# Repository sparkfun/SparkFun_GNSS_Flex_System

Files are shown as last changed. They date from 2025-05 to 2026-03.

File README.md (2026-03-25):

SparkFun GNSS Flex System
========================================

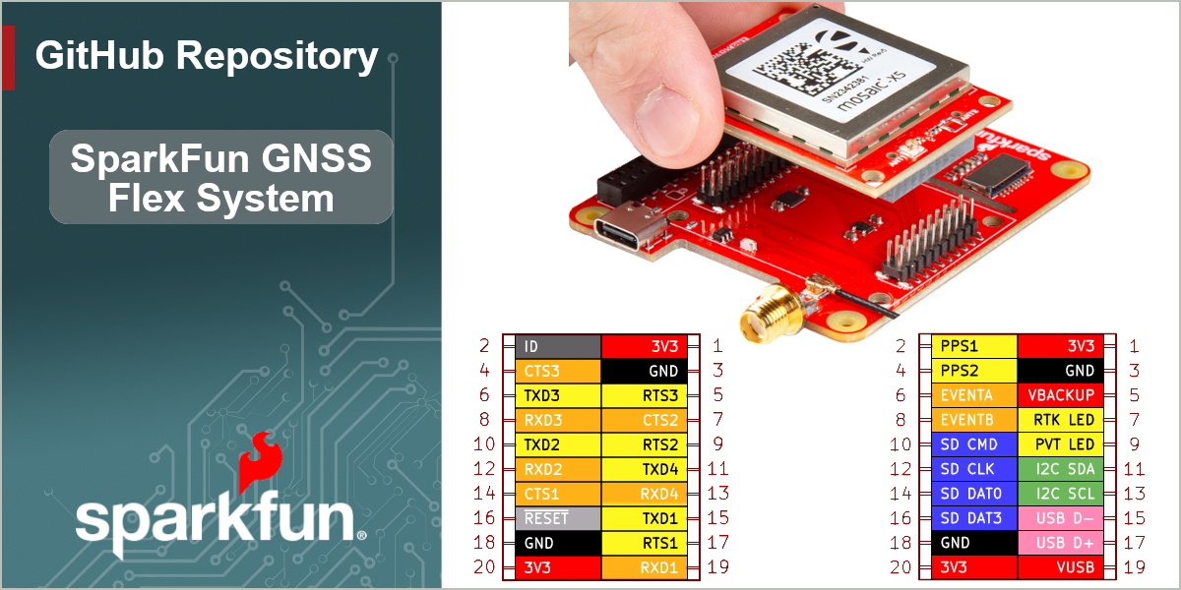
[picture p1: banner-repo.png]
SparkFun GNSS Flex System


Our GNSS Flex system is designed to be modular with two board types:

- *Plug-in Modules*

    Each SparkPNT GNSS Flex module features a different GNSS receiver. These boards breakout the various interfaces of a GNSS receiver to the standardized pin configuration for the female headers of the GNSS Flex system. This allows users to easily repair and upgrade their system's GNSS receiver.

- *Carrier Boards*

    These boards host GNSS Flex modules on the standardized male headers of the GNSS Flex system. Their designs usually have a specific intention; such as a breakout board, Raspberry Pi pHAT, SparkPNT product line, etc.

The entire ecosystem is centered around two 2x10-pin, 2mm pitch headers that mate the two types of boards. A standardized pin layout, keeps the ecosystem pin-compatible for upgrades and allows board to be easily swapped for repairs. Depending on the capabilities of the GNSS receiver, these pins will breakout the USB, UART (x4), I<sup>2</sup>C, and SD card interfaces along with any PPS or event signals of the GNSS receiver.

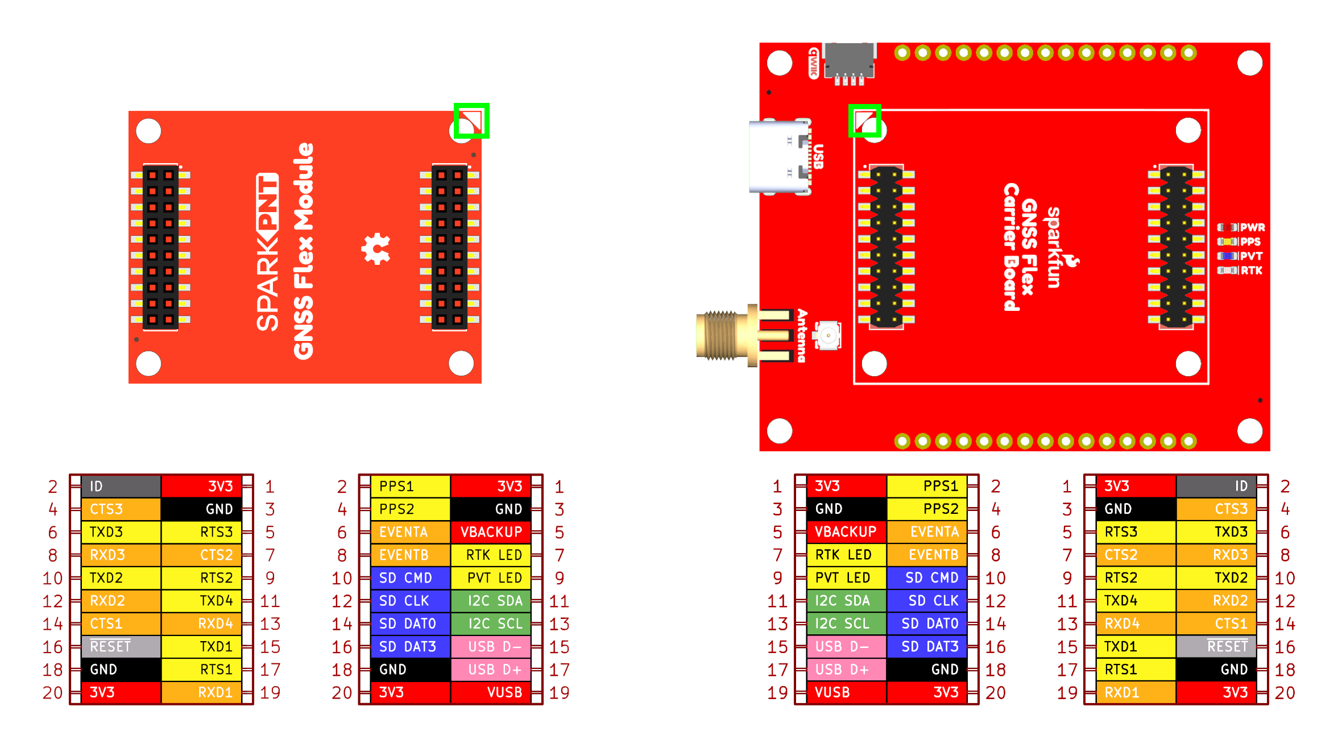
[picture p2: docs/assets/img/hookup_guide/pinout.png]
Pin Layout for the GNSS Flex System


> [!IMPORTANT]
> Depending on the SparkPNT GNSS Flex module, these product will likely require an external antenna:
>
> - Be sure to check out the hookup guide for more information on the GNSS Flex module.
> - Users can also find [GNSS Antennas](https://www.sparkfun.com/gnss/gnss-antennas.html) in our catalog.
>
> Users will have two options for connecting an external GNSS antenna to their GNSS receiver.
>
> - The GNSS Flex modules will usually come with a U.FL connector for an external antenna.
> - For a sturdier connection, a SMA connector on a *carrier board* can utilized. Users can simply jumper the U.FL connectors between the SparkPNT GNSS Flex module and the *carrier board* with a short U.FL cable.

Documentation
--------------

- **[Hookup Guide (mkdocs)](http://docs.sparkfun.com/SparkFun_GNSS_Flex_System/)** - A hookup guide for the entire ecosystem of SparkFun GNSS Flex carrier boards and SparkPNT GNSS Flex modules, hosted by GitHub pages.<br>
   

Repository Contents
-------------------

- **[/docs](/docs/)** - Online documentation files
  - [/assets](/docs/assets/) - Assets files
    - [/component_documentation](/docs/assets/component_documentation/) - Datasheets for GNSS Flex system's standards
    - [/img/hookup_guide](/docs/assets/img/hookup_guide/) - Images for hookup guide documentation
- [/flex_boards](/flex_boards/)
  - /`<name>` - GNSS Flex board *(or associated GitHub submodule)*
    - /docs - Documentation files for the board
      - /assets - Assets files for the board
        - /3d_model - 3D models for the board
        - /board_files - Design files for the board
          - `kicad_files.zip` - KiCad files for the board
          - `schematic.pdf` - Schematic for the board
          - `dimensions.pdf` - Dimensions for the board
        - /component_documentation - Datasheets for the board
        - /img/hookup_guide - Hookup guide images for the board
    - /hardware - Hardware design files (.brd, .sch)
      - /production - Production files

Product Variants
----------------

- GNSS Modules:
  - GNSS Module *(only)*:
    - [GPS-28138](https://www.sparkfun.com/sparkpnt-gnss-flex-module-mosaic-x5.html) - Septentrio mosaic-X5 GNSS Flex module
    - [GPS-28139](https://www.sparkfun.com/sparkpnt-gnss-flex-module-lg290p.html) - Quectel LG290P GNSS Flex module
    - [GPS-29061](https://www.sparkfun.com/sparkpnt-gnss-flex-module-dan-f10n.html) - u-blox DAN-F10N GNSS Flex module
    - [GPS-29362](https://www.sparkfun.com/sparkpnt-gnss-flex-module-zed-x20p.html) - u-blox ZED-X20P GNSS Flex module
    - [GPS-28870](https://www.sparkfun.com/sparkpnt-gnss-flex-module-lg580p.html) - Quectel LG580P GNSS Flex module
  - GNSS Module w/ IMU:
    - [GPS-29469](https://www.sparkfun.com/sparkpnt-gnss-flex-module-lg290p-im19-imu.html) - Quectel LG290P GNSS Flex module + IM19 IMU
    - [GPS-28997](https://www.sparkfun.com/sparkpnt-gnss-flex-module-zed-x20p-im19-imu.html) - u-blox ZED-X20P GNSS Flex module + IM19 IMU
    - [GPS-29457](https://www.sparkfun.com/sparkpnt-gnss-flex-module-mosaic-x5-im19-imu.html) - Septentrio mosaic-X5 GNSS Flex module + IM19 IMU
- Carrier Boards:
  - [GPS-28137](https://www.sparkfun.com/sparkfun-gnss-flex-phat.html) - GNSS Flex pHAT
  - [GPS-28962](https://www.sparkfun.com/sparkfun-gnss-flex-breakout.html) - GNSS Flex Breakout Board
- Kits:
  - pHAT + GNSS Module *(only)*:
    - [GPS-28766](https://www.sparkfun.com/sparkfun-gnss-flex-phat-mosaic-x5.html) - GNSS Flex pHAT w/ the Septentrio mosaic-X5 GNSS Flex module
    - [GPS-28929](https://www.sparkfun.com/sparkfun-gnss-flex-phat-lg290p.html) - GNSS Flex pHAT w/ the Quectel LG290P GNSS Flex module
    - [GPS-29491](https://www.sparkfun.com/sparkfun-gnss-flex-phat-dan-f10n.html) - GNSS Flex pHAT w/ the u-blox DAN-F10N GNSS Flex module
    - [GPS-29887](https://www.sparkfun.com/sparkfun-gnss-flex-phat-zed-x20p.html) - GNSS Flex pHAT w/ the u-blox ZED-X20P GNSS Flex module
    - [GPS-29890](https://www.sparkfun.com/sparkfun-gnss-flex-phat-lg580p.html) - GNSS Flex pHAT w/ the Quectel LG580P GNSS Flex module
  - pHAT + GNSS Module w/ IMU:
    - [GPS-29891](https://www.sparkfun.com/sparkfun-gnss-flex-phat-lg290p-im19-imu.html) - GNSS Flex pHAT w/ the Quectel LG290P GNSS Flex module + IM19 IMU
    - [GPS-29888](https://www.sparkfun.com/sparkfun-gnss-flex-phat-zed-x20p-im19-imu.html) - GNSS Flex pHAT w/ the u-blox ZED-X20P GNSS Flex module + IM19 IMU
    - [GPS-29889](https://www.sparkfun.com/sparkpnt-gnss-flex-phat-mosaic-x5-im19-imu.html) - GNSS Flex pHAT w/ the Septentrio mosaic-X5 GNSS Flex module + IM19 IMU

Version History
---------------

- [r2025-08](https://github.com/sparkfun/SparkFun_GNSS_Flex_System/releases/tag/r2025-08) - Initial Release
- [r2025-08a](https://github.com/sparkfun/SparkFun_GNSS_Flex_System/releases/tag/r2025-08a) - Docs Update
- [r2025-09](https://github.com/sparkfun/SparkFun_GNSS_Flex_System/releases/tag/r2025-09) - Adds DAN-F10N, ZED-X20P, and LG290P (w/ IMU) GNSS Flex modules
- [r2025-09a](https://github.com/sparkfun/SparkFun_GNSS_Flex_System/releases/tag/r2025-09a) - Adds GNSS Flex Breakout board and Docs Updates
- [r2025-10](https://github.com/sparkfun/SparkFun_GNSS_Flex_System/releases/tag/r2025-10) - Adds LG580P GNSS Flex module and Docs Updates
- [r2025-10a](https://github.com/sparkfun/SparkFun_GNSS_Flex_System/releases/tag/r2025-10a) - Adds mosaic-X5 w/ IMU GNSS Flex module
- [r2025-10b](https://github.com/sparkfun/SparkFun_GNSS_Flex_System/releases/tag/r2025-10b) - Docs Updates and ZED-X20P Firmware Update

> [!NOTE]
>
> The format of the release tag  `r[year]-[month][iteration]`
>
> - **year:** `YYYY` Format
> - **month:** `MM` Format
> - **iteration:** Revisions for that month *(i.e. `none`, `a`, `b`, etc.)*

License Information
-------------------

This product is ***open source***!

Please review the [`LICENSE.md`](./LICENSE.md) file for license information.

If you have any questions or concerns about licensing, please contact technical support on our [SparkFun forums](https://community.sparkfun.com/c/community/general-chit-chat/37).

Distributed as-is; no warranty is given.

- Your friends at SparkFun.

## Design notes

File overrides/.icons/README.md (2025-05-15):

.icons directory
====================
This folder should contain branding logos for the product documentation

## General Images
- `sfe.svg` - SparkFun flame logo
- `kicad-primary.svg` - Full KiCad logo

## Directory
- `logo` - Other available logos

## SVG Optimizer
- [Remove meta data from svg](https://jakearchibald.github.io/svgomg/)

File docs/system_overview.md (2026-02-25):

<!-- Import the component -->
<script type="module" src="https://ajax.googleapis.com/ajax/libs/model-viewer/4.0.0/model-viewer.min.js"></script>

## GNSS Flex System
The GNSS Flex system is designed to be modular with a standardized pin layout that keeps the ecosystem pin-compatible for upgrades and allows boards to be easily swapped for repairs. The ecosystem is comprised of two boards, which mate through two 2x10-pin, 2mm pitch headers. The **SparkPNT GNSS Flex modules** function as *plug-in* boards that feature different GNSS receivers. They are designed to mate with **GNSS Flex** *carrier* **boards** for various purposes; such as a breakout board, Raspberry Pi pHAT, SparkPNT product line, etc.

<div class="grid" markdown>

<div markdown>

<figure markdown>
<model-viewer alt="Utilizing the GNSS Flex System" src="../assets/3d_model/GNSS_Flex-Stack_Animation.glb" poster="../assets/img/hookup_guide/animation-attach_module.gif" camera-controls autoplay tone-mapping="neutral" shadow-intensity="2" shadow-softness="0.2" camera-orbit="0deg 70deg 16.7m" field-of-view="18deg" camera-target="2.93m 1.16m -1.29m" style="width: 500px; height: 300px;">
</model-viewer>
<figcaption markdown>Attaching a GNSS Flex module to a GNSS Flex *carrier* board.</figcaption>
</figure>

</div>

<div markdown>

!!! tip "Manipulate 3D Model"
	<article style="text-align: center;" markdown>

	| Controls       | Mouse                    | Touchscreen    |
	| :------------- | :----------------------: | :------------: |
	| Zoom           | Scroll Wheel             | 2-Finger Pinch |
	| Rotate         | ++"Left-Click"++ & Drag  | 1-Finger Drag  |
	| Move/Translate | ++"Right-Click"++ & Drag | 2-Finger Drag  |

	</article>

</div>

</div>

### Board Variants
Below, are two generic examples of a GNSS Flex *module* and *carrier* board.

<div class="grid cards" align="center" markdown>

-   **GNSS Flex Module**

	---

	<model-viewer src="../assets/3d_model/GNSS_Flex-Generic_Module.glb" camera-controls poster="../assets/3d_model/poster-generic_module.png" tone-mapping="neutral" shadow-intensity="2" shadow-softness="0.2" camera-orbit="0deg 75deg 0.1623m" field-of-view="12deg" style="width: 100%; height: 250px;">
	</model-viewer>

	<article style="text-align: center;" markdown>
	[See All GNSS Flex Module Variants](modules.md){ .md-button .md-button--primary }
	</article>

-   **GNSS Flex *"Carrier"* Board**

	---

	<model-viewer src="../assets/3d_model/GNSS_Flex-Carrier_Board.glb" camera-controls poster="../assets/3d_model/poster-carrier_board.png" tone-mapping="neutral" shadow-intensity="2" shadow-softness="0.2" camera-orbit="0deg 75deg 0.1781m" field-of-view="15deg" style="width: 100%; height: 250px;">
	</model-viewer>

	<article style="text-align: center;" markdown>
	[See All GNSS Flex *Carrier* Board Variants](carriers.md){ .md-button .md-button--primary }
	</article>

</div>

### Ecosystem Boards
Below, are all the available GNSS Flex boards in our ecosystem.

<div class="grid cards" markdown>

--8<-- "./modules.md:12:69"

--8<-- "./modules.md:79:176"

--8<-- "./carriers.md:9:36"

</div>

---

## Section Topics
This guide is divided into three sections:

- The **Ecosystem Overview** section describes the overall GNSS Flex system and its primary components.
- The **GNSS Flex Modules** and **Carrier Boards** sections detail each of the specific boards in the ecosystem and how they operate.
- In the **Resources and Support** sections, users can find the design files (KiCad files & schematic), relevant documentation (datasheets, white papers, etc.) and other helpful links on the [Resources page](./resources.md). Lastly, the [Troubleshooting page](./troubleshooting_tips.md) includes helpful tips and instructions for how to receive technical support from SparkFun.

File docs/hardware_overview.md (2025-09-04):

## Board Layout

The boards of the GNSS Flex system have the following features:

<div class="grid" markdown>

<div markdown>

<figure markdown>
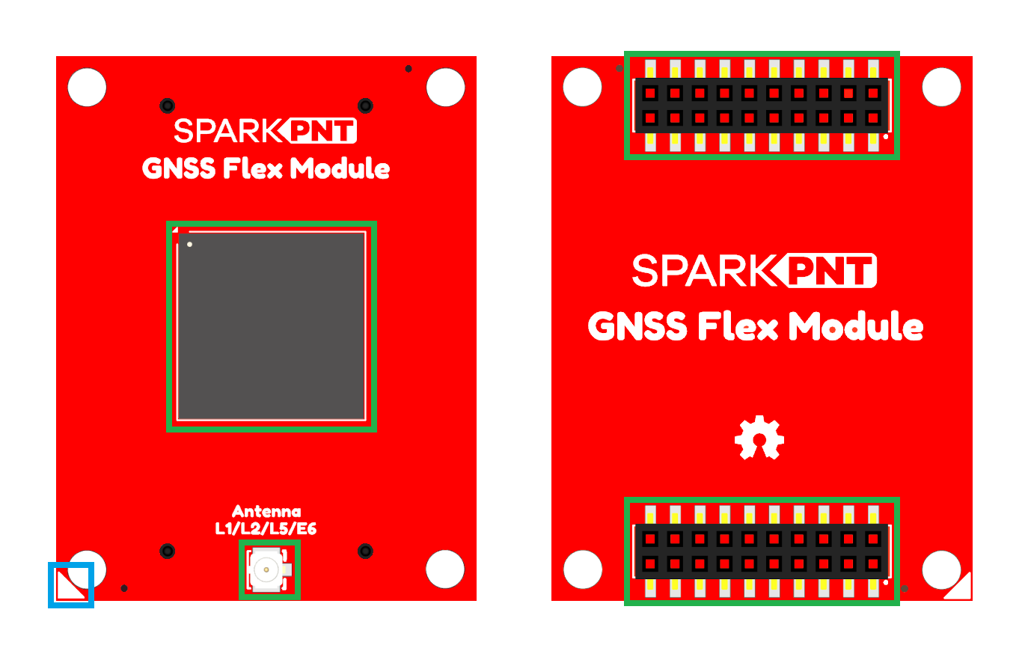
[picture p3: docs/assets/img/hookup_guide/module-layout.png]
Board Layout for the GNSS Flex Module

<figcaption markdown>Layout of the major components on the GNSS Flex modules.</figcaption>
</figure>

1. **Alignment Indicator**
:	A small triangle at the corner of the board is used to indicate the board's alignment on the *carrier* board.
1. **GNSS Receiver**
:	Each variant of the SparkPNT GNSS Flex modules features a unique GNSS receiver.
1. **U.FL Connector**
:	The primary interface for connecting an external GNSS antenna. *(Some GNSS modules may come packaged with a built-in ceramic antenna.)*
1. **GNSS Flex Female Headers**
:	The GNSS Flex system is designed around two 2x10-pin, 2mm pitch headers used mate the two types of boards. A standardized pin layout, keeps the ecosystem pin-compatible for upgrades and allows board to be easily swapped for repairs. Depending on the capabilities of the GNSS receiver, these pins will breakout the USB, UART (x4), I^2^C, and SD card interfaces along with any PPS or event signals of the GNSS receiver.

</div>

<div markdown>

<figure markdown>
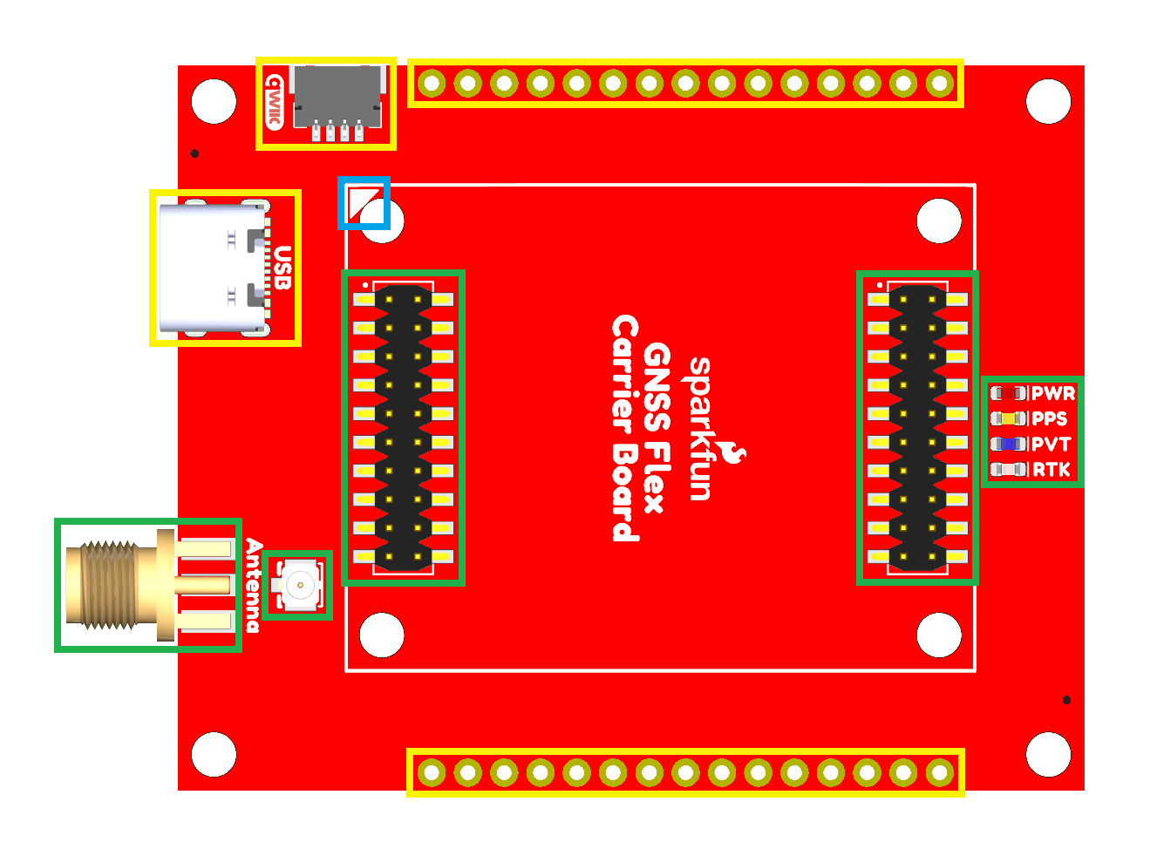
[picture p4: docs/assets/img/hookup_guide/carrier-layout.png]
Board Layout for the carrier board

<figcaption markdown>Layout of the major components of GNSS Flex *carrier* boards.</figcaption>
</figure>

1. **Alignment Indicator**
: A small triangle in the corner of the GNSS Flex system's mating area is used to indicate the alignment for a GNSS Flex module on the *carrier* board.
1. **SMA Connector**
:	A more robust interface for connecting an external GNSS antenna to the GNSS Flex system. The signal is isolated and passed-through to the U.FL connector on the *carrier* board.
1. **U.FL Connector**
:	The signal for this connector is isolated and passed-through to the SMA connector on the *carrier* board. It is used for bridging the external antenna connection of the U.FL connector on GNSS Flex module to the SMA connector on the *carrier* board.
1. **GNSS Flex Male Headers**
:	The *carrier* boards host GNSS Flex modules on the two 2x10-pin, 2mm pitch male headers. A standardized pin layout, keeps the ecosystem pin-compatible for upgrades and allows board to be easily swapped for repairs. Depending on the capabilities of the GNSS receiver, these pins will breakout the USB, UART (x4), I^2^C, and SD card interfaces along with any PPS or event signals of the GNSS receiver.
1. **Status LED**
:	Often *carrier* boards will include status LEDs to indicate the board is powered, the RTK status, a PPS signal, and a GNSS fix.
1. **Other Features**
:	 The designs of the *carrier* boards usually have a specific purpose; therefore, they will often include other features. *(For more details, users can refer to the hardware information of the board they are interested in.)*

</div>

</div>

## Header Pins
The GNSS Flex ecosystem is designed around two 2x10-pin, 2mm pitch headers used mate the two board types. Depending on the capabilities of the GNSS receiver on the GNSS Flex module, these pins breakout the USB, UART (x4), I^2^C, and SD card interfaces along with any PPS or event signals of the GNSS receiver.

<figure markdown>
Pin Layout - Flex Boards
<figcaption markdown>The pin layout of the headers on the GNSS Flex boards; with each board's mating alignment highlighted in green.</figcaption>
</figure>

## U.FL Connectors
Depending on the SparkPNT GNSS Flex module,	users will have two options for connecting an external GNSS antenna to their GNSS receiver.

- The GNSS Flex modules will usually come with a U.FL connector for external antenna.
- For a more robust interface, the GNSS Flex *carrier* boards will usually come with a U.FL connector that is bridged to a nearby SMA edge connector. Users simply need to jumper the U.FL connectors between the SparkPNT GNSS Flex module and the *carrier* board with a short U.FL cable.

<figure markdown>
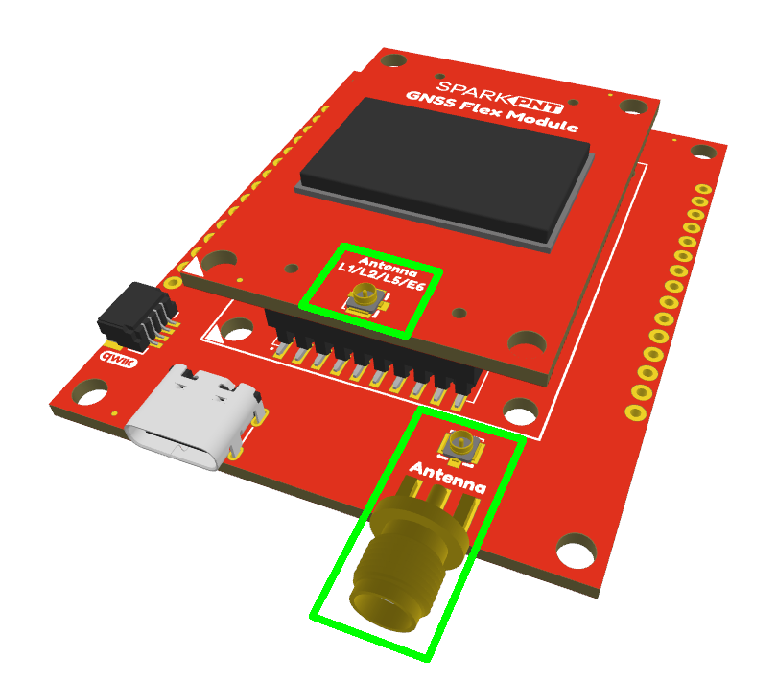
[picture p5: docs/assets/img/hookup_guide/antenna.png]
Antenna connection

<figcaption markdown>Bridging the U.FL connections to utilize the SMA connector on a *carrier* board.</figcaption>
</figure>

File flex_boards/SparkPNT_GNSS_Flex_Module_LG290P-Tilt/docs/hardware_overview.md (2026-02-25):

<article style="text-align: center;" markdown>
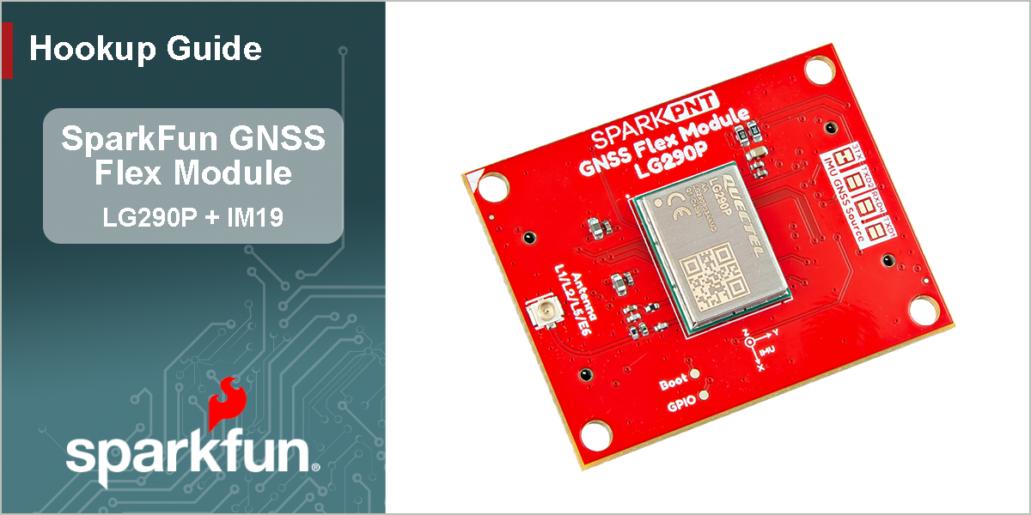
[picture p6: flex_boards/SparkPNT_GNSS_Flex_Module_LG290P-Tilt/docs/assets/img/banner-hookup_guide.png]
Banner

</article>

## Introduction

<div class="grid cards desc" markdown>

-   <a href="https://www.sparkfun.com/sparkpnt-gnss-flex-module-lg290p-im19-imu.html">
	**SparkPNT GNSS Flex Module - LG290P & IM19 IMU**<br>
	**SKU:** GPS-29469

	---

	<figure markdown>
	Product Thumbnail
	</figure></a>

	<article style="text-align: center;" markdown>
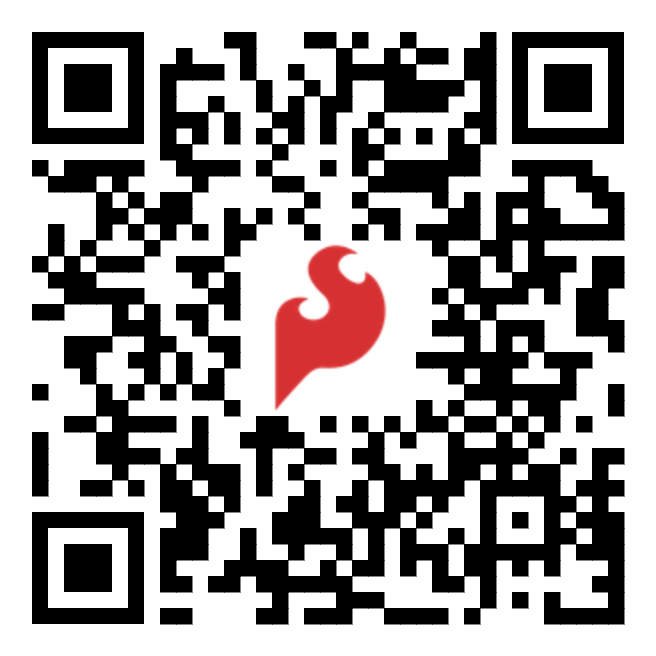
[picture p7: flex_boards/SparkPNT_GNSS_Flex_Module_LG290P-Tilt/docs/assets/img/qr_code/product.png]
QR code to product page
	
	[Purchase from SparkFun :fontawesome-solid-cart-plus:{ .heart }](https://www.sparkfun.com/sparkpnt-gnss-flex-module-lg290p-im19-imu.html){ .md-button .md-button--primary }
	</article>

	??? info "Tilt Compensation"
		The IM19 attitude module from Feyman (FMI) fuses MEMS IMU sensor data and GNSS RTK positioning to deliver high-precision attitude compensated measurements, with roll and pitch accurate to within 0.05 degrees. This kind of superb accuracy has widespread uses in industrial applications such as tilt RTK surveys (where RTK poles need not be held straight vertical as the IM19 can calculate a virtual digital level at any tilt angle), agriculture machine automation, and dead reckoning.

		When configured, fed with the LG290P Pulse-Per-Second signal and NMEA GGA, RMC, and GST messages; once calibrated, the IM19 will output proprietary NMEA messages containing the compensated position and roll, pitch and yaw. By default, the LG290P `COM3` `TX` is linked to the IM19 `UART2` `RX` to carry the required NMEA messages. However, this can be changed via jumper links on the Flex Module, if necessary.

-   SparkPNT GNSS Flex modules are plug-in boards featuring different GNSS receivers. They are designed to be easily swapped for repairs and pin-compatible for upgrades. The boards have two 2x10-pin, 2mm pitch female headers connecting to carrier boards. For the LG290P GNSS receiver, these pins will break out the UART (x2) and I^2^C* interfaces, along with the PPS and event signals using a standardized pinout. Additionally, these pins break out the two UART interfaces of the IM19 IMU.

	This SparkPNT GNSS Flex module combines the Quectel LG290P GNSS receiver with the IM19 Inertial Measurement Unit for tilt compensation or dead reckoning. The LG290P module is a quad-band, multi-constellation, high-precision, RTK GNSS receiver. The module can simultaneously receive signals from the `L1`, `L2`, `L5`, and `L6`/`E6` frequency bands of the GPS, GLONASS, Galileo, BDS, QZSS, and NavIC GNSS constellations. In addition, the module supports SBAS augmentation systems (WASS, EGNOS, BDSBAS, MSAS, GAGAN, and SDCM), PPP services* (BDS PPP-B2b, QZSS CLAS, MADOCA-PPP, and Galileo HAS), RTCM, and RTK corrections for precision navigation with a fast convergence time and reliable performance.

	The built-in NIC anti-jamming unit provides professional-grade interference signal detection and elimination algorithms, effectively mitigating multiple narrow-band interference sources and significantly improving signal reception performance in complex electromagnetic environments. Additionally, the embedded algorithms ensure reliable positioning in complex scenarios such as urban environments and deep tree cover.

	!!! warning "Features Under Development"
		- **I^2^C/SPI** - Currently, only the UART interface is supported by the module.
		- **PPP Services** - Corrections for some of the PPP services have not been implemented.

</div>

## :material-folder-cog: Design Files

<!-- Import the component -->

<script type="module" src="https://ajax.googleapis.com/ajax/libs/model-viewer/4.0.0/model-viewer.min.js"></script>

<div class="grid cards desc" markdown>

-   :kicad-primary:{ .enlarge-logo } Design Files

	---

	- :fontawesome-solid-file-pdf: [Schematic](./assets/board_files/schematic.pdf)
	- :material-folder-zip: [KiCad Files](./assets/board_files/kicad_files.zip)
	- :material-rotate-3d: [STEP File](./assets/3d_model/cad_model.step)
	- :fontawesome-solid-file-pdf: [Board Dimensions](./assets/board_files/dimensions.pdf):
		- 1.75" x 1.25" (44.45mm x 31.75mm)

-   <!-- Boxes in tabs -->

	=== "3D Model"
		<article style="text-align: center;" markdown>
		<model-viewer src="../assets/3d_model/web_model.glb" camera-controls poster="../assets/3d_model/poster.png" tone-mapping="neutral" shadow-intensity="2" shadow-softness="0.2" camera-orbit="90deg 75deg 0.103m" field-of-view="25.11deg" style="width: 100%; height: 450px;">
		</model-viewer>

		[Download the `*.step` File](./assets/3d_model/cad_model.step "Click to download"){ .md-button .md-button--primary width="250px" }

		</article>

		???+ tip "Manipulate 3D Model"
			<article style="text-align: center;" markdown>

			| Controls       | Mouse                    | Touchscreen    |
			| :------------- | :----------------------: | :------------: |
			| Zoom           | Scroll Wheel             | 2-Finger Pinch |
			| Rotate         | ++"Left-Click"++ & Drag  | 1-Finger Drag  |
			| Move/Translate | ++"Right-Click"++ & Drag | 2-Finger Drag  |

			</article>

	=== "Dimensions"
		<article style="text-align: center;" markdown>
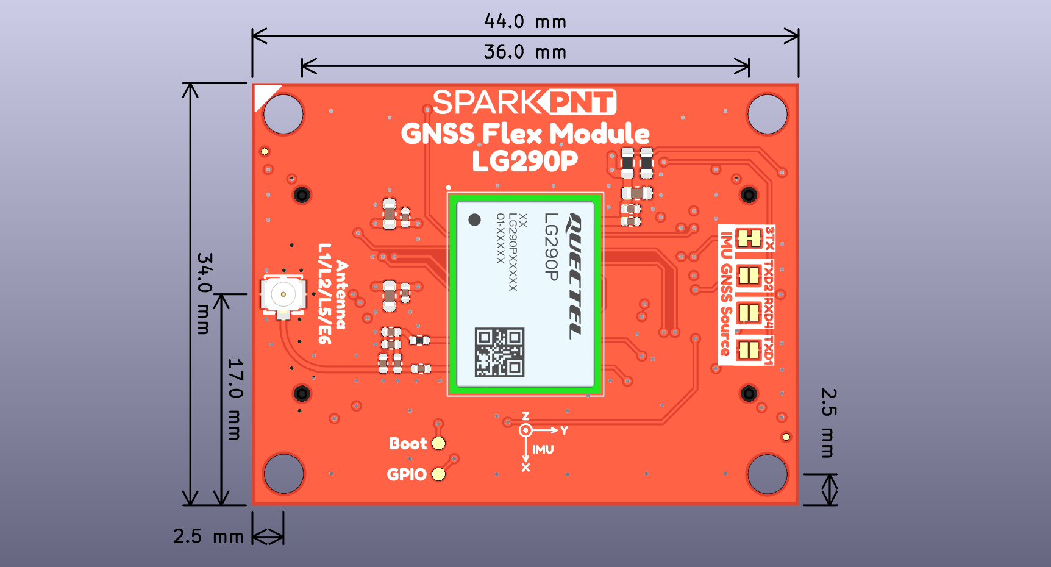
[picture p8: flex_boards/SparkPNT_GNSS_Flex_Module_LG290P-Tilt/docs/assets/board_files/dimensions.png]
Board Dimensions
		
		<figcaption markdown>Dimensions of the LG290P GNSS Flex module.</figcaption>
		</article>

		???+ tip "Need more measurements?"
			For more information about the board's dimensions, users can download the [KiCad files](./assets/board_files/kicad_files.zip) for this board. These files can be opened in KiCad and additional measurements can be made with the measuring tool.

			!!! info ":octicons-download-16:{ .heart } KiCad - Free Download!"
				KiCad is free, open-source [CAD]("computer-aided design") program for electronics. Click on the button below to download their software. *(\*Users can find out more information about KiCad from their [website](https://www.kicad.org/).)*

				<article style="text-align: center;" markdown>
				[Download :kicad-primary:{ .enlarge-logo }](https://www.kicad.org/download/ "Go to downloads page"){ .md-button .md-button--primary width="250px" }
				</article>

			???+ info ":straight_ruler: Measuring Tool"
				This video demonstrates how to utilize the dimensions tool in KiCad, to include additional measurements:

				<article class="video-500px" style="text-align: center; margin: auto;" markdown>
				<iframe src="https://www.youtube.com/embed/-eXuD8pkCYw" title="KiCad Dimension Tool" frameborder="0" allow="accelerometer; autoplay; clipboard-write; encrypted-media; gyroscope; picture-in-picture" allowfullscreen></iframe>
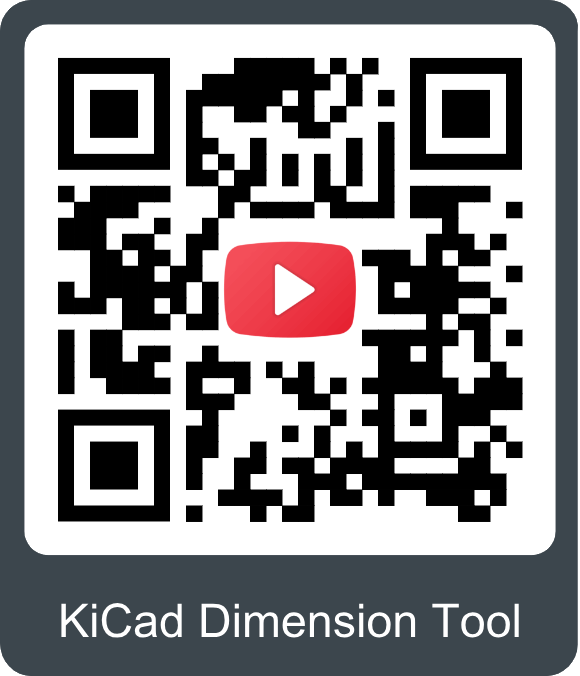
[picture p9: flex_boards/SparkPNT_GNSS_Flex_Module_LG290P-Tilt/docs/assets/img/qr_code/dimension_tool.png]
QR code to play video
				
				</article>

</div>

## Board Layout
The GNSS Flex system is designed around two 2x10-pin, 2mm pitch headers used mate the two types of boards. A standardized pin layout, keeps the ecosystem pin-compatible for upgrades and allows board to be easily swapped for repairs. Depending on the capabilities of the GNSS receiver, these pins will breakout the USB, UART (x4), I^2^C, and SD card interfaces along with any PPS or event signals of the GNSS receiver.

The LG290P GNSS Flex module has the following features:

<div class="grid" markdown>

<div markdown>

<figure markdown>
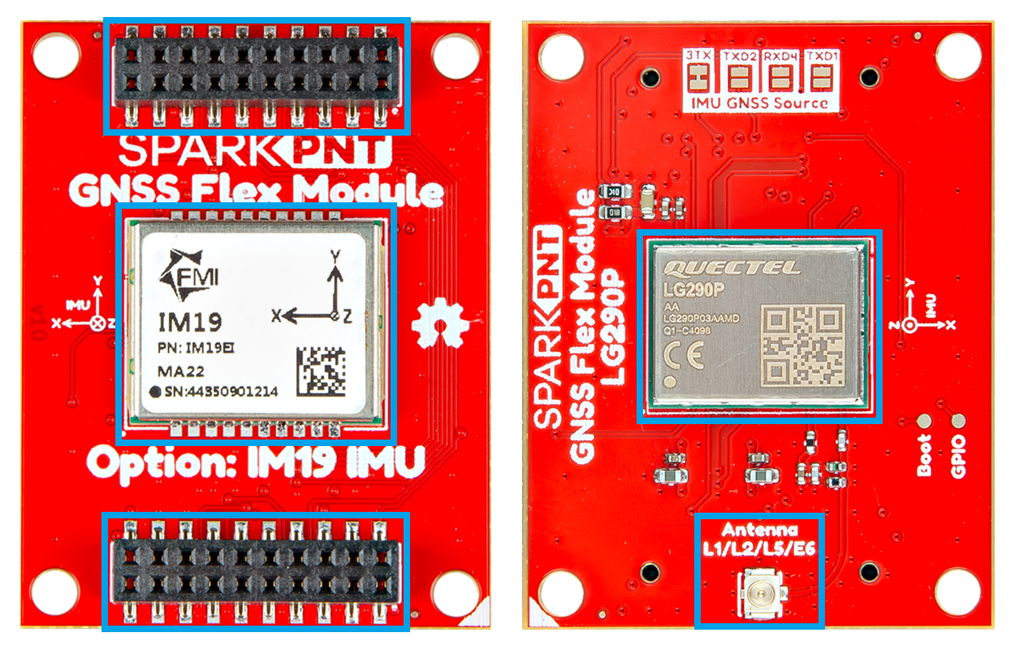
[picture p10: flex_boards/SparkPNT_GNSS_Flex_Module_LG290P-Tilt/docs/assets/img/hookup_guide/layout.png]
Layout

<figcaption markdown>Layout of the major components on the LG290P GNSS Flex module.</figcaption>
</figure>

</div>

<div markdown>

1. **LG290P GNSS Receiver**
:	The Quectel LG290P GNSS receiver
1. **GNSS Flex Headers**
:	Two sets of 2x10 pin, 2mm pitch female headers for connecting a GNSS Flex module to *carrier boards*
1. **IM19 IMU** *(optional)*
:	An optional Feyman IM19 attitude module to provide tilt compensation in surveying applications
1. **`Antenna L1/L2/L5/E6` U.FL Connector**
:	An U.FL connector for attaching an external GNSS antenna

</div>

</div>

## LG290P GNSS Receiver
One of the centerpieces of the GNSS Flex module, is the [LG290P GNSS receiver](./assets/component_documentation/quectel_lg290p03_hardware_design_v1-1.pdf) from [Quectel](https://www.quectel.com/). The LG290P is a low-power, multi-band, multi-constellation GNSS receiver capable of delivering centimeter-level precision at high update rates. The built-in NIC anti-jamming unit provides professional-grade interference signal detection and elimination algorithms, which effectively mitigate against multiple narrow-band interference sources and significantly improves the signal reception performance in complex electromagnetic environments. With its performance advantages of high-precision and power consumption, this board is an ideal choice for high-precision navigation applications, such as intelligent robots, UAVs, precision agriculture, mining, surveying, and autonomous navigation.

<div class="grid cards" markdown>

<div style="text-align: center;" markdown>

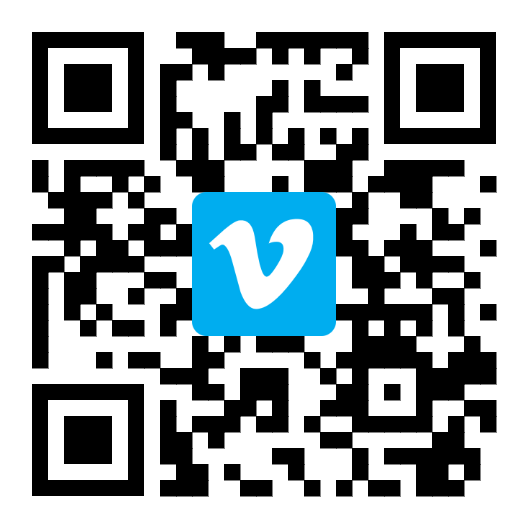
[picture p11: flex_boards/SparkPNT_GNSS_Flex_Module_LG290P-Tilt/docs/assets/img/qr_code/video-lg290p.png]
QR code to product video


<article class="video-500px" style="margin: auto;" markdown>
<iframe src="https://player.vimeo.com/video/1000742664?dnt=1&amp;app_id=122963" title="Quectel: Product Intro for LG290P GNSS Receiver" frameborder="0" allow="accelerometer; autoplay; clipboard-write; encrypted-media; gyroscope; picture-in-picture" allowfullscreen></iframe>
</article>

</div>

-   <figure markdown>
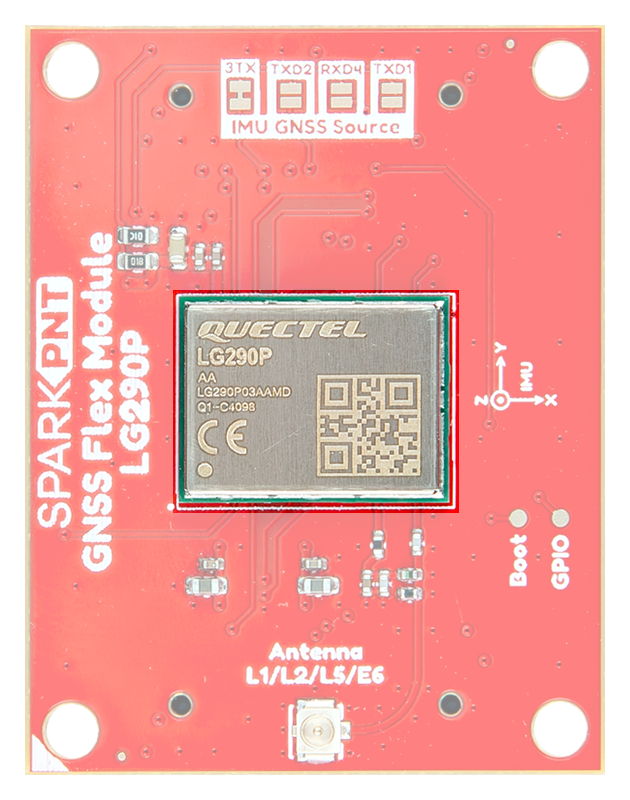
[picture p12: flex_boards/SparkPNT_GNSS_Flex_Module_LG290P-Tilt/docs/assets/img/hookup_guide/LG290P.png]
LG290P GNSS receiver
	
	<figcaption markdown>The LG290P GNSS receiver on the LG290P GNSS Flex module.</figcaption>
	</figure>

</div>

<div class="grid" markdown>

<div markdown>

**Features:**

- Supply Voltage: **3.15–3.45V**
- Tracking Channels: 1040
- Concurrent signal reception: 5 + QZSS
	- `L1`, `L2`, `L5`, `E6` frequency bands
- Sensitivity:
	- Acquisition: -146dBm
	- Tracking: -160dBm
	- Reacquisition: -155dBm
- Antenna Power: External or Internal
- GNSS Constellations and SBAS Systems:
	- **USA:** GPS + WASS
	- **Russia:** GLONASS + SDCM
	- **EU:** Galileo + EGNOS
	- **China:** BDS + BDSDAS
	- **Japan:** QZSS + MSAS
	- **India:** NavIC + GAGAN
- Accuracy of 1PPS Signal: 5ns *(RMS)*
- Update Rate:
	- Default: 10Hz
	- Max: 20Hz

</div>

<div markdown>

<br>

- Time to First Fix *(without AGNSS)*:
	- Cold Start: 28s
	- Warm Start: 28s
	- Hot Start: 1.7s
- RTK Convergence Time: 5s
- Dynamic Performance:
	- Maximum Altitude: 10000m
	- Maximum Velocity: 490m/s
	- Maximum Acceleration: 4g
- Built-in NIC anti-jamming unit
- Interfaces
	- UART (x3)
		- Baud Rate: 9600–3000000bps
			- **Default:** 460800bps
		- Protocol: `NMEA 0183`/`RTCM 3.x`
	- SPI[^1] (x1)
	- I^2^C[^1] (x1)
- Operating temperature: -40&deg;C to +85&deg;C

</div>

</div>

[^1]:
	!!! warning "Feature Under Development"
		Currently, only the UART interface is supported by the module. Support for the **I^2^C** and **SPI** interfaces are still under development.

### Power Consumption
The power consumption of the LG290P GNSS receiver depends on the GNSS signals enabled and the positioning mode.

<div class="grid" markdown>

<article style="text-align: center;" markdown>

| Mode | Power (mW) | Current (mA) |
| :--- | :---: | :---: |
| Acquisition | 300.3 | 91 |
| Tracking | 300.3 | 91 |
| Backup | 39.6 | 0.012 |

</article>

<div markdown>

!!! info "Power Modes"

	**Acquisition:**
	:   Module searches for satellites and to determine visible satellites, coarse frequency, and the code phase of satellite signals

	**Tracking:**
	:   Once acquisition is completed, the module tracks satellites and demodulates the navigation data from specific satellites

	**Backup Mode:**
	:   Reduces power consumption. Only backup domain is active and keeps track of time.

</div>

</div>

### Frequency Bands
The LG290P module is a multi-band, multi-constellation GNSS receiver. Below, is a chart illustrating the frequency bands utilized by all the global navigation satellite systems; along with a list of the frequency bands and GNSS systems supported by the LG290P GNSS receiver.

<figure markdown>
GNSS frequency bands (https://www.tallysman.com/app/uploads/2021/07/Tallysman-GNSS-Frequencies-v8.0_Chart-1-1024x425.png "Click to enlarge")
<figcaption markdown>Frequency bands of the global navigation satellite systems. (Source: [Tallysman](https://www.tallysman.com/gnss-constellations-radio-frequencies-and-signals/))</figcaption>
</figure>

<div class="grid" markdown>

<div markdown>

**Supported Frequency Bands:**

- GPS: `L1 C/A`, `L1C`[^2], `L5`, `L2C`
- GLONASS: `L1`, `L2`
- Galileo: `E1`, `E5a`, `E5b`, `E6`
- BDS: `B1I`, `B1C`, `B2a`, `B2b`, `B2I`, `B3I`
- QZSS: `L1 C/A`, `L1C`[^2], `L5`, `L2C`
- NavIC: `L5`
- SBAS: `L1 C/A`
- L-band PPP[^3]:
	- PPP: `B2b`
	- QZSS: `L6`
	- Galileo HAS: `E6`

</div>

<div markdown>

**Supported GNSS Constellations:**

- GPS (USA)
- GLONASS (Russia)
- Galileo (EU)
- BDS (China)
- QZSS (Japan)
- NavIC (India)

**Supported SBAS Systems:**

- WASS (USA)
- SDCM (Russia)
- EGNOS (EU)
- BDSBAS (China)
- MSAS (Japan)
- GAGAN (India)

</div>

</div>

[^2]:
	!!! warning "Feature Under Development"
		Support for the `L1C` frequency band has not been implemented.
[^3]:
	!!! warning "Feature Under Development"
		Corrections for some of the PPP services have not been implemented.

!!! info
	For a comparison of the frequency bands supported by the LG290P GNSS receivers, refer to sections **1.2**, **1.5**, and **1.6** of the [hardware design manual](./assets/component_documentation/quectel_lg290p03_hardware_design_v1-1.pdf).

	??? info "What are Frequency Bands?"
		A [frequency band](https://en.wikipedia.org/wiki/Frequency_band) is a section of the [electromagnetic spectrum](https://en.wikipedia.org/wiki/Electromagnetic_spectrum), usually denoted by the range of its upper and lower limits. In the [radio spectrum](https://en.wikipedia.org/wiki/Radio_spectrum), these frequency bands are usually regulated by region, often through a government entity. This regulation prevents the interference of RF communication; and often includes major penalties for any interference with critical infrastructure systems and emergency services.

		<figure markdown>
		GNSS frequency bands (https://gssc.esa.int/navipedia/images/c/cf/GNSS_All_Signals.png "Click to enlarge")
		<figcaption markdown>Frequency bands of the global navigation satellite systems. (Source: [ESA](https://gssc.esa.int/navipedia/index.php?title=File:GNSS_All_Signals.png "European Space Agency"))</figcaption>
		</figure>

		However, if the various GNSS constellations share similar frequency bands, then how do they avoid interfering with one another? Without going too far into detail, the image above helps illustrate some of the characteristics, specific to the frequency bands of each system. With these characteristics in mind, along with other factors, the chart can help users to visualize how multiple GNSS constellations might co-exist with each other.

		For more information, users may find these articles of interest:

		- [GNSS signal](https://gssc.esa.int/navipedia/index.php/GNSS_signal)
		- [GPS Signal Plan](https://gssc.esa.int/navipedia/index.php?title=GPS_Signal_Plan)
		- [GLONASS Signal Plan](https://gssc.esa.int/navipedia/index.php?title=GLONASS_Signal_Plan)
		- [GALILEO Signal Plan](https://gssc.esa.int/navipedia/index.php?title=GALILEO_Signal_Plan)

### Position Accuracy

<div class="grid" markdown>

<div markdown>

The accuracy of the position reported from the LG290P GNSS receiver, can be improved based upon the correction method being employed. Currently, [RTK](https://en.wikipedia.org/wiki/Real-time_kinematic_positioning "Real-Time Kinematic") corrections provide the highest level of accuracy; however, users should be aware of certain limitations of the system:

- RTK technique requires real-time correction data from a reference station or network of base stations.
	- RTK corrections usually come from RTCM messages that are signal specific *(i.e. an RTK network may only provide corrections for specific signals; only `E5b` and not `E5a`)*.
- The range of the base stations will vary based upon the method used to transmit the correction data.
- The reliability of RTK corrections are inherently reduced in [multipath environments](https://en.wikipedia.org/wiki/Multipath_propagation).

</div>

<div markdown>

<article style="text-align: center;" markdown>

| Correction Method | Horizontal | Vertical | Velocity |
| :--- | :---: | :---: | :---: |
| Standalone | 0.7m<br>~2.3' | 2.5m<br>~8.2' | 3cm/s (0.108kph)<br>~1.2in/s (0.067mph) |
| RTK | **0.8cm** *(+1ppm)*<br>~0.3" | 1.5cm *(+1ppm)*<br>~.6" | |

</article>

??? warning "IM19 Attitude Module"
	When configured and calibrated, the IM19 attitude module can fuses IMU sensor and GNSS RTK positioning data to deliver compensated position. The accuracy, displayed in the table below, should also be considered when implemented.

	<article style="text-align: center;" markdown>

	| Tilt Angle       | Accuracy |
	| :--------------: | :------: |
	| 0&deg; - 30&deg; | 1cm      |
	| <60&deg;         | 2cm      |

	</article>

</div>

</div>

??? info "RTK Corrections"
	To understand how RTK works, users will need a more fundamental understanding of the signal error sources.

	<div class="grid cards" markdown align="center">

	-   <a href="https://www.sparkfun.com/news/7533">
		<figure markdown>
		Tutorial Thumbnail
		</figure>

		---

		**Real-Time Kinematics Explained**</a>

	-   <a href="https://www.sparkfun.com/news/7138">
		<figure markdown>
		Tutorial Thumbnail
		</figure>

		---

		**What is Correction Data?**</a>

	-   <a href="https://www.septentrio.com/en/learn-more/insights/gnss-corrections-demystified">
		<figure markdown>
		Tutorial Thumbnail
		</figure>

		---

		**GNSS Corrections Demystified**</a>

	</div>

!!! tip
	For the best performance, we highly recommend that users configure the module to utilize/provide RTK corrections with a compatible L1/L2/L5/L6 GNSS antenna and utilize a low-loss cable.

## IM19 IMU *(Optional)*
The other centerpiece of the GNSS Flex module is the [IM19 attitude module](../assets/component_documentation/IM19EI_v1.4.1.pdf) from [Feyman Inc.](http://feymani.com/en/), which fuses MEMS sensor and GNSS RTK positioning data to deliver high-precision attitude measurement, with roll and pitch accurate to within 0.05 degrees. This kind of superb accuracy has widespread uses in industrial applications such as tilt RTK surveys (where RTK poles need not be held straight vertical as the IM19 can calculate a virtual digital level at any tilt angle), agriculture machine automation, and dead reckoning.

When configured, fed with the LG290P Pulse-Per-Second signal and NMEA GGA, RMC, and GST messages; once calibrated, the IM19 will output proprietary NMEA messages containing the compensated position and roll, pitch and yaw. By default, the LG290P `COM3` `TX` is linked to the IM19 `UART2` `RX` to carry the required NMEA messages. However, this can be changed via jumper links on the Flex Module, if necessary.

<div class="grid cards" markdown>

<div style="text-align: center;" markdown>

<article class="video-500px" style="text-align: center; margin: auto;" markdown>
<iframe src="https://global.feymani.com/files/im19.mp4" type="video/mp4" title="Feyman Inc - Product Intro for IM19 Module" frameborder="0" allow="accelerometer; clipboard-write; encrypted-media; gyroscope; picture-in-picture" allowfullscreen></iframe>
</article>

</div>

-   <figure markdown>
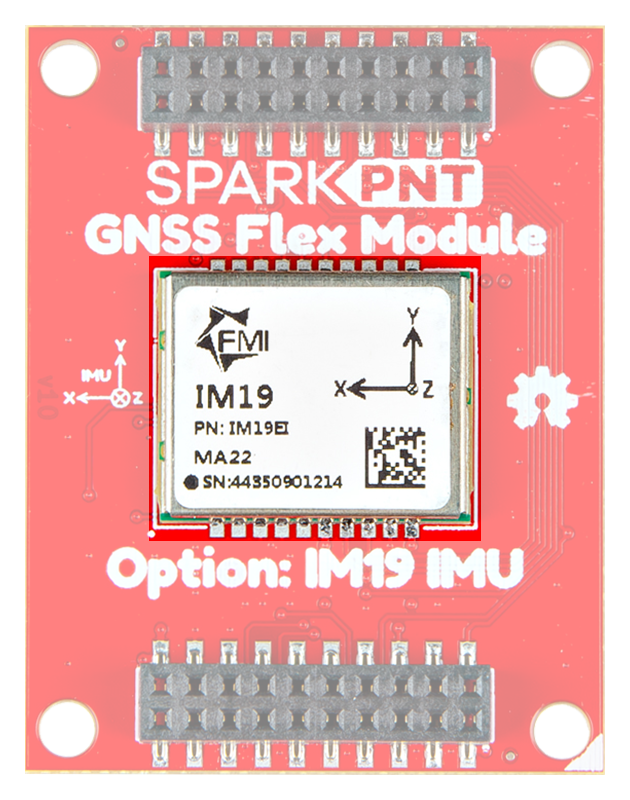
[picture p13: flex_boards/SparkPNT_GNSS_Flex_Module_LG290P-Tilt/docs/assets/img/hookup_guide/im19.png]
IM19 attitude module
	
	<figcaption markdown>The IM19 attitude module on the LG290P GNSS Flex module.</figcaption>
	</figure>

</div>

<div class="grid" markdown>

<div markdown>

**Features:**

- Self-calibration Technique
- Initialization: <2s
- Power: 0.33W
- Data Rate: 100Hz
- Attitude Accuracy: &plusmn;0.05&deg; *(Pitch/Roll)*
- Heading Accuracy: &plusmn;0.5&deg; *(Yaw)*

</div>

<div markdown>

<br>

- Gyroscope
	- Bias Stability: &plusmn;0.2&deg;/s
	- Range: &plusmn;1000&deg;/s
- Accelerometer
	- Bias Stability: &plusmn;5mg
	- Range: &plusmn;8g

</div>

</div>

!!! info
	Please refer to the hookup guide linked below, for the operation of the IM19 attitude module in tilt-compensation applications:

	<article style="text-align: center;" markdown>
	[IM19 Hookup Guide - Tilt Compensation](../im19.md "Click to navigate"){ .md-button .md-button--primary }
	</article>

### Position Accuracy
When configured and calibrated, the IM19 attitude module can fuses its IMU sensor data with the received GNSS RTK positioning data to deliver a tilt compensated position.

<article style="text-align: center;" markdown>

| Tilt Angle | Accuracy |
| :---: | :---: |
| 0&deg; - 30&deg; | 1cm |
| <60&deg; | 2cm |

</article>

??? warning "LG290P GNSS Receiver"
	The accuracy of the position reported from the LG290P GNSS receiver, can be improved based upon the correction method being employed. Currently, [RTK](https://en.wikipedia.org/wiki/Real-time_kinematic_positioning "Real-Time Kinematic") corrections provide the highest level of accuracy. Its accuracy, displayed in the table below, should also be considered when implemented.

	<article style="text-align: center;" markdown>

	| Correction Method | Horizontal                   | Vertical                | Velocity                                |
	| :---------------- | :--------------------------: | :---------------------: | :-------------------------------------: |
	| Standalone        | 0.7m<br>~2.3'                | 2.5m<br>~8.2'           | 3cm/s (0.108kph)<br>~1.2in/s (0.067mph) |
	| RTK               | **0.8cm** *(+1ppm)*<br>~0.3" | 1.5cm *(+1ppm)*<br>~.6" |                                         |

	</article>

## GNSS Flex Headers
The GNSS Flex system is designed around two 2x10-pin, 2mm pitch headers used mate the two types of boards. A standardized pin layout, keeps the ecosystem pin-compatible for upgrades and allows boards to be easily swapped for repairs. For the LG290P GNSS receiver, these pins will breakout the UART (x2) and I^2^C interfaces along with a PPS, event, and LED status indication signals from the GNSS receiver. Additionally, these pins break out the two UART interfaces of the IM19 attitude module.

<div class="grid" markdown>

<div markdown>

<figure markdown>
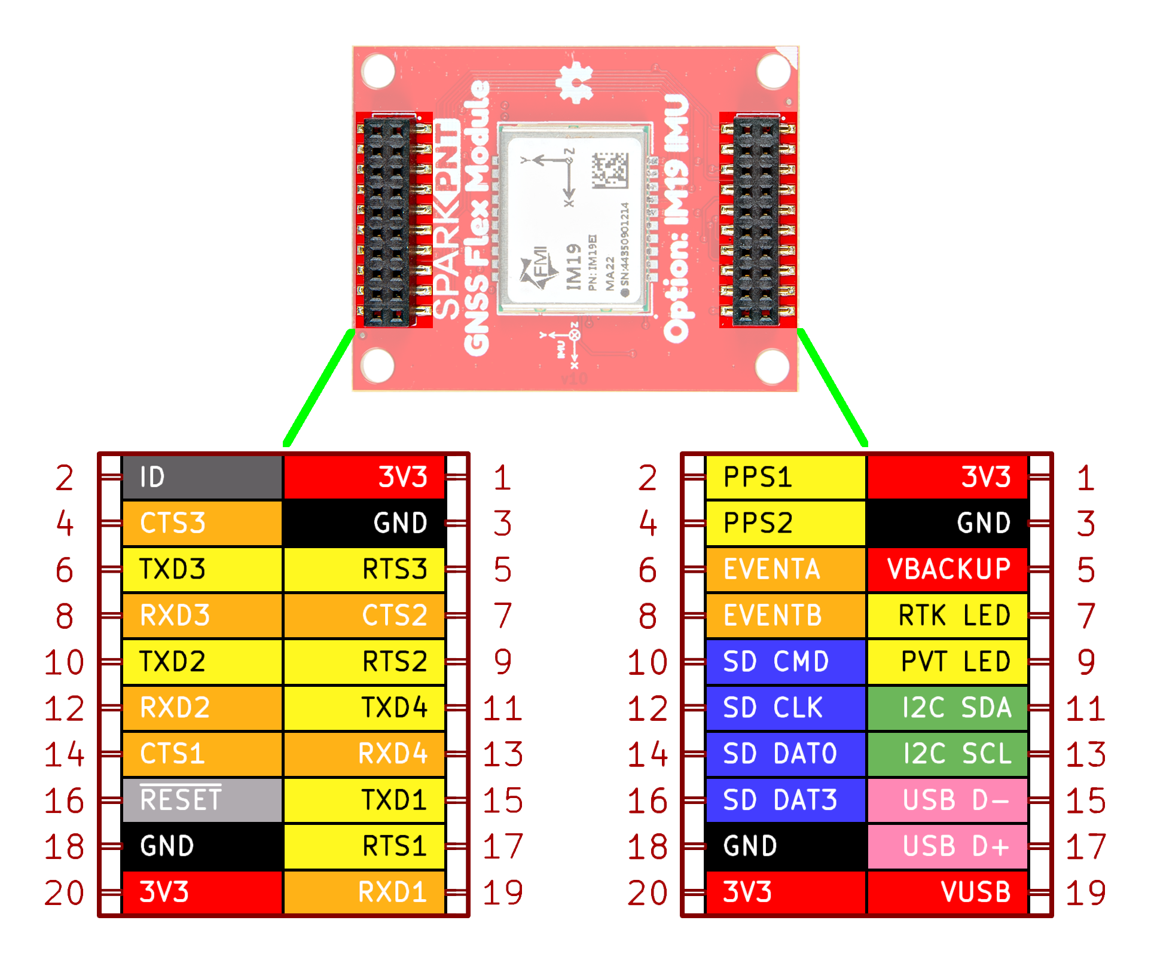
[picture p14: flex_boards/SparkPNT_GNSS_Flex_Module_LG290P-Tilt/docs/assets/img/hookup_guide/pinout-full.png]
Peripherals and I/O pins

<figcaption markdown>The peripherals and I/O pins on the LG290P GNSS Flex module.</figcaption>
</figure>

</div>

<div markdown>

Below, are the features that are available from the LG290P GNSS receiver.

<article class="annotate" markdown>

**Supported Interfaces:**

- UART (x2) (1)
- ~~SPI[^1]~~
- I^2^C[^1]
- Event Trigger
- Timing Signal
- RTK Signal

</article>

1. One of the three UART ports is piped to the IM19 module

Below, are the features that are available from the IM19 attitude module.

<article class="annotate" markdown>

**Supported Interfaces:**

- UART (x2)
- Timing Signal (1)

</article>

1. The timing signal comes from the LG290P GNSS receiver

</div>

</div>

=== "UART Ports"
	The headers of the GNSS Flex system supports up to four UART ports. On this GNSS Flex module, these are connected to both the GNSS receiver and IM19 attitude module.

	<figure markdown>
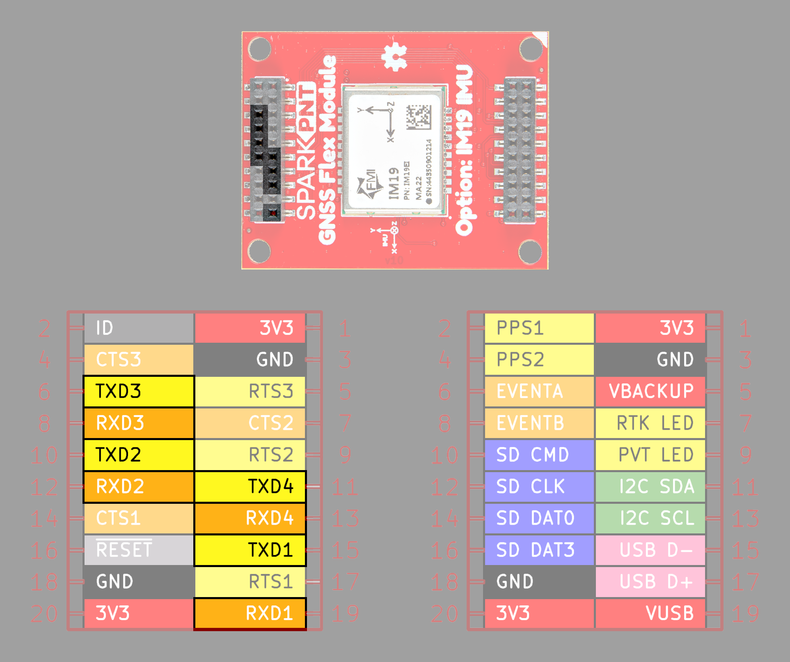
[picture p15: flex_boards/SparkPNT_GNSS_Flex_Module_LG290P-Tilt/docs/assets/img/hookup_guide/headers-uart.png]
UART interface
	
	<figcaption markdown>The UART ports on the LG290P GNSS Flex module.</figcaption>
	</figure>

	<div class="grid" markdown>

	<div markdown>

	**LG290P**

	---

	The LG290P GNSS receiver has three UART ports, which can be operated and configured separately.

	<figure markdown>
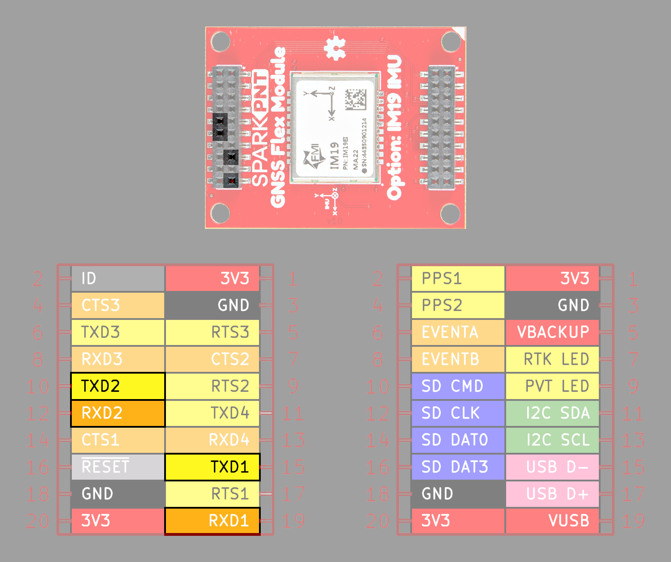
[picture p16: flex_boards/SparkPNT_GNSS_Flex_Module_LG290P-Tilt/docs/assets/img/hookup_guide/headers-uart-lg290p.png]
UART interface
	
	<figcaption markdown>The UART ports from the LG290P on the GNSS Flex module.</figcaption>
	</figure>

	- The `UART1` and `UART2` ports of the LG290P GNSS receiver are broken out to the headers of the GNSS Flex system. These can be used to interact with the LG290P.
	- The `TX` pin of the `UART3` port from the LG290P GNSS receiver is piped directly to the `RX` pin of the IM19 attitude module's `UART2` port.

	!!! info "Default Configuration"
		By default, the UART ports are configured with the following settings: 

		<div class="grid" markdown>

		<div markdown>

		- Baudrate: **460800bps**
		- Data Bits: 8
		- Parity: No
		- Stop Bits: 1
		- Flow Control: None
		- Protocols:
			- `NMEA 0183`
			- `RTCM 3.x`

		</div>

		<div style="text-align: center;" markdown>

		| LG290P | Pins of GNSS Flex Headers |
		| :-----: | :------------ |
		| `UART1` | `TXD1`/`RXD1` |
		| `UART2` | `TXD2`/`RXD2` |

		</div>

		</div>

	??? info "UART Protocols"
		### UART Protocols
		By default, these UART ports are configured to transmit and receive `NMEA 0183`, `RTCM 3.x`, and/or `QGC` messages. These messages are generally used for transmitting PNT data; providing or receiving RTK corrections; and receiving PPP data, respectively. Quectel also implements a system of proprietary messages (`PQTM`) for users to configure the LG290P that follows a data format similar to the `NMEA` protocol. The expected structure of these proprietary messages is shown below:

		<div class="grid" markdown>

		<div markdown>

		<figure markdown>
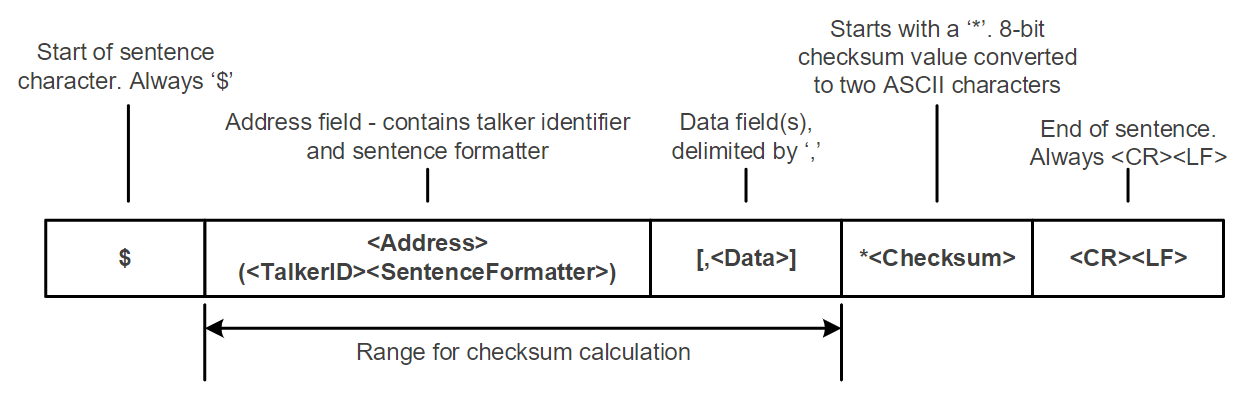
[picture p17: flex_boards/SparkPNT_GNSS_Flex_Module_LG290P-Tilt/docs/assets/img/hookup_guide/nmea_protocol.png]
NMEA data structure
		
		<figcaption markdown>The data structure of Quectel messages for the `NMEA` and `PQTM` protocols.</figcaption>
		</figure>

		</div>

		<div markdown>

		<figure markdown>
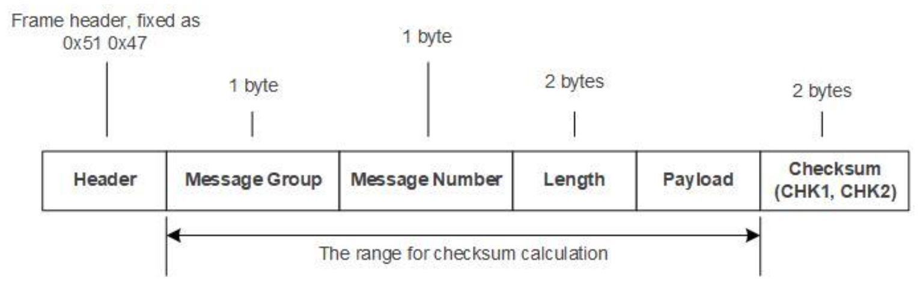
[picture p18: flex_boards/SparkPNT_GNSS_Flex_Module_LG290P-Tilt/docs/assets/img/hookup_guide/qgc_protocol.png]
QGC data structure
		
		<figcaption markdown>The data structure of Quectel messages for the `QGC` protocol.</figcaption>
		</figure>

		</div>

		</div>

		=== "NMEA"
			A full list of compatible `NMEA 0183` v4.11 messages, is provided in section **2.2. Standard Messages** of the [GNSS Protocol Specification](./assets/component_documentation/quectel_lg290p03lgx80p03_gnss_protocol_specification_v1-1.pdf) manual. This protocol is used for outputting GNSS data, as detailed by the [National Marine Electronics Association](https://www.nmea.org/) organization.

			??? abstract "List of Standard NMEA Messages"
				<article style="text-align: center;" markdown>

				| Message | Type Mode | Message Description               |
				| :-----: | :-------: | :-------------------------------- |
				| RMC | Output | Recommended Minimum Specific GNSS Data   |
				| GGA | Output | Global Positioning System Fix Data       |
				| GSV | Output | GNSS Satellites in View                  |
				| GSA | Output | GNSS DOP and Active Satellites           |
				| VTG | Output | Course Over Ground & Ground Speed        |
				| GLL | Output | Geographic Position – Latitude/Longitude |
				| GBS | Output | GNSS Satellite Fault Detection           |
				| GNS | Output | GNSS Fix Data                            |
				| GST | Output | GNSS Pseudorange Error Statistics        |
				| ZDA | Output | UTC Time & Date                          |
				| HDT | Output | True Vessel Heading                      |
				| THS | Output | True, Heading, and Status                |

				</article>

		=== "PQTM"
			A full list of PQTM messages (proprietary NMEA messages defined by Quectel) supported by LG290P, is provided in section **2.3. PQTM Messages** of the [GNSS Protocol Specification](./assets/component_documentation/quectel_lg290p03lgx80p03_gnss_protocol_specification_v1-1.pdf) manual. This protocol is used to configure or read the settings for the LG290P GNSS receiver.

			??? abstract "List of Proprietary Quectel Messages"
				<article style="text-align: center;" markdown>

				| Message            | Type Mode    | Message Description                              |
				| :----------------- | :----------: | :----------------------------------------------- |
				| PQTMVER            | Output       | Outputs the firmware version                     |
				| PQTMCOLD           | Command      | Performs a cold start                            |
				| PQTMWARM           | Command      | Performs a warm start                            |
				| PQTMHOT            | Command      | Performs a hot start                             |
				| PQTMSRR            | Command      | Performs a system reset and reboots the receiver |
				| PQTMUNIQID         | Command      | Queries the module unique ID                     |
				| PQTMSAVEPAR        | Command      | Saves the configurations into NVM                |
				| PQTMRESTOREPAR     | Command      | Restores the parameters configured by all commands to their default values |
				| PQTMVERNO          | Command      | Queries the firmware version                     |
				| PQTMCFGUART        | Set/Get      | Sets/gets the UART interface                     |
				| PQTMCFGPPS         | Set/Get      | Sets/gets the PPS feature                        |
				| PQTMCFGPROT        | Set/Get      | Sets/gets the input and output protocol for a specified port |
				| PQTMCFGNMEADP      | Set/Get      | Sets/gets the decimal places of standard NMEA messages |
				| PQTMEPE            | Output       | Outputs the estimated position error             |
				| PQTMCFGMSGRATE     | Set/Get      | Sets/gets the message output rate on the current interface |
				| PQTMVEL            | Output       | Outputs the velocity information                 |
				| PQTMCFGGEOFENCE    | Set/Get      | Sets/gets geofence feature                       |
				| PQTMGEOFENCESTATUS | Output       | Outputs the geofence status                      |
				| PQTMGNSSSTART      | Command      | Starts GNSS engine                               |
				| PQTMGNSSSTOP       | Command      | Stops GNSS engine                                |
				| PQTMTXT            | Output       | Outputs short text messages                      |
				| PQTMCFGSVIN        | Set/Get      | Sets/gets the Survey-in feature                  |
				| PQTMSVINSTATUS     | Output       | Outputs the Survey-in status                     |
				| PQTMPVT            | Output       | Outputs the PVT (GNSS only) result               |
				| PQTMCFGRCVRMODE    | Set/Get      | Sets/gets the receiver working mode              |
				| PQTMDEBUGON        | Command      | Enables debug log output                         |
				| PQTMDEBUGOFF       | Command      | Disables debug log output                        |
				| PQTMCFGFIXRATE     | Set/Get      | Sets/gets the fix interval                       |
				| PQTMCFGRTK         | Set/Get      | Sets/gets the RTK mode                           |
				| PQTMCFGCNST        | Set/Get      | Sets/gets the constellation configuration        |
				| PQTMDOP            | Output       | Outputs dilution of precision                    |
				| PQTMPL             | Output       | Outputs protection level information             |
				| PQTMCFGODO         | Set/Get      | Sets/gets the odometer feature                   |
				| PQTMRESETODO       | Command      | Resets the accumulated distance recorded by the odometer |
				| PQTMODO            | Output       | Outputs the odometer information                 |
				| PQTMCFGSIGNAL      | Set/Get      | Sets/gets GNSS signal mask                       |
				| PQTMCFGSAT         | Set/Get      | Sets/gets GNSS satellite mask                    |
				| PQTMCFGRSID        | Set/Get      | Sets/gets the reference station ID               |
				| PQTMCFGRTCM        | Set/Get      | Sets/gets RTCM                                   |
				| PQTMCFGSBAS        | Set/Get      | Configures SBAS                                  |
				| PQTMCFGNMEATID     | Set/Get      | Configures the NMEA Talker ID                    |
				| PQTMTAR            | Output       | Outputs the time and attitude                    |
				| PQTMCFGBLD         | Set/Get      | Configures the baseline distance                 |
				| PQTMCFGRTKSRCTYPE  | Set/Get      | Configures RTK differential source type          |
				| PQTMSN             | Command      | Reads the SN of module                           |
				| PQTMCFGANTINF      | Set/Get      | Configures the antenna information               |
				| PQTMCFGANTDELTA    | Set/Get      | Configures the delta between antennas            |
				| PQTMCFGSIGGRP      | Set/Get      | Configures the GNSS signal group                 |
				| PQTMCFGSIGNAL2     | Set/Get      | Configures GNSS signal mask for second antenna   |
				| PQTMCFGGEOSEP      | Set/Get      | Configures geoidal separation                    |
				| PQTMCFGCNRTHD      | Set/Get      | Configures the CNR threshold for position engine |
				| PQTMCFGELETHD      | Set/Get      | Configures the elevation threshold for position engine |
				| PQTMNAV            | Output       | Outputs the navigation information               |
				| PQTMEOE            | Output       | Outputs the end of epoch information             |
				| PQTMCFGWN          | Set/Get      | Configures the reference start week number       |
				| PQTMANTENNASTATUS  | Output       | Reports the antenna status                       |

				</article>

		=== "QGC"
			A full list of QGC messages (proprietary protocol defined by Quectel) supported by LG290P, is provided in section **3. QGC Protocol** of the [GNSS Protocol Specification](./assets/component_documentation/quectel_lg290p03lgx80p03_gnss_protocol_specification_v1-1.pdf) manual. This protocol is used to output the PPP raw data.

			??? abstract "List of Proprietary Quectel Messages"
				<article style="text-align: center;" markdown>

				| GQC Message Name | Message Group | Message Number | Type | Description |
				| :--------- | :--: | :--: | :----: | :--------------------------------- |
				| RAW-PPPB2B | 0x0A | 0xB2 | Output | BDS PPPB2B binary raw messages     |
				| RAW-QZSSL6 | 0x0A | 0xB6 | Output | QZSSL6 binary raw messages         |
				| RAW-HASE6  | 0x0A | 0xE6 | Output | Galileo HASE6 binary raw messages  |

				</article>

		=== "RTCM"
			A full list of compatible `RTCM v3` messages, is provided in section **4. RTCM Protocol** of the [GNSS Protocol Specification](./assets/component_documentation/quectel_lg290p03lgx80p03_gnss_protocol_specification_v1-1.pdf) manual. This protocol is used for transferring GNSS raw measurement data, as detailed by the [Radio Technical Commission for Maritime Services](https://www.rtcm.org/) organization.

			??? abstract "List of Supported RTCMv3 *(MSM)* Messages"
				<article style="text-align: center;" markdown>

				| Message | Type Mode | Message Description                              |
				| :--: | :----------: | :----------------------------------------------- |
				| 1005 | Input/Output | Stationary RTK Reference Station ARP             |
				| 1006 | Input/Output | Stationary RTK Reference Station ARP with height |
				| 1019 | Input/Output | GPS Ephemerides                                  |
				| 1020 | Input/Output | GLONASS Ephemerides                              |
				| 1041 | Input/Output | NavIC/IRNSS Ephemerides                          |
				| 1042 | Input/Output | BDS Satellite Ephemeris Data                     |
				| 1044 | Input/Output | QZSS Ephemerides                                 |
				| 1046 | Input/Output | Galileo I/NAV Satellite Ephemeris Data           |
				| 1073 | Input/Output | GPS MSM3 |
				| 1074 | Input/Output | GPS MSM4 |
				| 1075 | Input/Output | GPS MSM5 |
				| 1076 | Input/Output | GPS MSM6 |
				| 1077 | Input/Output | GPS MSM7 |
				| 1083 | Input/Output | GLONASS MSM3 |
				| 1084 | Input/Output | GLONASS MSM4 |
				| 1085 | Input/Output | GLONASS MSM5 |
				| 1086 | Input/Output | GLONASS MSM6 |
				| 1087 | Input/Output | GLONASS MSM7 |
				| 1093 | Input/Output | Galileo MSM3 |
				| 1094 | Input/Output | Galileo MSM4 |
				| 1095 | Input/Output | Galileo MSM5 |
				| 1096 | Input/Output | Galileo MSM6 |
				| 1097 | Input/Output | Galileo MSM7 |
				| 1113 | Input/Output | QZSS MSM3 |
				| 1114 | Input/Output | QZSS MSM4 |
				| 1115 | Input/Output | QZSS MSM5 |
				| 1116 | Input/Output | QZSS MSM6 |
				| 1117 | Input/Output | QZSS MSM7 |
				| 1123 | Input/Output | BDS MSM3 |
				| 1124 | Input/Output | BDS MSM4 |
				| 1125 | Input/Output | BDS MSM5 |
				| 1126 | Input/Output | BDS MSM6 |
				| 1127 | Input/Output | BDS MSM7 |
				| 1133 | Input/Output | NavIC/IRNSS MSM3 |
				| 1134 | Input/Output | NavIC/IRNSS MSM4 |
				| 1135 | Input/Output | NavIC/IRNSS MSM5 |
				| 1136 | Input/Output | NavIC/IRNSS MSM6 |
				| 1137 | Input/Output | NavIC/IRNSS MSM7 |

				</article>

	</div>

	<div markdown>

	**IM19**

	---

	The IM19 attitude module has two UART ports, which operate separately.

	<figure markdown>
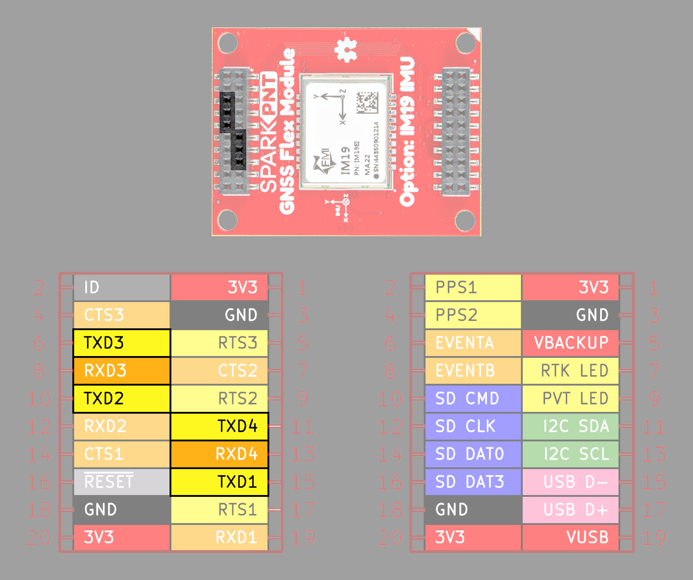
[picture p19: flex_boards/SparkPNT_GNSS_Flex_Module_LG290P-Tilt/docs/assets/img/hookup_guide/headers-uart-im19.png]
UART interface
	
	<figcaption markdown>The UART ports from the IM19 on the LG290P GNSS Flex module.</figcaption>
	</figure>

	- The `UART1` port of the IM19 module is broken out to the headers of the GNSS Flex system, on pins `TXD3` and `RXD3`. These pins should be used to configure the IM19 module.
	- The `UART2` port of the IM19 module is used to receive GNSS data from the GNSS receiver and output the tilt compensated data.
		- By default, the `RX` pin receives data from the `UART3` port of the LG290P GNSS receiver.
			- Users can [modify the jumpers](#jumpers) on the top of the GNSS Flex module, to utilize the `TXD1`, `TXD2`, or `RXD4` pins *(of the GNSS Flex headers)* instead.
		- Once IM19 module is configured and calibrated, the `TX` pin outputs the tilt compensated data to the `TXD4` pin on the GNSS Flex headers.

	!!! info "Default Configuration"
		By default, the UART ports are configured with the following settings: 

		<div class="grid" markdown>

		<div markdown>

		- Baudrate: **115200bps**
		- Data Bits: 8
		- Parity: No
		- Stop Bits: 1
		- Flow Control: None
		- Protocols:
			- AT Commands
			- Proprietary Data Formats
				- MEMS Raw data protocol
				- GNSS Raw data protocol
				- Binary NAVI positioning data protocol

		</div>

		<div style="text-align: center;" markdown>

		| IM19 | Pins of GNSS Flex Headers |
		| :-----: | :------------ |
		| `UART1` | `TXD3`/`RXD3` |
		| `UART2` | `TXD4` |

		</div>

		</div>

	</div>

	</div>

=== "PPS Output"
	From the module, the [PPS](https://en.wikipedia.org/wiki/Pulse-per-second_signal "Pulse Per Second") output signal is a 3.3V signal output. In order to receive tilt-compensated data from the IM19 attitude module, this pin needs to be configured to provide a timing pulse at the same rate as the PVT solutions.

	<figure markdown>
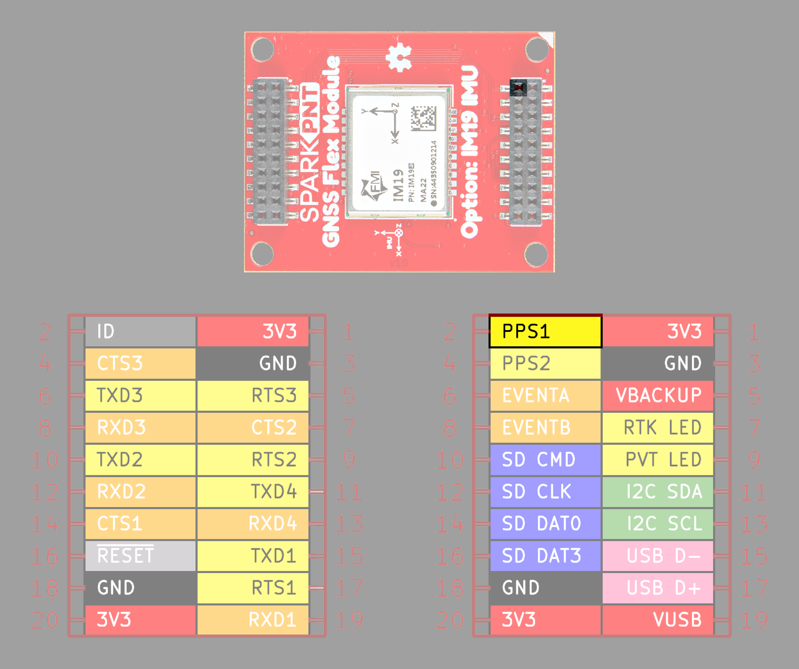
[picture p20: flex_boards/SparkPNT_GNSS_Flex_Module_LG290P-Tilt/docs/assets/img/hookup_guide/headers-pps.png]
I/O for PPS signal
	
	<figcaption markdown>The `PPS` signal's output on the LG290P GNSS Flex module.</figcaption>
	</figure>

=== "LED Output"
	The `RTK` pin operates as both the `RTK_LED` status indicator for the RTK positioning and `ANT_ON` power control for the external LNA or active antenna power.

	<figure markdown>
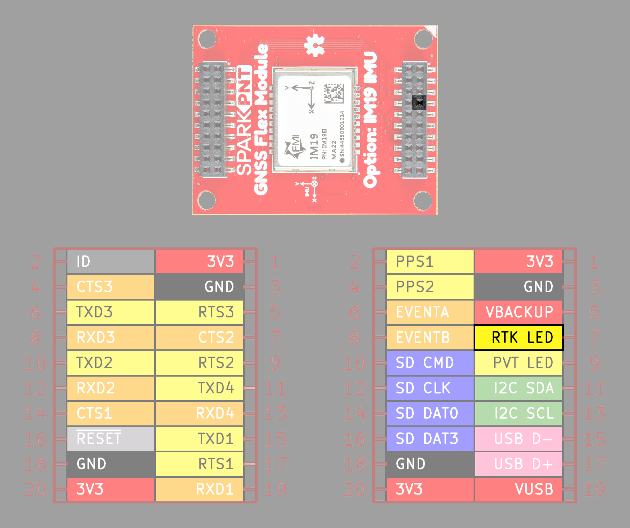
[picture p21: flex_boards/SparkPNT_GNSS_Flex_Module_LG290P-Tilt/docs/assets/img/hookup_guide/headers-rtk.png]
I/O for RTK signal
	
	<figcaption markdown>The `RTK_LED` pin on the LG290P GNSS Flex module.</figcaption>
	</figure>

	=== "`RTK_LED`"
		In this configuration, the pin is set to a high level at startup.

		1. If the pin output is high, it indicates the module has entered the RTK fixed mode.
		2. If the pin output is low, it indicates that the module exited the RTK fixed mode.
		3. If the pin outputs an alternating pin level, it indicates that the module received the correct RTCM data and did not enter the RTK fixed mode.

	=== "`ANT_ON`"
		In this configuration, the pin is used to control the external LNA or active antenna power supply.

		- When the pin is high, the antenna is powered.
		- When the pin is low, the antenna is not powered.

=== "Event Trigger"
	This pin can be triggered by inputs with an adjustable frequency and polarity.

	<figure markdown>
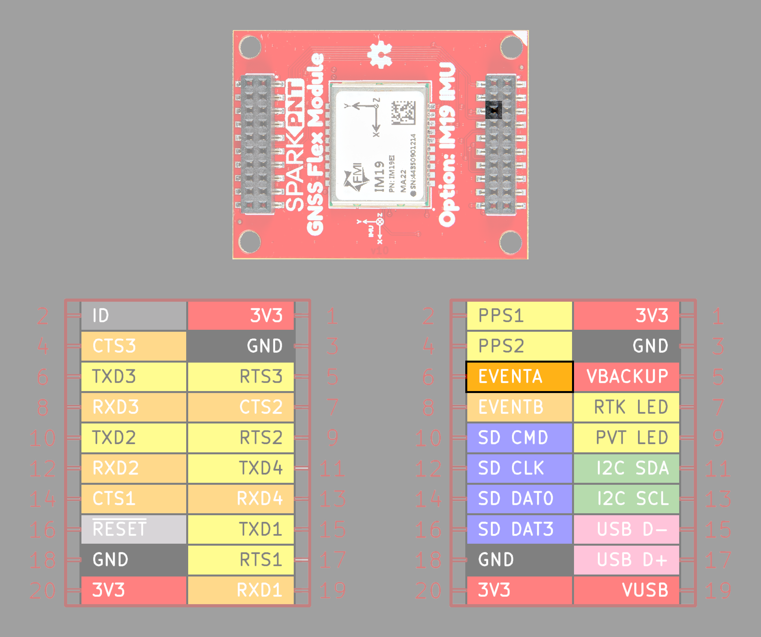
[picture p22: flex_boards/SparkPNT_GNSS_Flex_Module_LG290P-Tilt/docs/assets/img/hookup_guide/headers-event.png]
Event trigger
	
	<figcaption markdown>The event pin on the LG290P GNSS Flex module.</figcaption>
	</figure>

	!!! tip "Use Case"
		Users could use this pin in conjunction with the PPS signal to synchronize two modules with each other.

=== "Reset"
	This pin can be used to reset both the LG290P GNSS receiver and IM19 attitude module. Driving the pin `LOW` for at least 100ms triggers a restart of both modules.

	<figure markdown>
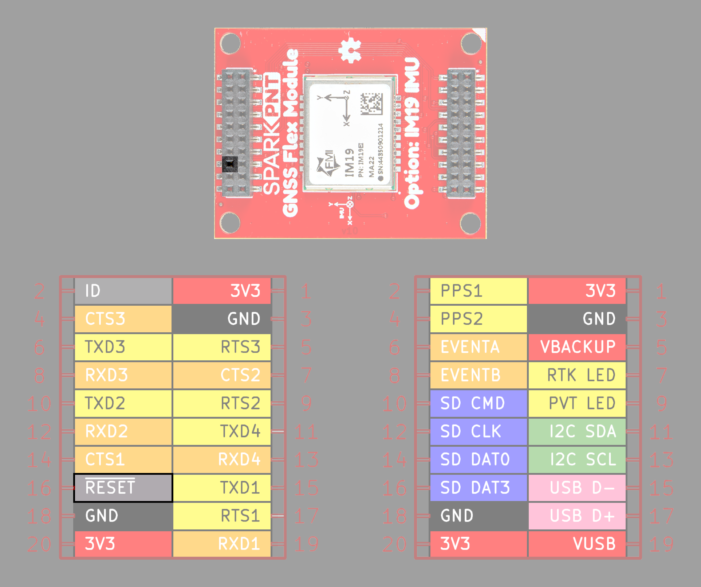
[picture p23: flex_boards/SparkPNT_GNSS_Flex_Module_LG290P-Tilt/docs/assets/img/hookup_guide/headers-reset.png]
Reset
	
	<figcaption markdown>The reset pin on the LG290P GNSS Flex module.</figcaption>
	</figure>

## U.FL Connector
Users will need to connect a compatible GNSS antenna to the `Antenna L1/L2/L5/E6` U.FL connector. The type of antenna used with the LG290P module affects the overall accuracy of the positions calculated by the GNSS receiver.

- Passive antennas are not recommended for the LG290P GNSS receiver.
- To mitigate the impact of out-of-band signals, utilize an active antenna whose SAW filter is placed in front of the LNA in the internal framework.
	- **DO NOT** select an antenna with the LNA placed in the front.
- There is no need to inject an external DC voltage for the GNSS antenna. Power is already provided from the LG290P module for the LNA of an active antenna.

<figure markdown>
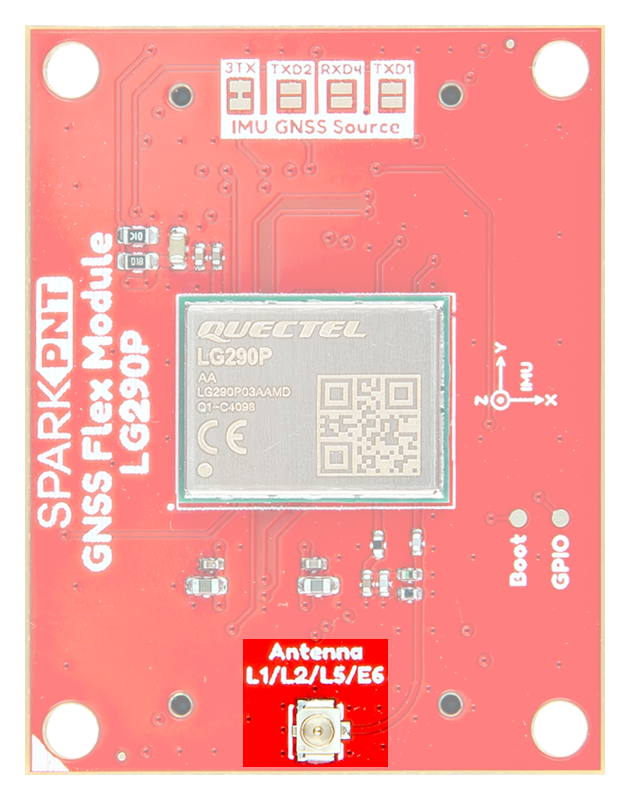
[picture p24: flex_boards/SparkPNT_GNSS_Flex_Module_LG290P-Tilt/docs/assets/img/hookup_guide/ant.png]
GNSS antenna input

<figcaption markdown>The U.FL connector to attach an external GNSS antenna to the LG290P GNSS Flex module.</figcaption>
</figure>

!!! tip
	For the best performance, we recommend users choose a compatible L1/L2/L5/E6 GNSS antenna and utilize a low-loss cable. Also, don't forget that GNSS signals are fairly weak and can't penetrate buildings or dense vegetation. The GNSS antenna should have an unobstructed view of the sky.

## Jumpers
The are four jumpers on top of the LG290P GNSS Flex module that can be modified to change the source of the GNSS data for the IM19 attitude module.

<div class="grid" markdown>

<div markdown>

<figure markdown>
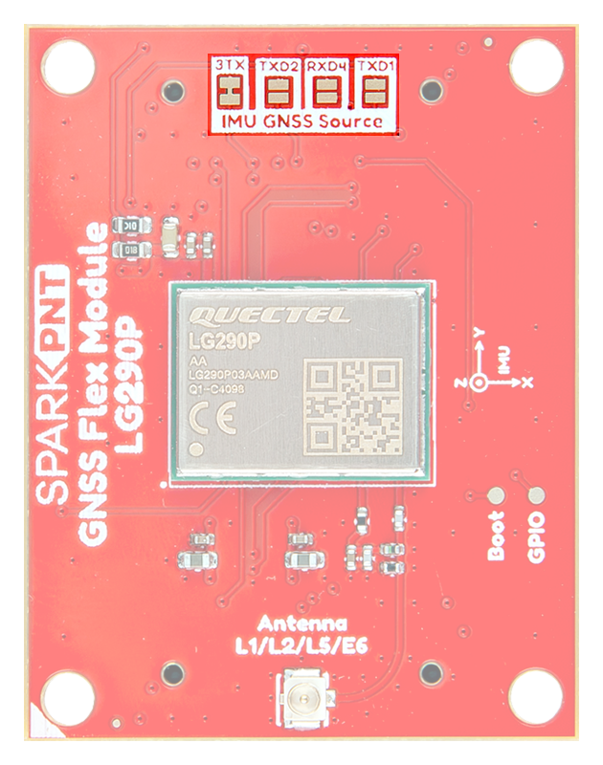
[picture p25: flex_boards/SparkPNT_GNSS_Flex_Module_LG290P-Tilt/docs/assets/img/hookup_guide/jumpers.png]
Jumpers

<figcaption markdown>The jumper on the top of the LG290P GNSS Flex module.</figcaption>
</figure>

</div>

<div markdown>

???+ note "Never modified a jumper before?"
	Check out our <a href="https://learn.sparkfun.com/tutorials/664">Jumper Pads and PCB Traces tutorial</a> for a quick introduction!

	<article class="grid cards" markdown align="center">

	-   <a href="https://learn.sparkfun.com/tutorials/664">
		<figure markdown>
		Tutorial thumbnail
		</figure>

		---

		**How to Work with Jumper Pads and PCB Traces**</a>

	</article>

</div>

</div>

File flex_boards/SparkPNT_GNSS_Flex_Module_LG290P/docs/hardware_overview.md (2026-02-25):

<article style="text-align: center;" markdown>
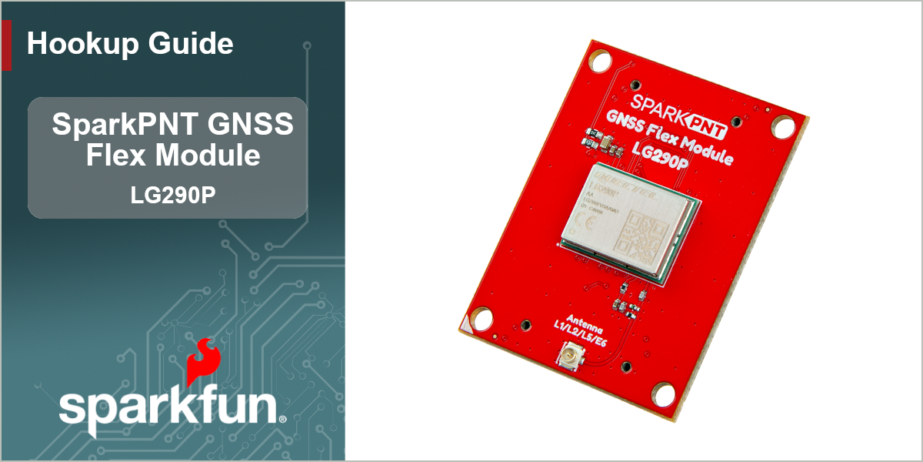
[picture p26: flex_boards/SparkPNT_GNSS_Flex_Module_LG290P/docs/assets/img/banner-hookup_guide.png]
Banner

</article>

## Introduction

<div class="grid cards desc" markdown>

-   <a href="https://www.sparkfun.com/sparkpnt-gnss-flex-module-lg290p.html">
	**SparkPNT GNSS Flex Module - LG290P**<br>
	**SKU:** GPS-28139

	---

	<figure markdown>
	Product Thumbnail
	</figure></a>

	<article style="text-align: center;" markdown>
	QR code to product page
	[Purchase from SparkFun :fontawesome-solid-cart-plus:{ .heart }](https://www.sparkfun.com/sparkpnt-gnss-flex-module-lg290p.html){ .md-button .md-button--primary }
	</article>

-   SparkPNT GNSS Flex modules are plug-in boards featuring different GNSS receivers. They are designed to be easily swapped for repairs and pin-compatible for upgrades. The boards have two 2x10-pin, 2mm pitch female headers connecting to carrier boards. For the LG290P GNSS receiver, these pins will break out the USB, UART (x3), and I^2^C* interfaces, along with the PPS and event signals using a standardized pinout.

	This SparkPNT GNSS Flex module features the Quectel LG290P GNSS receiver. The LG290P module is a quad-band, multi-constellation, high-precision, RTK GNSS receiver. The module can simultaneously receive signals from the `L1`, `L2`, `L5`, and `L6`/`E6` frequency bands of the GPS, GLONASS, Galileo, BDS, QZSS, and NavIC GNSS constellations. In addition, the module supports SBAS augmentation systems (WASS, EGNOS, BDSBAS, MSAS, GAGAN, and SDCM), PPP services (Feature is still under development) (BDS PPP-B2b, QZSS CLAS, MADOCA-PPP, and Galileo HAS), RTCM, and RTK corrections for precision navigation with a fast convergence time and reliable performance.

	The built-in NIC anti-jamming unit provides professional-grade interference signal detection and elimination algorithms, effectively mitigating multiple narrow-band interference sources and significantly improving signal reception performance in complex electromagnetic environments. Additionally, the embedded algorithms ensure reliable positioning in complex scenarios such as urban environments and deep tree cover.

	!!! warning "Features Under Development"
		- **I^2^C/SPI** - Currently, only the UART interface is supported by the module.
		- **PPP Services** - Corrections for some of the PPP services have not been implemented.

</div>

## :material-folder-cog: Design Files

<!-- Import the component -->
<script type="module" src="https://ajax.googleapis.com/ajax/libs/model-viewer/4.0.0/model-viewer.min.js"></script>

<div class="grid cards desc" markdown>

-   :kicad-primary:{ .enlarge-logo } Design Files

	---

	- :fontawesome-solid-file-pdf: [Schematic](./assets/board_files/schematic.pdf)
	- :material-folder-zip: [KiCad Files](./assets/board_files/kicad_files.zip)
	- :material-rotate-3d: [STEP File](./assets/3d_model/cad_model.step)
	- :fontawesome-solid-file-pdf: [Board Dimensions](./assets/board_files/dimensions.pdf):
		- 1.75" x 1.25" (44.45mm x 31.75mm)

-   <!-- Boxes in tabs -->

	=== "3D Model"
		<article style="text-align: center;" markdown>
		<model-viewer src="../assets/3d_model/web_model.glb" camera-controls poster="../assets/3d_model/poster.png" tone-mapping="neutral" shadow-intensity="2" shadow-softness="0.2" camera-orbit="0deg 75deg 0.103m" field-of-view="25.11deg" style="width: 100%; height: 450px;">
		</model-viewer>

		[Download the `*.step` File](./assets/3d_model/cad_model.step "Click to download"){ .md-button .md-button--primary width="250px" }

		</article>

		???+ tip "Manipulate 3D Model"
			<article style="text-align: center;" markdown>

			| Controls       | Mouse                    | Touchscreen    |
			| :------------- | :----------------------: | :------------: |
			| Zoom           | Scroll Wheel             | 2-Finger Pinch |
			| Rotate         | ++"Left-Click"++ & Drag  | 1-Finger Drag  |
			| Move/Translate | ++"Right-Click"++ & Drag | 2-Finger Drag  |

			</article>

	=== "Dimensions"
		<article style="text-align: center;" markdown>
		Board Dimensions
		<figcaption markdown>Dimensions of the LG290P GNSS Flex module.</figcaption>
		</article>

		???+ tip "Need more measurements?"
			For more information about the board's dimensions, users can download the [KiCad files](./assets/board_files/kicad_files.zip) for this board. These files can be opened in KiCad and additional measurements can be made with the measuring tool.

			!!! info ":octicons-download-16:{ .heart } KiCad - Free Download!"
				KiCad is free, open-source [CAD]("computer-aided design") program for electronics. Click on the button below to download their software. *(\*Users can find out more information about KiCad from their [website](https://www.kicad.org/).)*

				<article style="text-align: center;" markdown>
				[Download :kicad-primary:{ .enlarge-logo }](https://www.kicad.org/download/ "Go to downloads page"){ .md-button .md-button--primary width="250px" }
				</article>

			???+ info ":straight_ruler: Measuring Tool"
				This video demonstrates how to utilize the dimensions tool in KiCad, to include additional measurements:

				<article class="video-500px" style="text-align: center; margin: auto;" markdown>
				<iframe src="https://www.youtube.com/embed/-eXuD8pkCYw" title="KiCad Dimension Tool" frameborder="0" allow="accelerometer; autoplay; clipboard-write; encrypted-media; gyroscope; picture-in-picture" allowfullscreen></iframe>
				QR code to play video
				</article>

</div>

## Board Layout
The GNSS Flex system is designed around two 2x10-pin, 2mm pitch headers used mate the two types of boards. A standardized pin layout, keeps the ecosystem pin-compatible for upgrades and allows board to be easily swapped for repairs. Depending on the capabilities of the GNSS receiver, these pins will breakout the USB, UART (x4), I^2^C, and SD card interfaces along with any PPS or event signals of the GNSS receiver.

The LG290P GNSS Flex module has the following features:

<div class="grid" markdown>

<div markdown>

<figure markdown>
Layout
<figcaption markdown>Layout of the major components on the LG290P GNSS Flex module.</figcaption>
</figure>

</div>

<div markdown>

1. **LG290P GNSS Receiver**
:	The Quectel LG290P GNSS receiver
1. **GNSS Flex Headers**
:	Two sets of 2x10 pin, 2mm pitch female headers for connecting a GNSS Flex module to *carrier boards*
1. **`ANT1` U.FL Connector**
:	An U.FL connector for attaching an external GNSS antenna

</div>

</div>

## LG290P GNSS Receiver
The centerpiece of the LG290P GNSS Flex module, is the [LG290P GNSS receiver](./assets/component_documentation/quectel_lg290p03_hardware_design_v1-1.pdf) from [Quectel](https://www.quectel.com/). The LG290P is a low-power, multi-band, multi-constellation GNSS receiver capable of delivering centimeter-level precision at high update rates. The built-in NIC anti-jamming unit provides professional-grade interference signal detection and elimination algorithms, which effectively mitigate against multiple narrow-band interference sources and significantly improves the signal reception performance in complex electromagnetic environments. With its performance advantages of high-precision and power consumption, this board is an ideal choice for high-precision navigation applications, such as intelligent robots, UAVs, precision agriculture, mining, surveying, and autonomous navigation.

<div class="grid cards" markdown>

<div style="text-align: center;" markdown>

QR code to product video

<article class="video-500px" style="margin: auto;" markdown>
<iframe src="https://player.vimeo.com/video/1000742664?dnt=1&amp;app_id=122963" title="Quectel: Product Intro for LG290P GNSS Receiver" frameborder="0" allow="accelerometer; autoplay; clipboard-write; encrypted-media; gyroscope; picture-in-picture" allowfullscreen></iframe>
</article>

</div>

-   <figure markdown>
	LG290P GNSS receiver
	<figcaption markdown>The LG290P module on the LG290P GNSS Flex module.</figcaption>
	</figure>

</div>

<div class="grid" markdown>

<div markdown>

**Features:**

- Supply Voltage: **3.15–3.45V**
- Tracking Channels: 1040
- Concurrent signal reception: 5 + QZSS
	- `L1`, `L2`, `L5`, `E6` frequency bands
- Sensitivity:
	- Acquisition: -146dBm
	- Tracking: -160dBm
	- Reacquisition: -155dBm
- Antenna Power: External or Internal
- GNSS Constellations and SBAS Systems:
	- **USA:** GPS + WASS
	- **Russia:** GLONASS + SDCM
	- **EU:** Galileo + EGNOS
	- **China:** BDS + BDSDAS
	- **Japan:** QZSS + MSAS
	- **India:** NavIC + GAGAN
- Accuracy of 1PPS Signal: 5ns *(RMS)*
- Update Rate:
	- Default: 10Hz
	- Max: 20Hz

</div>

<div markdown>

<br>

- Time to First Fix *(without AGNSS)*:
	- Cold Start: 28s
	- Warm Start: 28s
	- Hot Start: 1.7s
- RTK Convergence Time: 5s
- Dynamic Performance:
	- Maximum Altitude: 10000m
	- Maximum Velocity: 490m/s
	- Maximum Acceleration: 4g
- Built-in NIC anti-jamming unit
- Interfaces
	- UART (x3)
		- Baud Rate: 9600–3000000bps
			- **Default:** 460800bps
		- Protocol: `NMEA 0183`/`RTCM 3.x`
	- SPI[^1] (x1)
	- I^2^C[^1] (x1)
- Operating temperature: -40&deg;C to +85&deg;C

</div>

</div>

[^1]:
	!!! warning "Feature Under Development"
		Currently, only the UART interface is supported by the module. Support for the **I^2^C** and **SPI** interfaces are still under development.

### Power Consumption
The power consumption of the LG290P GNSS receiver depends on the GNSS signals enabled and the positioning mode.

<div class="grid" markdown>

<article style="text-align: center;" markdown>

| Mode | Power (mW) | Current (mA) |
| :--- | :---: | :---: |
| Acquisition | 300.3 | 91 |
| Tracking | 300.3 | 91 |
| Backup | 39.6 | 0.012 |

</article>

<div markdown>

!!! info "Power Modes"

	**Acquisition:**
	:   Module searches for satellites and to determine visible satellites, coarse frequency, and the code phase of satellite signals

	**Tracking:**
	:   Once acquisition is completed, the module tracks satellites and demodulates the navigation data from specific satellites

	**Backup Mode:**
	:   Reduces power consumption. Only backup domain is active and keeps track of time.

</div>

</div>

### Frequency Bands
The LG290P module is a multi-band, multi-constellation GNSS receiver. Below, is a chart illustrating the frequency bands utilized by all the global navigation satellite systems; along with a list of the frequency bands and GNSS systems supported by the LG290P GNSS receiver.

<figure markdown>
GNSS frequency bands (https://www.tallysman.com/app/uploads/2021/07/Tallysman-GNSS-Frequencies-v8.0_Chart-1-1024x425.png "Click to enlarge")
<figcaption markdown>Frequency bands of the global navigation satellite systems. (Source: [Tallysman](https://www.tallysman.com/gnss-constellations-radio-frequencies-and-signals/))</figcaption>
</figure>

<div class="grid" markdown>

<div markdown>

**Supported Frequency Bands:**

- GPS: `L1 C/A`, `L1C`[^2], `L5`, `L2C`
- GLONASS: `L1`, `L2`
- Galileo: `E1`, `E5a`, `E5b`, `E6`
- BDS: `B1I`, `B1C`, `B2a`, `B2b`, `B2I`, `B3I`
- QZSS: `L1 C/A`, `L1C`[^2], `L5`, `L2C`
- NavIC: `L5`
- SBAS: `L1 C/A`
- L-band PPP[^3]:
	- PPP: `B2b`
	- QZSS: `L6`
	- Galileo HAS: `E6`

</div>

<div markdown>

**Supported GNSS Constellations:**

- GPS (USA)
- GLONASS (Russia)
- Galileo (EU)
- BDS (China)
- QZSS (Japan)
- NavIC (India)

**Supported SBAS Systems:**

- WASS (USA)
- SDCM (Russia)
- EGNOS (EU)
- BDSBAS (China)
- MSAS (Japan)
- GAGAN (India)

</div>

</div>

[^2]:
	!!! warning "Feature Under Development"
		Support for the `L1C` frequency band has not been implemented.
[^3]:
	!!! warning "Feature Under Development"
		Corrections for some of the PPP services have not been implemented.

!!! info
	For a comparison of the frequency bands supported by the LG290P GNSS receivers, refer to sections **1.2**, **1.5**, and **1.6** of the [hardware design manual](./assets/component_documentation/quectel_lg290p03_hardware_design_v1-1.pdf).

	??? info "What are Frequency Bands?"
		A [frequency band](https://en.wikipedia.org/wiki/Frequency_band) is a section of the [electromagnetic spectrum](https://en.wikipedia.org/wiki/Electromagnetic_spectrum), usually denoted by the range of its upper and lower limits. In the [radio spectrum](https://en.wikipedia.org/wiki/Radio_spectrum), these frequency bands are usually regulated by region, often through a government entity. This regulation prevents the interference of RF communication; and often includes major penalties for any interference with critical infrastructure systems and emergency services.

		<figure markdown>
		GNSS frequency bands (https://gssc.esa.int/navipedia/images/c/cf/GNSS_All_Signals.png "Click to enlarge")
		<figcaption markdown>Frequency bands of the global navigation satellite systems. (Source: [ESA](https://gssc.esa.int/navipedia/index.php?title=File:GNSS_All_Signals.png "European Space Agency"))</figcaption>
		</figure>

		However, if the various GNSS constellations share similar frequency bands, then how do they avoid interfering with one another? Without going too far into detail, the image above helps illustrate some of the characteristics, specific to the frequency bands of each system. With these characteristics in mind, along with other factors, the chart can help users to visualize how multiple GNSS constellations might co-exist with each other.

		For more information, users may find these articles of interest:

		- [GNSS signal](https://gssc.esa.int/navipedia/index.php/GNSS_signal)
		- [GPS Signal Plan](https://gssc.esa.int/navipedia/index.php?title=GPS_Signal_Plan)
		- [GLONASS Signal Plan](https://gssc.esa.int/navipedia/index.php?title=GLONASS_Signal_Plan)
		- [GALILEO Signal Plan](https://gssc.esa.int/navipedia/index.php?title=GALILEO_Signal_Plan)

### Position Accuracy

<div class="grid" markdown>

<div markdown>

The accuracy of the position reported from the LG290P GNSS receiver, can be improved based upon the correction method being employed. Currently, [RTK](https://en.wikipedia.org/wiki/Real-time_kinematic_positioning "Real-Time Kinematic") corrections provide the highest level of accuracy; however, users should be aware of certain limitations of the system:

- RTK technique requires real-time correction data from a reference station or network of base stations.
	- RTK corrections usually come from RTCM messages that are signal specific *(i.e. an RTK network may only provide corrections for specific signals; only `E5b` and not `E5a`)*.
- The range of the base stations will vary based upon the method used to transmit the correction data.
- The reliability of RTK corrections are inherently reduced in [multipath environments](https://en.wikipedia.org/wiki/Multipath_propagation).

</div>

<div markdown>

<article style="text-align: center;" markdown>

| Correction Method | Horizontal | Vertical | Velocity |
| :--- | :---: | :---: | :---: |
| Standalone | 0.7m<br>~2.3' | 2.5m<br>~8.2' | 3cm/s (0.108kph)<br>~1.2in/s (0.067mph) |
| RTK | **0.8cm** *(+1ppm)*<br>~0.3" | 1.5cm *(+1ppm)*<br>~.6" | |

</article>

</div>

</div>

??? info "RTK Corrections"
	To understand how RTK works, users will need a more fundamental understanding of the signal error sources.

	<div class="grid cards" markdown align="center">

	-   <a href="https://www.sparkfun.com/news/7533">
		<figure markdown>
		Tutorial Thumbnail
		</figure>

		---

		**Real-Time Kinematics Explained**</a>

	-   <a href="https://www.sparkfun.com/news/7138">
		<figure markdown>
		Tutorial Thumbnail
		</figure>

		---

		**What is Correction Data?**</a>

	-   <a href="https://www.septentrio.com/en/learn-more/insights/gnss-corrections-demystified">
		<figure markdown>
		Tutorial Thumbnail
		</figure>

		---

		**GNSS Corrections Demystified**</a>

	</div>

!!! tip
	For the best performance, we highly recommend that users configure the module to utilize/provide RTK corrections with a compatible L1/L2/L5/L6 GNSS antenna and utilize a low-loss cable.

## GNSS Flex Headers
The GNSS Flex system is designed around two 2x10-pin, 2mm pitch headers used mate the two types of boards. A standardized pin layout, keeps the ecosystem pin-compatible for upgrades and allows boards to be easily swapped for repairs. For the LG290P GNSS receiver, these pins will breakout the UART (x3) and I^2^C interfaces along with a PPS, event, and LED status indication signal from the GNSS receiver.

<div class="grid" markdown>

<div markdown>

<figure markdown>
Peripherals and I/O pins
<figcaption markdown>The peripherals and I/O pins on the LG290P GNSS Flex module.</figcaption>
</figure>

</div>

<div markdown>

Below, are the features that are available from the LG290P GNSS receiver.

**Supported Interfaces:**

- UART (x3)
- ~~SPI[^1]~~
- I^2^C[^1]
- Event Trigger
- Timing Signal
- RTK Signal

</div>

</div>

=== "UART Ports"
	The LG290P GNSS receiver has three UART ports, which can be operated and configured separately.

	<div class="grid" markdown>

	<div markdown>

	<figure markdown>
	UART interface
	<figcaption markdown>The UART ports on the LG290P GNSS Flex module.</figcaption>
	</figure>

	</div>

	<div markdown>

	!!! info "Default Configuration"
		By default, the UART ports are configured with the following settings: 

		- Logic Level: **3.3V**
		- Baudrate: **460800bps**
		- Data Bits: 8
		- Parity: No
		- Stop Bits: 1
		- Flow Control: None
		- Protocols:
			- `NMEA 0183`
			- `RTCM 3.x`

	</div>

	</div>

	??? info "UART Protocols"
		###UART Protocols
		By default, these UART ports are configured to transmit and receive `NMEA 0183`, `RTCM 3.x`, and/or `QGC` messages. These messages are generally used for transmitting PNT data; providing or receiving RTK corrections; and receiving PPP data, respectively. Quectel also implements a system of proprietary messages (`PQTM`) for users to configure the LG290P that follows a data format similar to the `NMEA` protocol. The expected structure of these proprietary messages is shown below:

		<div class="grid" markdown>

		<div markdown>

		<figure markdown>
		NMEA data structure
		<figcaption markdown>The data structure of Quectel messages for the `NMEA` and `PQTM` protocols.</figcaption>
		</figure>

		</div>

		<div markdown>

		<figure markdown>
		QGC data structure
		<figcaption markdown>The data structure of Quectel messages for the `QGC` protocol.</figcaption>
		</figure>

		</div>

		</div>

		=== "NMEA"
			A full list of compatible `NMEA 0183` v4.11 messages, is provided in section **2.2. Standard Messages** of the [GNSS Protocol Specification](./assets/component_documentation/quectel_lg290p03lgx80p03_gnss_protocol_specification_v1-1.pdf) manual. This protocol is used for outputting GNSS data, as detailed by the [National Marine Electronics Association](https://www.nmea.org/) organization.

			??? abstract "List of Standard NMEA Messages"
				<article style="text-align: center;" markdown>

				| Message | Type Mode | Message Description               |
				| :-----: | :-------: | :-------------------------------- |
				| RMC | Output | Recommended Minimum Specific GNSS Data   |
				| GGA | Output | Global Positioning System Fix Data       |
				| GSV | Output | GNSS Satellites in View                  |
				| GSA | Output | GNSS DOP and Active Satellites           |
				| VTG | Output | Course Over Ground & Ground Speed        |
				| GLL | Output | Geographic Position – Latitude/Longitude |
				| GBS | Output | GNSS Satellite Fault Detection           |
				| GNS | Output | GNSS Fix Data                            |
				| GST | Output | GNSS Pseudorange Error Statistics        |
				| ZDA | Output | UTC Time & Date                          |
				| HDT | Output | True Vessel Heading                      |
				| THS | Output | True, Heading, and Status                |

				</article>

		=== "PQTM"
			A full list of PQTM messages (proprietary NMEA messages defined by Quectel) supported by LG290P, is provided in section **2.3. PQTM Messages** of the [GNSS Protocol Specification](./assets/component_documentation/quectel_lg290p03lgx80p03_gnss_protocol_specification_v1-1.pdf) manual. This protocol is used to configure or read the settings for the LG290P GNSS receiver.

			??? abstract "List of Proprietary Quectel Messages"
				<article style="text-align: center;" markdown>

				| Message            | Type Mode    | Message Description                              |
				| :----------------- | :----------: | :----------------------------------------------- |
				| PQTMVER            | Output       | Outputs the firmware version                     |
				| PQTMCOLD           | Command      | Performs a cold start                            |
				| PQTMWARM           | Command      | Performs a warm start                            |
				| PQTMHOT            | Command      | Performs a hot start                             |
				| PQTMSRR            | Command      | Performs a system reset and reboots the receiver |
				| PQTMUNIQID         | Command      | Queries the module unique ID                     |
				| PQTMSAVEPAR        | Command      | Saves the configurations into NVM                |
				| PQTMRESTOREPAR     | Command      | Restores the parameters configured by all commands to their default values |
				| PQTMVERNO          | Command      | Queries the firmware version                     |
				| PQTMCFGUART        | Set/Get      | Sets/gets the UART interface                     |
				| PQTMCFGPPS         | Set/Get      | Sets/gets the PPS feature                        |
				| PQTMCFGPROT        | Set/Get      | Sets/gets the input and output protocol for a specified port |
				| PQTMCFGNMEADP      | Set/Get      | Sets/gets the decimal places of standard NMEA messages |
				| PQTMEPE            | Output       | Outputs the estimated position error             |
				| PQTMCFGMSGRATE     | Set/Get      | Sets/gets the message output rate on the current interface |
				| PQTMVEL            | Output       | Outputs the velocity information                 |
				| PQTMCFGGEOFENCE    | Set/Get      | Sets/gets geofence feature                       |
				| PQTMGEOFENCESTATUS | Output       | Outputs the geofence status                      |
				| PQTMGNSSSTART      | Command      | Starts GNSS engine                               |
				| PQTMGNSSSTOP       | Command      | Stops GNSS engine                                |
				| PQTMTXT            | Output       | Outputs short text messages                      |
				| PQTMCFGSVIN        | Set/Get      | Sets/gets the Survey-in feature                  |
				| PQTMSVINSTATUS     | Output       | Outputs the Survey-in status                     |
				| PQTMPVT            | Output       | Outputs the PVT (GNSS only) result               |
				| PQTMCFGRCVRMODE    | Set/Get      | Sets/gets the receiver working mode              |
				| PQTMDEBUGON        | Command      | Enables debug log output                         |
				| PQTMDEBUGOFF       | Command      | Disables debug log output                        |
				| PQTMCFGFIXRATE     | Set/Get      | Sets/gets the fix interval                       |
				| PQTMCFGRTK         | Set/Get      | Sets/gets the RTK mode                           |
				| PQTMCFGCNST        | Set/Get      | Sets/gets the constellation configuration        |
				| PQTMDOP            | Output       | Outputs dilution of precision                    |
				| PQTMPL             | Output       | Outputs protection level information             |
				| PQTMCFGODO         | Set/Get      | Sets/gets the odometer feature                   |
				| PQTMRESETODO       | Command      | Resets the accumulated distance recorded by the odometer |
				| PQTMODO            | Output       | Outputs the odometer information                 |
				| PQTMCFGSIGNAL      | Set/Get      | Sets/gets GNSS signal mask                       |
				| PQTMCFGSAT         | Set/Get      | Sets/gets GNSS satellite mask                    |
				| PQTMCFGRSID        | Set/Get      | Sets/gets the reference station ID               |
				| PQTMCFGRTCM        | Set/Get      | Sets/gets RTCM                                   |
				| PQTMCFGSBAS        | Set/Get      | Configures SBAS                                  |
				| PQTMCFGNMEATID     | Set/Get      | Configures the NMEA Talker ID                    |
				| PQTMTAR            | Output       | Outputs the time and attitude                    |
				| PQTMCFGBLD         | Set/Get      | Configures the baseline distance                 |
				| PQTMCFGRTKSRCTYPE  | Set/Get      | Configures RTK differential source type          |
				| PQTMSN             | Command      | Reads the SN of module                           |
				| PQTMCFGANTINF      | Set/Get      | Configures the antenna information               |
				| PQTMCFGANTDELTA    | Set/Get      | Configures the delta between antennas            |
				| PQTMCFGSIGGRP      | Set/Get      | Configures the GNSS signal group                 |
				| PQTMCFGSIGNAL2     | Set/Get      | Configures GNSS signal mask for second antenna   |
				| PQTMCFGGEOSEP      | Set/Get      | Configures geoidal separation                    |
				| PQTMCFGCNRTHD      | Set/Get      | Configures the CNR threshold for position engine |
				| PQTMCFGELETHD      | Set/Get      | Configures the elevation threshold for position engine |
				| PQTMNAV            | Output       | Outputs the navigation information               |
				| PQTMEOE            | Output       | Outputs the end of epoch information             |
				| PQTMCFGWN          | Set/Get      | Configures the reference start week number       |
				| PQTMANTENNASTATUS  | Output       | Reports the antenna status                       |

				</article>

		=== "QGC"
			A full list of QGC messages (proprietary protocol defined by Quectel) supported by LG290P, is provided in section **3. QGC Protocol** of the [GNSS Protocol Specification](./assets/component_documentation/quectel_lg290p03lgx80p03_gnss_protocol_specification_v1-1.pdf) manual. This protocol is used to output the PPP raw data.

			??? abstract "List of Proprietary Quectel Messages"
				<article style="text-align: center;" markdown>

				| GQC Message Name | Message Group | Message Number | Type | Description |
				| :--------- | :--: | :--: | :----: | :--------------------------------- |
				| RAW-PPPB2B | 0x0A | 0xB2 | Output | BDS PPPB2B binary raw messages     |
				| RAW-QZSSL6 | 0x0A | 0xB6 | Output | QZSSL6 binary raw messages         |
				| RAW-HASE6  | 0x0A | 0xE6 | Output | Galileo HASE6 binary raw messages  |

				</article>

		=== "RTCM"
			A full list of compatible `RTCM v3` messages, is provided in section **4. RTCM Protocol** of the [GNSS Protocol Specification](./assets/component_documentation/quectel_lg290p03lgx80p03_gnss_protocol_specification_v1-1.pdf) manual. This protocol is used for transferring GNSS raw measurement data, as detailed by the [Radio Technical Commission for Maritime Services](https://www.rtcm.org/) organization.

			??? abstract "List of Supported RTCMv3 *(MSM)* Messages"
				<article style="text-align: center;" markdown>

				| Message | Type Mode | Message Description                              |
				| :--: | :----------: | :----------------------------------------------- |
				| 1005 | Input/Output | Stationary RTK Reference Station ARP             |
				| 1006 | Input/Output | Stationary RTK Reference Station ARP with height |
				| 1019 | Input/Output | GPS Ephemerides                                  |
				| 1020 | Input/Output | GLONASS Ephemerides                              |
				| 1041 | Input/Output | NavIC/IRNSS Ephemerides                          |
				| 1042 | Input/Output | BDS Satellite Ephemeris Data                     |
				| 1044 | Input/Output | QZSS Ephemerides                                 |
				| 1046 | Input/Output | Galileo I/NAV Satellite Ephemeris Data           |
				| 1073 | Input/Output | GPS MSM3 |
				| 1074 | Input/Output | GPS MSM4 |
				| 1075 | Input/Output | GPS MSM5 |
				| 1076 | Input/Output | GPS MSM6 |
				| 1077 | Input/Output | GPS MSM7 |
				| 1083 | Input/Output | GLONASS MSM3 |
				| 1084 | Input/Output | GLONASS MSM4 |
				| 1085 | Input/Output | GLONASS MSM5 |
				| 1086 | Input/Output | GLONASS MSM6 |
				| 1087 | Input/Output | GLONASS MSM7 |
				| 1093 | Input/Output | Galileo MSM3 |
				| 1094 | Input/Output | Galileo MSM4 |
				| 1095 | Input/Output | Galileo MSM5 |
				| 1096 | Input/Output | Galileo MSM6 |
				| 1097 | Input/Output | Galileo MSM7 |
				| 1113 | Input/Output | QZSS MSM3 |
				| 1114 | Input/Output | QZSS MSM4 |
				| 1115 | Input/Output | QZSS MSM5 |
				| 1116 | Input/Output | QZSS MSM6 |
				| 1117 | Input/Output | QZSS MSM7 |
				| 1123 | Input/Output | BDS MSM3 |
				| 1124 | Input/Output | BDS MSM4 |
				| 1125 | Input/Output | BDS MSM5 |
				| 1126 | Input/Output | BDS MSM6 |
				| 1127 | Input/Output | BDS MSM7 |
				| 1133 | Input/Output | NavIC/IRNSS MSM3 |
				| 1134 | Input/Output | NavIC/IRNSS MSM4 |
				| 1135 | Input/Output | NavIC/IRNSS MSM5 |
				| 1136 | Input/Output | NavIC/IRNSS MSM6 |
				| 1137 | Input/Output | NavIC/IRNSS MSM7 |

				</article>

=== "PPS Output"
	From the module, the [PPS](https://en.wikipedia.org/wiki/Pulse-per-second_signal "Pulse Per Second") output signal is a 3.3V signal output.

	<figure markdown>
	I/O for PPS signal
	<figcaption markdown>The `PPS` signal's output on the LG290P GNSS Flex module.</figcaption>
	</figure>

	!!! tip "Use Case"
		- Users could use this signal in conjunction with the event pins to synchronize two modules with each other.
		- Users could use this signal to create their own **Stratum 0** source for the [NTP](https://en.wikipedia.org/wiki/Network_Time_Protocol "Network Time Protocol") on a primary time server.

=== "LED Output"
	The `RTK` pin operates as both the `RTK_LED` status indicator for the RTK positioning and `ANT_ON` power control for the external LNA or active antenna power.

	<figure markdown>
	I/O for RTK signal
	<figcaption markdown>The `RTK_LED` pin on the LG290P GNSS Flex module.</figcaption>
	</figure>

	=== "`RTK_LED`"
		In this configuration, the pin is set to a high level at startup.

		1. If the pin output is high, it indicates the module has entered the RTK fixed mode.
		2. If the pin output is low, it indicates that the module exited the RTK fixed mode.
		3. If the pin outputs an alternating pin level, it indicates that the module received the correct RTCM data and did not enter the RTK fixed mode.

	=== "`ANT_ON`"
		In this configuration, the pin is used to control the external LNA or active antenna power supply.

		- When the pin is high, the antenna is powered.
		- When the pin is low, the antenna is not powered.

=== "Event Trigger"
	This pin can be triggered by inputs with an adjustable frequency and polarity.

	<figure markdown>
	Event trigger
	<figcaption markdown>The event pin on the LG290P GNSS Flex module.</figcaption>
	</figure>

	!!! tip "Use Case"
		Users could use this pin in conjunction with the PPS signal to synchronize two modules with each other.

=== "Reset"
	This pin can be used to reset the LG290P module if it enters an abnormal state. To reset the GNSS receiver, the pin must be low for more than 100ms.

	<figure markdown>
	Reset
	<figcaption markdown>The reset pin on the LG290P GNSS Flex module.</figcaption>
	</figure>

## U.FL Connector
Users will need to connect a compatible GNSS antenna to the `Antenna L1/L2/L5/E6` U.FL connector. The type of antenna used with the LG290P module affects the overall accuracy of the positions calculated by the GNSS receiver.

- Passive antennas are not recommended for the LG290P GNSS receiver.
- To mitigate the impact of out-of-band signals, utilize an active antenna whose SAW filter is placed in front of the LNA in the internal framework.
	- **DO NOT** select an antenna with the LNA placed in the front.
- There is no need to inject an external DC voltage for the GNSS antenna. Power is already provided from the LG290P module for the LNA of an active antenna.

<figure markdown>
GNSS antenna input
<figcaption markdown>The U.FL connector to attach an external GNSS antenna to the LG290P GNSS Flex module.</figcaption>
</figure>

!!! tip
	For the best performance, we recommend users choose a compatible L1/L2/L5/L6 GNSS antenna and utilize a low-loss cable. Also, don't forget that GNSS signals are fairly weak and can't penetrate buildings or dense vegetation. The GNSS antenna should have an unobstructed view of the sky.

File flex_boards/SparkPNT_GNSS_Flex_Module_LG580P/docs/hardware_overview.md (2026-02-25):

<article style="text-align: center;" markdown>
Banner
</article>

## Introduction

<div class="grid cards desc" markdown>

-   <a href="https://www.sparkfun.com/sparkpnt-gnss-flex-module-lg580p.html">
	**SparkPNT GNSS Flex Module - LG580P**<br>
	**SKU:** GPS-28870

	---

	<figure markdown>
	Product Thumbnail
	</figure></a>

	<article style="text-align: center;" markdown>
	QR code to product page[Purchase from SparkFun :fontawesome-solid-cart-plus:{ .heart }](https://www.sparkfun.com/sparkpnt-gnss-flex-module-lg580p.html){ .md-button .md-button--primary }
	</article>

-   SparkPNT GNSS Flex modules are plug-in boards featuring different GNSS receivers. They are designed to be easily swapped for repairs and pin-compatible for upgrades. The boards have two 2x10-pin, 2mm pitch female headers connecting to carrier boards. For the LG580P GNSS receiver, these pins will break out the USB, UART (x3), and I^2^C* interfaces, along with the PPS and event signals using a standardized pinout.

	This SparkPNT GNSS Flex module is an upgraded version of the [LG290P GNSS Flex module](../SparkPNT_GNSS_Flex_Module_LG290P/index.md). It features the Quectel LG580P quad-band, multi-constellation, high-precision, RTK and heading GNSS receiver with two antenna inputs for instantaneous heading determination down to 0.1&deg;. In traditional navigation systems, such as those used on your phone or car, previous navigation points are utilized to determine the course heading. This is the reason why the arrow indicator will spin or be oriented in the wrong directions when the navigation system first boots or has been stationary for extended periods of time. However, with the LG580 GNSS receiver, users are provided with a dedicated heading without relying on previous course data points, magnetometers/compasses, or gyroscopes in IMUs, which can introduce small errors.

	The LG580P module offers a diverse choice of interfaces including UART, SPI*, I<sup>2</sup>C*, and CAN*. Additionally, the module is capable of simultaneously receiving signals from the `L1`, `L2`, `L5`, and `L6`/`E6` frequency bands of the GPS, GLONASS, Galileo, BDS, QZSS, and NavIC GNSS constellations. In addition, the module supports SBAS augmentation systems (WAAS, EGNOS, BDSBAS, MSAS, GAGAN, KASS, ASECNA, SouthPAN, and SDCM), PPP services* (BDS PPP-B2b, QZSS CLAS, MADOCA-PPP, and Galileo HAS), RTCM, and RTK corrections for precision navigation with a fast convergence time and reliable performance.

	The built-in professional-grade interference signal detection and elimination algorithms, effectively mitigate multiple narrow-band interference sources and significantly improve signal reception performance in complex electromagnetic environments. In addition, the RTK and heading algorithms ensure reliable positioning in challenging scenarios such as urban environments and deep tree cover. With its high-precision, low power consumption and a high positioning and heading update rate of up to 20 Hz, this board is ideal for high-precision navigation applications, such as intelligent robots, precision agriculture, ADAS, and autonomous driving.

	!!! warning "Features Under Development"
		- **I^2^C/SPI/CAN** - Currently, only the UART interface is supported by the module.
		- **PPP Services** - Corrections for some of the PPP services have not been implemented.

</div>

## :material-folder-cog: Design Files

<!-- Import the component -->
<script type="module" src="https://ajax.googleapis.com/ajax/libs/model-viewer/4.0.0/model-viewer.min.js"></script>

<div class="grid cards desc" markdown>

-   :kicad-primary:{ .enlarge-logo } Design Files

	---

	- :fontawesome-solid-file-pdf: [Schematic](./assets/board_files/schematic.pdf)
	- :material-folder-zip: [KiCad Files](./assets/board_files/kicad_files.zip)
	- :material-rotate-3d: [STEP File](./assets/3d_model/cad_model.step)
	- :fontawesome-solid-file-pdf: [Board Dimensions](./assets/board_files/dimensions.pdf):
		- 1.75" x 1.25" (44.45mm x 31.75mm)

-   <!-- Boxes in tabs -->

	=== "3D Model"
		<article style="text-align: center;" markdown>
		<model-viewer src="../assets/3d_model/web_model.glb" camera-controls poster="../assets/3d_model/poster.png" tone-mapping="neutral" shadow-intensity="2" shadow-softness="0.2" camera-orbit="90deg 75deg 0.103m" field-of-view="25.11deg" style="width: 100%; height: 450px;">
		</model-viewer>

		[Download the `*.step` File](./assets/3d_model/cad_model.step "Click to download"){ .md-button .md-button--primary width="250px" }

		</article>

		???+ tip "Manipulate 3D Model"
			<article style="text-align: center;" markdown>

			| Controls       | Mouse                    | Touchscreen    |
			| :------------- | :----------------------: | :------------: |
			| Zoom           | Scroll Wheel             | 2-Finger Pinch |
			| Rotate         | ++"Left-Click"++ & Drag  | 1-Finger Drag  |
			| Move/Translate | ++"Right-Click"++ & Drag | 2-Finger Drag  |

			</article>

	=== "Dimensions"
		<article style="text-align: center;" markdown>
		Board Dimensions
		<figcaption markdown>Dimensions of the LG580P GNSS Flex module.</figcaption>
		</article>

		???+ tip "Need more measurements?"
			For more information about the board's dimensions, users can download the [KiCad files](./assets/board_files/kicad_files.zip) for this board. These files can be opened in KiCad and additional measurements can be made with the measuring tool.

			!!! info ":octicons-download-16:{ .heart } KiCad - Free Download!"
				KiCad is free, open-source [CAD]("computer-aided design") program for electronics. Click on the button below to download their software. *(\*Users can find out more information about KiCad from their [website](https://www.kicad.org/).)*

				<article style="text-align: center;" markdown>
				[Download :kicad-primary:{ .enlarge-logo }](https://www.kicad.org/download/ "Go to downloads page"){ .md-button .md-button--primary width="250px" }
				</article>

			???+ info ":straight_ruler: Measuring Tool"
				This video demonstrates how to utilize the dimensions tool in KiCad, to include additional measurements:

				<article class="video-500px" style="text-align: center; margin: auto;" markdown>
				<iframe src="https://www.youtube.com/embed/-eXuD8pkCYw" title="KiCad Dimension Tool" frameborder="0" allow="accelerometer; autoplay; clipboard-write; encrypted-media; gyroscope; picture-in-picture" allowfullscreen></iframe>
				QR code to play video
				</article>

</div>

## Board Layout
The GNSS Flex system is designed around two 2x10-pin, 2mm pitch headers used mate the two types of boards. A standardized pin layout, keeps the ecosystem pin-compatible for upgrades and allows board to be easily swapped for repairs. Depending on the capabilities of the GNSS receiver, these pins will breakout the USB, UART (x4), I^2^C, and SD card interfaces along with any PPS or event signals of the GNSS receiver.

The LG580P GNSS Flex module has the following features:

<div class="grid" markdown>

<div markdown>

<figure markdown>
Layout
<figcaption markdown>Layout of the major components on the LG580P GNSS Flex module.</figcaption>
</figure>

</div>

<div markdown>

1. **LG580P GNSS Receiver**
:	The Quectel LG580P GNSS receiver
1. **GNSS Flex Headers**
:	Two sets of 2x10 pin, 2mm pitch female headers for connecting a GNSS Flex module to *carrier boards*
1. **U.FL Connectors**
:	Two U.FL connectors for attaching external GNSS antennas

</div>

</div>

## LG580P GNSS Receiver
The centerpiece of the LG580P GNSS Flex module, is the [LG580P GNSS receiver](./assets/component_documentation/quectel_lg580p03_hardware_design_v1-0.pdf) from [Quectel](https://www.quectel.com/). The LG580P is a low-power, multi-band, multi-constellation GNSS receiver capable of delivering centimeter-level precision at high update rates. The built-in professional-grade interference signal detection and elimination algorithms, effectively mitigate multiple narrow-band interference sources and significantly improve signal reception performance in complex electromagnetic environments. In addition, the RTK and heading algorithms ensure reliable positioning in challenging scenarios such as urban environments and deep tree cover. With its performance advantages of high-precision and power consumption, this board is an ideal choice for high-precision navigation applications, such as intelligent robots, UAVs, precision agriculture, mining, surveying, and autonomous navigation.

<div class="grid cards" markdown>

<div style="text-align: center;" markdown>

QR code to product video

<article class="video-500px" style="margin: auto;" markdown>
<iframe src="https://player.vimeo.com/video/1115089915?h=127c90c2a9" title="Quectel: Product Intro for LG580P GNSS Receiver" frameborder="0" allow="accelerometer; autoplay; clipboard-write; encrypted-media; gyroscope; picture-in-picture" allowfullscreen></iframe>
</article>

</div>

-   <figure markdown>
	LG580P GNSS receiver
	<figcaption markdown>The LG580P module on the LG580P GNSS Flex module.</figcaption>
	</figure>

</div>

<div class="grid" markdown>

<div markdown>

**Features:**

- Supply Voltage: **3.0–3.6V**
- Tracking Channels: 1040
- Concurrent signal reception: 5 + QZSS
	- `L1`, `L2`, `L5`, `E6` frequency bands
- Sensitivity:
	- Acquisition: -145dBm
	- Tracking: -160dBm
	- Reacquisition: -155dBm
- Antenna Power: External
- GNSS Constellations and SBAS Systems:
	- **USA:** GPS + WASS
	- **Russia:** GLONASS + SDCM
	- **EU:** Galileo + EGNOS
	- **China:** BDS + BDSDAS
	- **Japan:** QZSS + MSAS
	- **India:** NavIC + GAGAN
	- **Korea:** KASS
	- **Africa:** ASECNA
	- **Auz/NZ:** SouthPAN
- Accuracy of 1PPS Signal: 5ns
- Update Rate:
	- Default: 10Hz
	- Max: 20Hz

</div>

<div markdown>

<br>

- Time to First Fix *(without AGNSS)*:
	- Cold Start: 28s
	- Warm Start: 28s
	- Hot Start: 1.8s
- RTK Convergence Time: 5s
- Dynamic Performance:
	- Maximum Altitude: 10000m
	- Maximum Velocity: 490m/s
	- Maximum Acceleration: 4g
- Interfaces
	- UART (x3)
		- Baud Rate: 9600–3000000bps
			- **Default:** 460800bps
		- Protocol: `NMEA 0183`/`RTCM 3.x`/`QGC`
	- SPI[^1] (x1)
	- I^2^C[^1] (x1)
	- CAN[^1] (x1)
- Operating temperature: -40&deg;C to +85&deg;C
- Footprint: 21mm × 16mm × 2.7mm
- Weight: 1.4g

</div>

</div>

[^1]:
	!!! warning "Feature Under Development"
		Currently, only the UART interface is supported by the module. Support for the **I^2^C**, **SPI**, and **CAN** interfaces are still under development.

### Power Consumption
The power consumption of the LG580P GNSS receiver depends on the GNSS signals enabled and the positioning mode.

<div class="grid" markdown>

<article style="text-align: center;" markdown>

| Mode | Power (mW) | Current (mA) |
| :--- | :---: | :---: |
| Acquisition | 323.4 | 98 |
| Tracking | 382.8 | 116 |
| Backup | 59.4 | 0.018 |

</article>

<div markdown>

!!! info "Power Modes"

	**Acquisition:**
	:   Module searches for satellites and to determine visible satellites, coarse frequency, and the code phase of satellite signals

	**Tracking:**
	:   Once acquisition is completed, the module tracks satellites and demodulates the navigation data from specific satellites

	**Backup Mode:**
	:   Reduces power consumption. Only backup domain is active and keeps track of time.

</div>

</div>

### Frequency Bands
The LG580P modules are multi-band, multi-constellation GNSS receivers. Below, is a chart illustrating the frequency bands utilized by all the global navigation satellite systems; along with a list of the frequency bands and GNSS systems supported by the LG580P GNSS receiver.

<figure markdown>
GNSS frequency bands (https://www.tallysman.com/app/uploads/2021/07/Tallysman-GNSS-Frequencies-v8.0_Chart-1-1024x425.png "Click to enlarge")
<figcaption markdown>Frequency bands of the global navigation satellite systems. (Source: [Tallysman](https://www.tallysman.com/gnss-constellations-radio-frequencies-and-signals/))</figcaption>
</figure>

<div class="grid" markdown>

<div markdown>

**Supported Frequency Bands:**

- GPS: `L1 C/A`, `L5`, `L2C`
- GLONASS: `L1`, `L2`
- Galileo: `E1`, `E5a`, `E5b`, `E6`
- BDS: `B1I`, `B1C`, `B2a`, `B2b`, `B2I`, `B3I`
- QZSS: `L1 C/A`, `L5`, `L2C`, `L6`
- NavIC: `L5`
- SBAS: `L1`
- L-band PPP[^2]:
	- PPP: `B2b`
	- QZSS: `L6`
	- Galileo HAS: `E6`

</div>

<div markdown>

**Supported GNSS Constellations:**

- GPS (USA)
- GLONASS (Russia)
- Galileo (EU)
- BDS (China)
- QZSS (Japan)
- NavIC (India)

**Supported SBAS Systems:**

- WASS (USA)
- SDCM (Russia)
- EGNOS (EU)
- BDSBAS (China)
- MSAS (Japan)
- GAGAN (India)
- KASS (Korea)
- ASECNA (Africa)
- SouthPAN (Aus/NZ)

</div>

</div>

[^2]:
	!!! warning "Feature Under Development"
		Corrections for some of the PPP services have not been implemented.

!!! info
	For a comparison of the frequency bands supported by the LG580P GNSS receivers, refer to sections **1.2**, **1.5**, and **1.6** of the [hardware design manual](./assets/component_documentation/quectel_lg580p03_hardware_design_v1-0.pdf).

??? info "What are Frequency Bands?"
	A [frequency band](https://en.wikipedia.org/wiki/Frequency_band) is a section of the [electromagnetic spectrum](https://en.wikipedia.org/wiki/Electromagnetic_spectrum), usually denoted by the range of its upper and lower limits. In the [radio spectrum](https://en.wikipedia.org/wiki/Radio_spectrum), these frequency bands are usually regulated by region, often through a government entity. This regulation prevents the interference of RF communication; and often includes major penalties for any interference with critical infrastructure systems and emergency services.

	<figure markdown>
	GNSS frequency bands (https://gssc.esa.int/navipedia/images/c/cf/GNSS_All_Signals.png "Click to enlarge")
	<figcaption markdown>Frequency bands of the global navigation satellite systems. (Source: [ESA](https://gssc.esa.int/navipedia/index.php?title=File:GNSS_All_Signals.png "European Space Agency"))</figcaption>
	</figure>

	However, if the various GNSS constellations share similar frequency bands, then how do they avoid interfering with one another? Without going too far into detail, the image above illustrates the frequency bands of each system with a few characteristics specific to their signals. Wit these characteristics in mind, along with other factors, the chart can help users to visualize how multiple GNSS constellations might co-exist with each other.

	For more information, users may find these articles of interest:

	- [GNSS signal](https://gssc.esa.int/navipedia/index.php/GNSS_signal)
	- [GPS Signal Plan](https://gssc.esa.int/navipedia/index.php?title=GPS_Signal_Plan)
	- [GLONASS Signal Plan](https://gssc.esa.int/navipedia/index.php?title=GLONASS_Signal_Plan)
	- [GALILEO Signal Plan](https://gssc.esa.int/navipedia/index.php?title=GALILEO_Signal_Plan)
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

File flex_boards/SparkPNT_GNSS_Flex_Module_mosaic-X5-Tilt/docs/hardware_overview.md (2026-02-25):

<article style="text-align: center;" markdown>
Banner
</article>

!!! danger
	!!! warning "ESD Sensitivity"
		The mosaic-X5 GNSS receiver is sensitive to [ESD](https://en.wikipedia.org/wiki/Electrostatic_discharge "Electrostatic Discharge"). Use a proper grounding system to make sure that the working surface and the components are at the same electric potential.

		??? info "ESD Precaution"
			As recommended by the manufacturer, we highly recommend that users take the necessary precautions to avoid damaging their module. For example, users can utilize the [iFixit Anti-Static Wrist Strap](https://www.sparkfun.com/ifixit-anti-static-wrist-strap.html).

			<article class="video-500px" style="text-align: center; margin: auto;" markdown>
			QR code to product video
			<iframe src="https://www.youtube.com/embed/hrL5J6Q5gX8?si=jOPBat8rzMnL7Uz4&amp;start=26;&amp;end=35;" title="Septentrio: Getting Started Video (playback starts at ESD warning)" frameborder="0" allow="accelerometer; autoplay; clipboard-write; encrypted-media; gyroscope; picture-in-picture" allowfullscreen></iframe>
			</article>

	!!! warning "Active Antenna"
		Never inject an external DC voltage into the GNSS antenna, as it may damage the mosaic-X5 GNSS receiver. For instance, when using a splitter to distribute the antenna signal to several GNSS receivers, make sure that no more than one output of the splitter passes DC. Use [DC-blocks](https://en.wikipedia.org/wiki/DC_block) otherwise.

## Introduction

<div class="grid cards desc" markdown>

-   <a href="https://www.sparkfun.com/sparkpnt-gnss-flex-module-mosaic-x5-im19-imu.html">
	**SparkPNT GNSS Flex Module - mosaic-X5 & IM19 IMU**<br>
	**SKU:** GPS-29457

	---

	<figure markdown>
	Product Thumbnail
	</figure></a>

	<article style="text-align: center;" markdown>
	QR code to product page
	[Purchase from SparkFun :fontawesome-solid-cart-plus:{ .heart }](https://www.sparkfun.com/sparkpnt-gnss-flex-module-mosaic-x5-im19-imu.html){ .md-button .md-button--primary }
	</article>

-   SparkPNT GNSS Flex modules are plug-in boards featuring different GNSS receivers. They are designed to be easily swapped for repairs and pin-compatible for upgrades. The boards have two 2x10-pin, 2mm pitch female headers connecting to carrier boards. For the mosaic-X5 GNSS receiver, these pins will break out the USB, UART (x2), and SD card interfaces, along with the PPS and event signals using a standardized pinout. Additionally, these pins break out the two UART interfaces of the IM19 IMU.
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

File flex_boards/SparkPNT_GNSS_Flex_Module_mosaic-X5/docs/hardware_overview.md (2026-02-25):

<article style="text-align: center;" markdown>
Banner
</article>

!!! danger
	!!! warning "ESD Sensitivity"
		The mosaic-X5 GNSS receiver is sensitive to [ESD](https://en.wikipedia.org/wiki/Electrostatic_discharge "Electrostatic Discharge"). Use a proper grounding system to make sure that the working surface and the components are at the same electric potential.
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

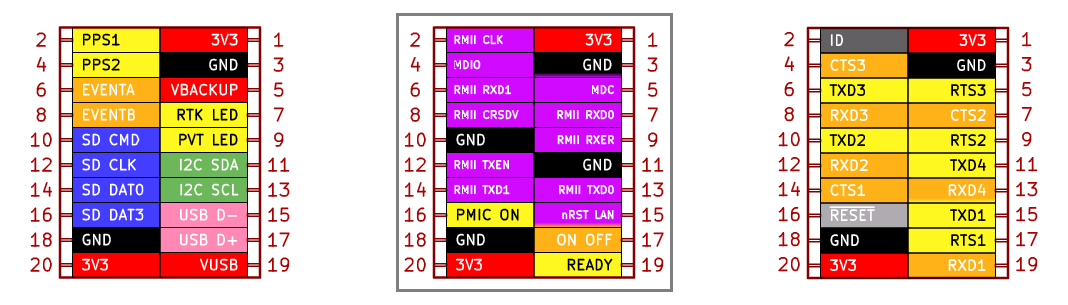
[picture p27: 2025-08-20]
flex_boards/SparkPNT_GNSS_Flex_Module_mosaic-X5/docs/assets/img/hookup_guide/headers-pinout2.png

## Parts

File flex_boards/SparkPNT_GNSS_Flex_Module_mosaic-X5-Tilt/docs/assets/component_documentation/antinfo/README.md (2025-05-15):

antinfo directory
====================

A copy of the latest antenna information package; at the time of the repository's latest release.

- [Antenna Information Package](antinfo-25.1.0-mosaic-X5.suf) (SUF)
- [Release Notes](mosaic-X5_antinfo25.1.0_release_notes.pdf) (PDF)

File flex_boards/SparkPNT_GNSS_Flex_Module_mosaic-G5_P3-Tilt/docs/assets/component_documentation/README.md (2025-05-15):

SparkFun Documentation
=======================

This directory should include any necessary datasheets, example number crunching, etc.

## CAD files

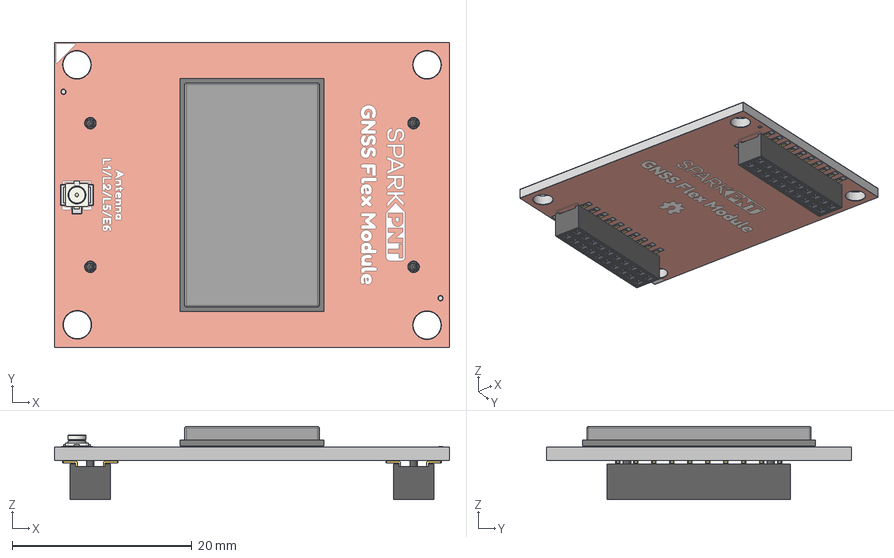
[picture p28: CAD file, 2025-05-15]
docs/assets/3d_model/GNSS_Flex-Generic_Module.step
44.0 x 34.0 x 8.18 mm
ublox_SARA_LGA-96
U.FL
05X02_PW62 x 40
FH20_2XNP_H40_W45_U_DZ x 2
SparkFun_GNSS_Flex_Module_LG290P_pad
SparkFun_GNSS_Flex_Module_LG290P_silkscreen
SparkFun_GNSS_Flex_Module_LG290P_soldermask
SparkFun_GNSS_Flex_Module_LG290P_PCB

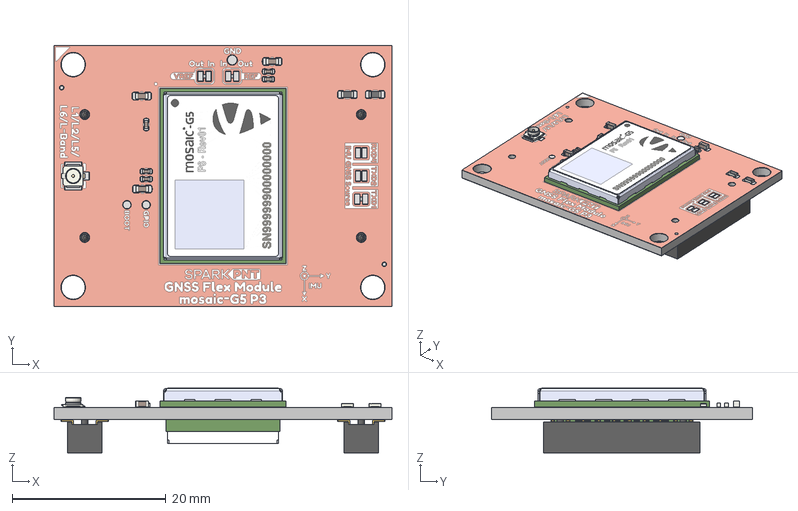
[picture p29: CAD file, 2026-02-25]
flex_boards/SparkPNT_GNSS_Flex_Module_mosaic-G5_P3-Tilt/docs/assets/3d_model/cad_model.step
44.0 x 34.0 x 8.45 mm
R_0603_1608Metric x 2
C_0402_1005Metric x 5
C_0603_1608Metric x 3
PAR-00001479
PAR-00000856
PAR-00001478
U.FL
05X02_PW62 x 40
FH20_2XNP_H40_W45_U_DZ x 2
Board
Extruded x 2
Extruded_3
Extruded_6 x 2
Extruded_4
Extruded_5 x 2
Extruded_2
STM-UFBGA169 x 171
mosaic-G5_P3_Tilt_pad
mosaic-G5_P3_Tilt_silkscreen
mosaic-G5_P3_Tilt_soldermask
mosaic-G5_P3_Tilt_PCB

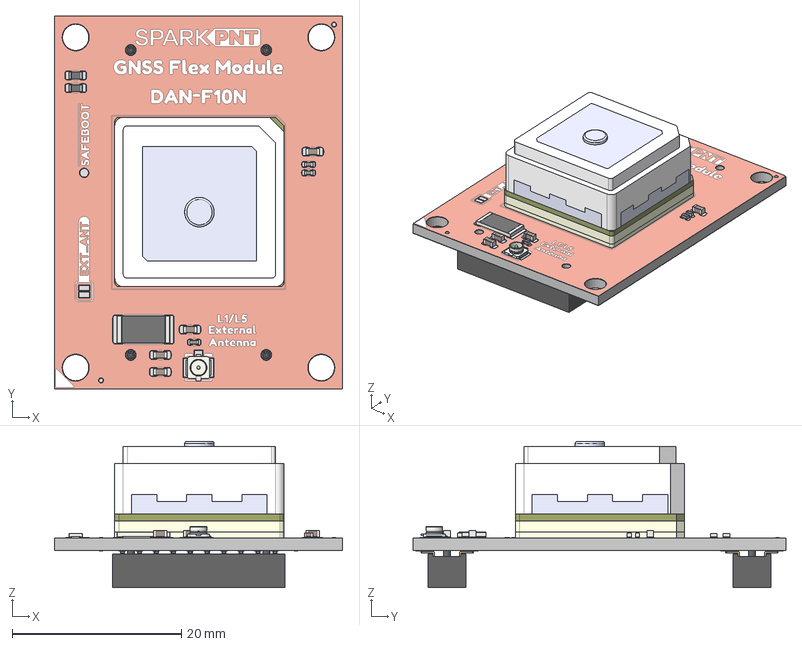
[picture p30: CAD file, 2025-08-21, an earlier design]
flex_boards/SparkPNT_GNSS_Flex_Module_DAN-F10N/docs/assets/3d_model/cad_model.step
34.0 x 44.0 x 17.3 mm
C_0603_1608Metric x 4
R_2512_6332Metric
C_0402_1005Metric x 3
R_0603_1608Metric x 2
DAN_TAO_Taoglas_Antenna
DAN_TAO_DAN-F10N_Interposer_DAN-F10N_Interposer_BOARD
DAN_TAO_DAN-F10N_Eiplus_Main_Board_DAN-F10N_Eiplus_Main_Board_BOARD
DAN_TAO_Bottom Layer_DAN-F10N_Eiplus_Main_Board_DAN-F10N_Eiplus_Main_Board.sldasm_0
DAN_TAO_Bottom Layer_DAN-F10N_Eiplus_Main_Board_DAN-F10N_Eiplus_Main_Board.sldasm_1
DAN_TAO_Bottom SolderMask_DAN-F10N_Eiplus_Main_Board_DAN-F10N_Eiplus_Main_Board.sldasm_ 0
U.FL
05X02_PW62 x 40
FH20_2XNP_H40_W45_U_DZ x 2
SparkFun_GNSS_Flex_Module_DAN-F10N_pad
SparkFun_GNSS_Flex_Module_DAN-F10N_silkscreen
SparkFun_GNSS_Flex_Module_DAN-F10N_soldermask
SparkFun_GNSS_Flex_Module_DAN-F10N_PCB

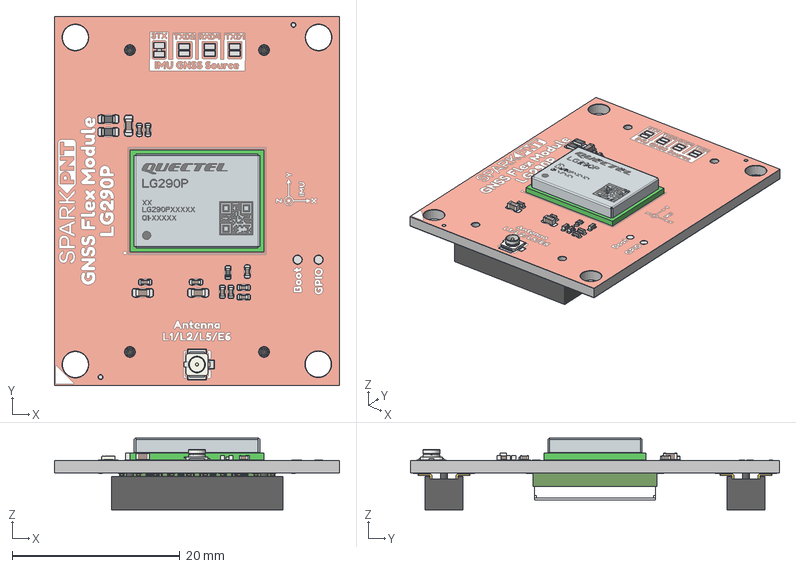
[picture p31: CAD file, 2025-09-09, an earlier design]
flex_boards/SparkPNT_GNSS_Flex_Module_LG290P-Tilt/docs/assets/3d_model/cad_model.step
34.0 x 44.0 x 8.58 mm
C_0402_1005Metric x 9
C_0603_1608Metric x 3
R_0402_1005Metric
LG290P-PCB
LG290P-COVER
R_0603_1608Metric x 2
U.FL
Board
Extruded x 2
Extruded_3
Extruded_6 x 2
Extruded_4
Extruded_5 x 2
Extruded_2
STM-UFBGA169 x 171
05X02_PW62 x 40
FH20_2XNP_H40_W45_U_DZ x 2
SparkFun_GNSS_Flex_Module_LG290P-Tilt_pad
SparkFun_GNSS_Flex_Module_LG290P-Tilt_silkscreen
SparkFun_GNSS_Flex_Module_LG290P-Tilt_soldermask
SparkFun_GNSS_Flex_Module_LG290P-Tilt_PCB

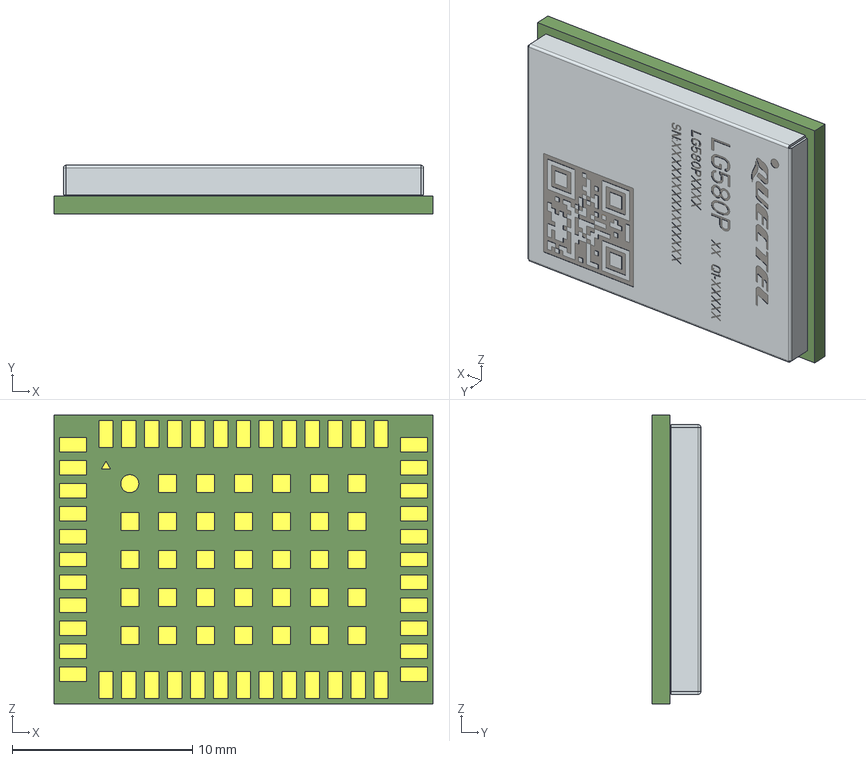
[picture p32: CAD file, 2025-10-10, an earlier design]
flex_boards/SparkPNT_GNSS_Flex_Module_LG580P/docs/assets/3d_model/cad_model.step
21.0 x 2.70 x 16.0 mm
LG580P-COVER x 50
LG580P-PCB

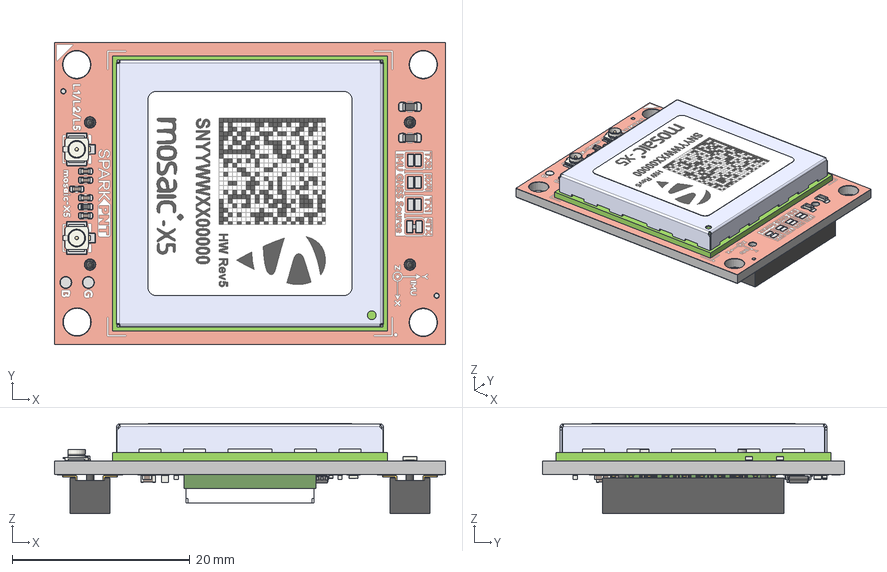
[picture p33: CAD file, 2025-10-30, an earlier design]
flex_boards/SparkPNT_GNSS_Flex_Module_mosaic-X5-Tilt/docs/assets/3d_model/cad_model.step
44.0 x 34.0 x 10.1 mm
R_0402_1005Metric x 3
R_0603_1608Metric x 4
C_0402_1005Metric x 12
U.FL x 2
PAR-00001366
PAR-00000988(Default)
PAR-00001381
VSSOP-8_2.3x2mm_P0.5mm
C_0603_1608Metric x 3
Board
Extruded x 2
Extruded_3
Extruded_6 x 2
Extruded_4
Extruded_5 x 2
Extruded_2
STM-UFBGA169 x 171
05X02_PW62 x 40
FH20_2XNP_H40_W45_U_DZ x 2
SparkFun_GNSS_Flex_Module_mosaic-X5_IM19_pad
SparkFun_GNSS_Flex_Module_mosaic-X5_IM19_silkscreen
SparkFun_GNSS_Flex_Module_mosaic-X5_IM19_soldermask
SparkFun_GNSS_Flex_Module_mosaic-X5_IM19_PCB

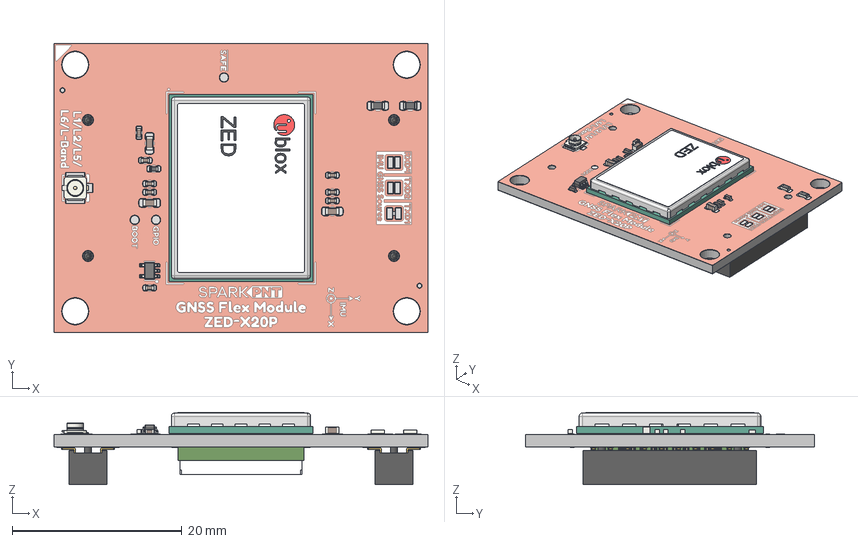
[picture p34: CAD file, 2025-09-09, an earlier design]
flex_boards/SparkPNT_GNSS_Flex_Module_ZED-X20P-Tilt/docs/assets/3d_model/cad_model.step
44.0 x 34.0 x 8.48 mm
R_0603_1608Metric x 2
C_0402_1005Metric x 8
C_0603_1608Metric x 3
R_0402_1005Metric
SOT-353_SC-70-5
Imported x 103
Imported_6 x 7
Imported_5
Imported_2
Imported_3
Imported_4
U.FL
05X02_PW62 x 40
FH20_2XNP_H40_W45_U_DZ x 2
Board
Extruded x 2
Extruded_3
Extruded_6 x 2
Extruded_4
Extruded_5 x 2
Extruded_2
STM-UFBGA169 x 171
ZED-X20P_Tilt_pad
ZED-X20P_Tilt_silkscreen
ZED-X20P_Tilt_soldermask
ZED-X20P_Tilt_PCB

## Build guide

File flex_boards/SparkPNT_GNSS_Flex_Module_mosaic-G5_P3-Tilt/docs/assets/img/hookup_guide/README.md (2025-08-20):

hookup_guide directory
====================
This folder should contain images for the hookup guide

## Default Image Sizes

- **PCB:** 580px x 750px
- **PCB w/ Border:** 630px x 800px
- **Top & Bottom View:** 1250px x 800px

## Template Files
Files that are inherently included for all GNSS Flex modules

- `animation-attach_module.gif` - Side view for connecting the Flex board
- `animation-attach_module2.gif` - Isometric view for connecting the Flex boards with alignment
- `assembly-ufl_bridge.jpg` - U.FL cable bridging the antenna connection
- `assembly-ufl_connector.jpg` - Attaching the U.FL cable to the GNSS Flex module
- `headers-flex_module.png` - Template for pin connections of the GNSS Flex headers
- `headers-flex_module+gap.png` - Template for pin connections of the GNSS Flex headers w/ gap for 3rd header
- `headers-flex_module+opt.png` - Template for pin connections of the GNSS Flex headers w/ box for 3rd header
- `module-pinout.png` - Pin connections of the GNSS Flex headers with the board w/ alignment marker
- `module-pinout-carrier_height.png` - Pin connections of the GNSS Flex headers with the board, sized to carrier board template
- `module-pinout-carrier_height2.png` - Pin connections of the GNSS Flex headers with the board, sized to carrier board template w/ alignment marker

## Layout Files
Files that are specific to this GNSS Flex module

- `ant.png` - Annotated image of the U.FL connector
- `headers.png` - Annotated image of the GNSS FLex headers
- `jumpers.png` - Annotated image of the jumpers
- `layout.png` - Annotated image for the board layout
- `<GNSS Receiver>.png` - Annotated image of the GNSS receiver
- `orientation.png` - Annotated image of the alignment marker

### Template Images

- `bottom.png` - Template image for the bottom of the board, using the default image size
- `layout-bottom.png` - Template image for the bottom of the board w/ background, using the default image size
- `layout-template.png` - Template image for both sides of the board, using the default image size
- `layout-top.png` - Template image for the top of the board w/ background, using the default image size
- `top.png` - Template image for the top of the board, using the default image size

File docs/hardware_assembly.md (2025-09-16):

## Board Alignment
The GNSS Flex system is a modular ecosystem designed around two 2x10-pin, 2mm pitch headers, so boards are pin-compatible for upgrades and easily swapped for repairs. Users simply, stack a SparkPNT GNSS Flex module onto the headers of its associated *carrier* board. The alignment of these boards is annotated with a triangle in the corner of the mating area.

<figure markdown>
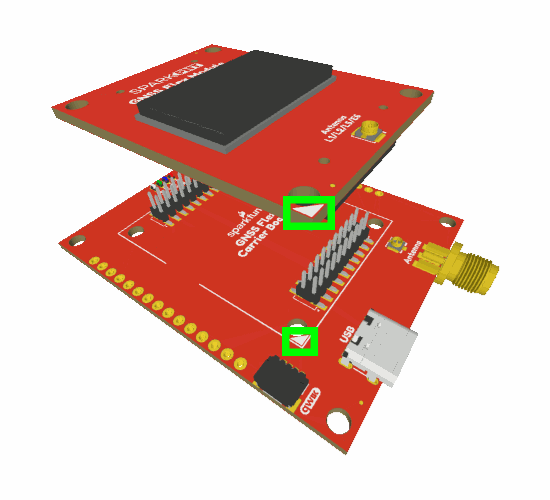
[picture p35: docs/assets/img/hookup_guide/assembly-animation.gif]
Flex system board mating

<figcaption markdown>The alignment and connection of a SparkPNT GNSS Flex module on top of a *carrier* board.</figcaption>
</figure>

## External Antenna
In order to receive [GNSS](https://en.wikipedia.org/wiki/Satellite_navigation "Global Navigation Satellite System") signals, users will need a compatible antenna. For the best performance, we recommend an active, L1/L2/L5/L6 GNSS antenna.

- External antennas can be connected through the U.FL connector on the GNSS Flex board.
- For a sturdier connection, there is a signal pass-through between the U.FL and SMA antenna connectors of the Flex carrier boards. Users can to bridge the U.FL connections of the boards to utilize the SMA connector for a GNSS antenna.

<div class="grid" markdown>

<div markdown>

<figure markdown>
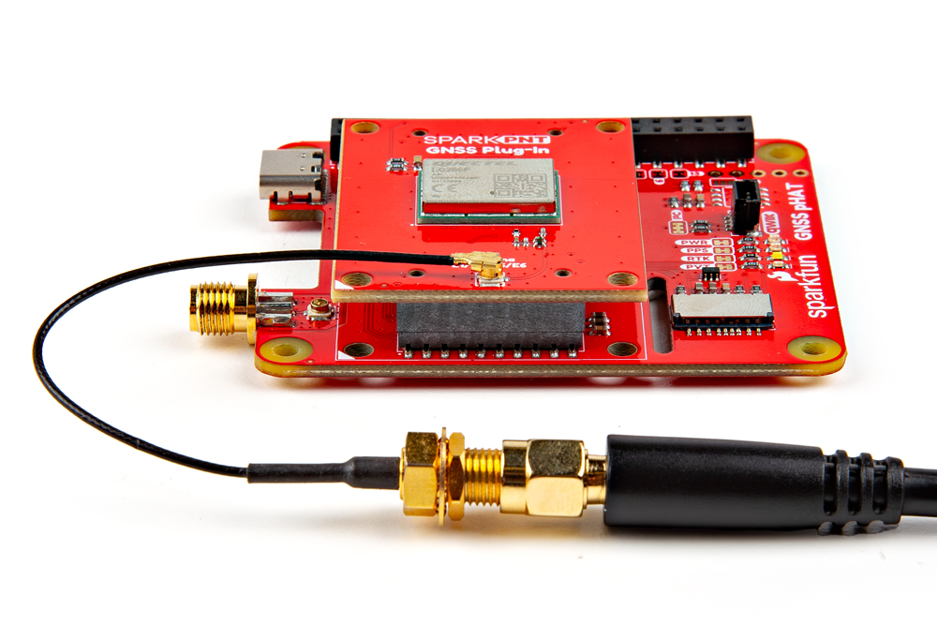
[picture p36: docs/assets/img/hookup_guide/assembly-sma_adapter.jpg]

<figcaption markdown>Attaching an antenna directly to the GNSS Flex board.</figcaption>
</figure>

</div>

<div markdown>

<figure markdown>
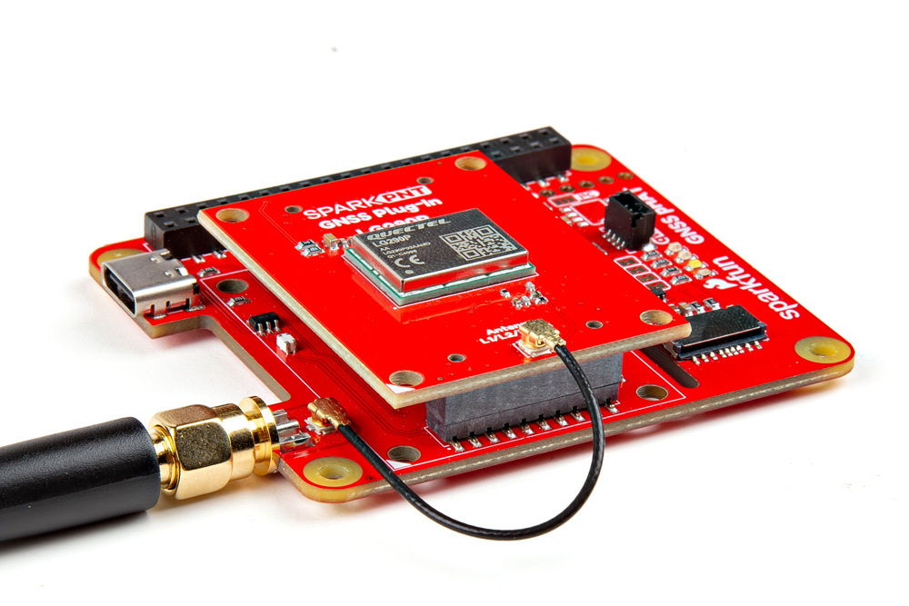
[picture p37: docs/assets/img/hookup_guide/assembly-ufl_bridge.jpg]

<figcaption markdown>Bridging the U.FL connections to utilize the SMA connector on a *carrier* board.</figcaption>
</figure>

</div>

</div>

!!! tip
	For the best performance, we recommend users choose a compatible L1/L2/L5/L6 GNSS antenna and utilize a low-loss cable. Also, don't forget that GNSS signals are fairly weak and can't penetrate buildings or dense vegetation. The GNSS antenna should have an unobstructed view of the sky.

	!!! note
		Please keep in mind that these are general suggestions for our GNSS Flex modules. Some of these boards may have multiple GNSS antenna connections, an integrated antenna, support specific frequency bands, etc. For more details on a specific GNSS Flex module, please refer to their [hookup guide](modules.md).

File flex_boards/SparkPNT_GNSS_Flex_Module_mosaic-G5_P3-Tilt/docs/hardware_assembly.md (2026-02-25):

!!! danger
	!!! warning "ESD Sensitivity"
		The mosaic-G5 P3 GNSS receiver is sensitive to [ESD](https://en.wikipedia.org/wiki/Electrostatic_discharge "Electrostatic Discharge"). Use a proper grounding system to make sure that the working surface and the components are at the same electric potential.

		??? info "ESD Precaution"
			As recommended by the manufacturer, we highly recommend that users take the necessary precautions to avoid damaging their module. For example, users can utilize the [iFixit Anti-Static Wrist Strap](https://www.sparkfun.com/ifixit-anti-static-wrist-strap.html).

			<article class="video-500px" style="text-align: center; margin: auto;" markdown>
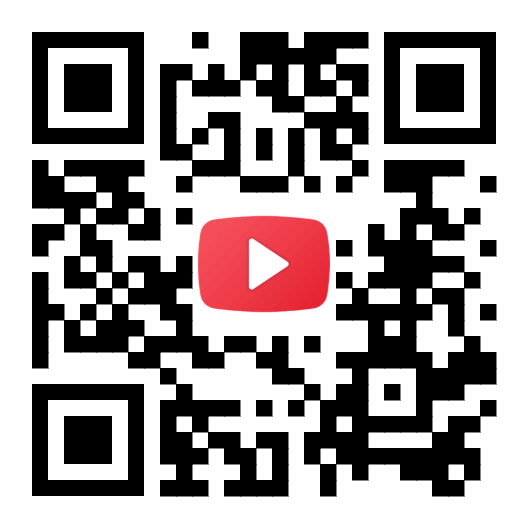
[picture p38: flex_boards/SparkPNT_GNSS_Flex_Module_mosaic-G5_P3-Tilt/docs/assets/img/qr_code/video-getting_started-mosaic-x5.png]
QR code to product video
			
			<iframe src="https://www.youtube.com/embed/hrL5J6Q5gX8?si=jOPBat8rzMnL7Uz4&amp;start=26;&amp;end=35;" title="Septentrio: Getting Started Video (playback starts at ESD warning)" frameborder="0" allow="accelerometer; autoplay; clipboard-write; encrypted-media; gyroscope; picture-in-picture" allowfullscreen></iframe>
			</article>

	!!! warning "Active Antenna"
		Never inject an external DC voltage into the GNSS antenna, as it may damage the mosaic-G5 P3 GNSS receiver. For instance, when using a splitter to distribute the antenna signal to several GNSS receivers, make sure that no more than one output of the splitter passes DC. Use [DC-blocks](https://en.wikipedia.org/wiki/DC_block) otherwise.

## GNSS Antenna
In order to receive [GNSS](https://en.wikipedia.org/wiki/Satellite_navigation "Global Navigation Satellite System") signals, users will need to connect a compatible antenna. For the best performance, we recommend users choose an active, L1/L2/L5/L6/L-Band GNSS antenna and utilize a low-loss cable.

### U.FL Connector
GNSS antennas are connected to the U.FL connector on the GNSS Flex board. For sturdier connections, users have the option to bridging the connection to the SMA connector on a Flex carrier board.

<figure markdown>
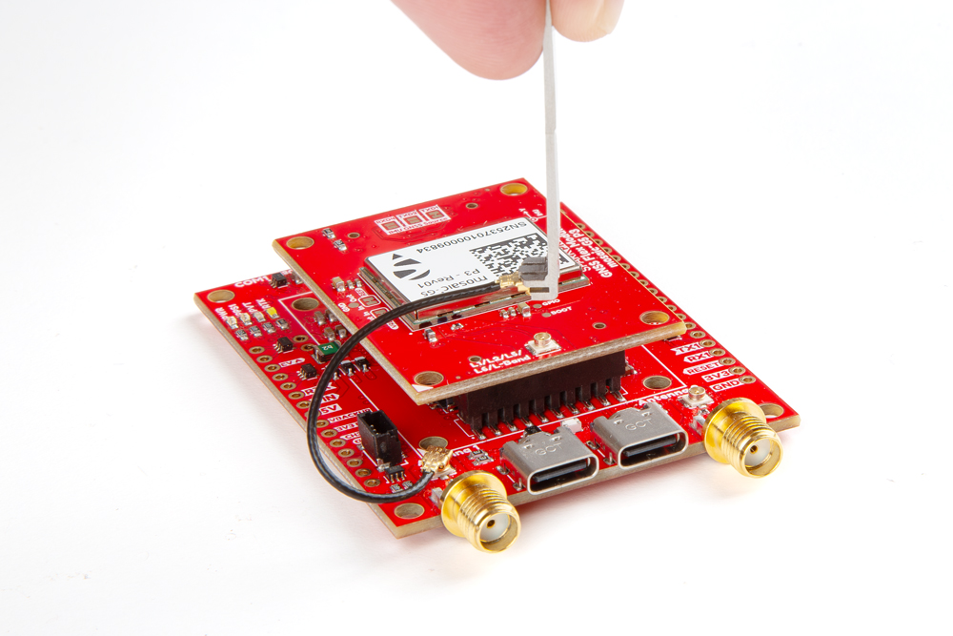
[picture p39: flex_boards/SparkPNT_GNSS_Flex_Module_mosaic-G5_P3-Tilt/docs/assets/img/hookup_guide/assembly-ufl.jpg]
Antenna connection

<figcaption markdown>Attaching an U.FL cable to the GNSS Flex board.</figcaption>
</figure>

!!! tip
	For the best performance, we recommend users choose a compatible L1/L2/L5/L6/L-Band GNSS antenna and utilize a low-loss cable. Also, don't forget that GNSS signals are fairly weak and can't penetrate buildings or dense vegetation. The GNSS antenna should have an unobstructed view of the sky.

## GNSS Flex Headers
SparkPNT GNSS Flex modules are *plug-in boards* featuring different GNSS receivers. They are designed to be easily swapped for repairs and pin-compatible for upgrades. The boards come populated with two 2x10 pin, 2mm pitch female headers for connecting to *carrier boards*.

<figure markdown>
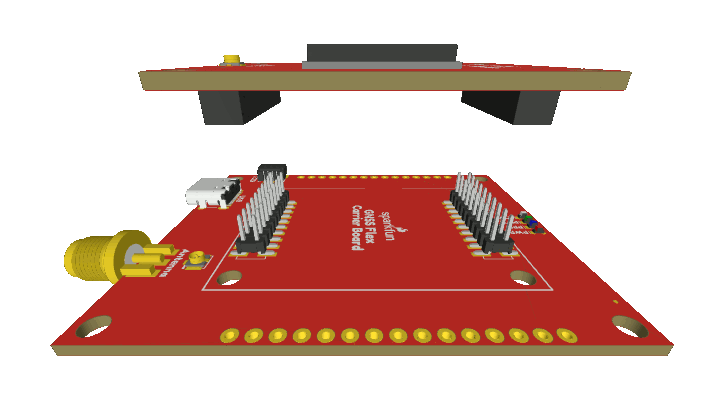
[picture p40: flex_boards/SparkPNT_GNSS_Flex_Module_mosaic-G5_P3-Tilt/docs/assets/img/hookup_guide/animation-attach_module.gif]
Stacking ZED-X20P GNSS Flex module onto a carrier board

<figcaption markdown>Stacking a GNSS Flex module onto a *carrier* board.</figcaption>
</figure>

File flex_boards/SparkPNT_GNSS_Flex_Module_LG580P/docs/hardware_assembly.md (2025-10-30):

## GNSS Antenna
In order to receive [GNSS](https://en.wikipedia.org/wiki/Satellite_navigation "Global Navigation Satellite System") signals, users will need to connect compatible antennas. For the best performance, we recommend users choose active, L1/L2/L5/L6/L-Band GNSS antennas and utilize a low-loss cables.

???+ warning "Antenna Specifications"
	- Passive antennas are not recommended for the LG580P GNSS receiver.
	- To mitigate the impact of out-of-band signals, utilize an active antenna whose SAW filter is placed in front of the LNA in the internal framework.
		- **DO NOT** select and antenna with the LNA placed in the front.
	- There is no need to inject an external DC voltage for the GNSS antenna. Power is already provided from the LG580P module for the LNA of an active antenna.

!!! tip
	For the best performance, we recommend users choose compatible L1/L2/L5/L6/L-Band GNSS antennas and utilize a low-loss cables. Also, don't forget that GNSS signals are fairly weak and can't penetrate buildings or dense vegetation. The GNSS antennas should have an unobstructed view of the sky.

### U.FL Connectors
GNSS antennas are connected to the U.FL connectors on the GNSS Flex board. For sturdier connections, users have the option to bridging the connection to the SMA connector on a Flex carrier board.

<div class="grid" markdown>

<div markdown>

### Primary Antenna
The `Antenna-1` U.FL connector functions as the primary GNSS antenna connection for the LG580P GNSS receiver. The GNSS antenna on this connection will also function as the reference position for any heading computations.

<figure markdown>
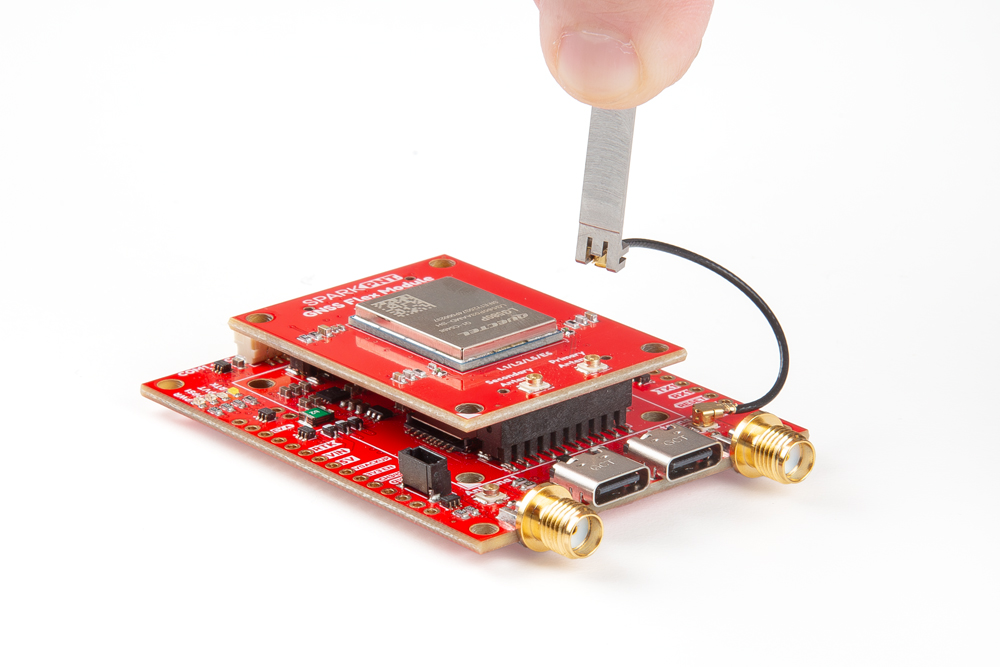
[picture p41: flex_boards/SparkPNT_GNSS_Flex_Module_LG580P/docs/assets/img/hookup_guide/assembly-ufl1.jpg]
Antenna connection

<figcaption markdown>Attaching an U.FL cable to the GNSS Flex board.</figcaption>
</figure>

</div>

<div markdown>

### Secondary Antenna
The `Antenna-2` U.FL connector is only utilized for attitude determination by the LG580P GNSS receiver. With a minimum distance of 1m between the antennas and the base length setting configured, users should be able to achieve a heading accuracy of 0.1&deg;.

<figure markdown>
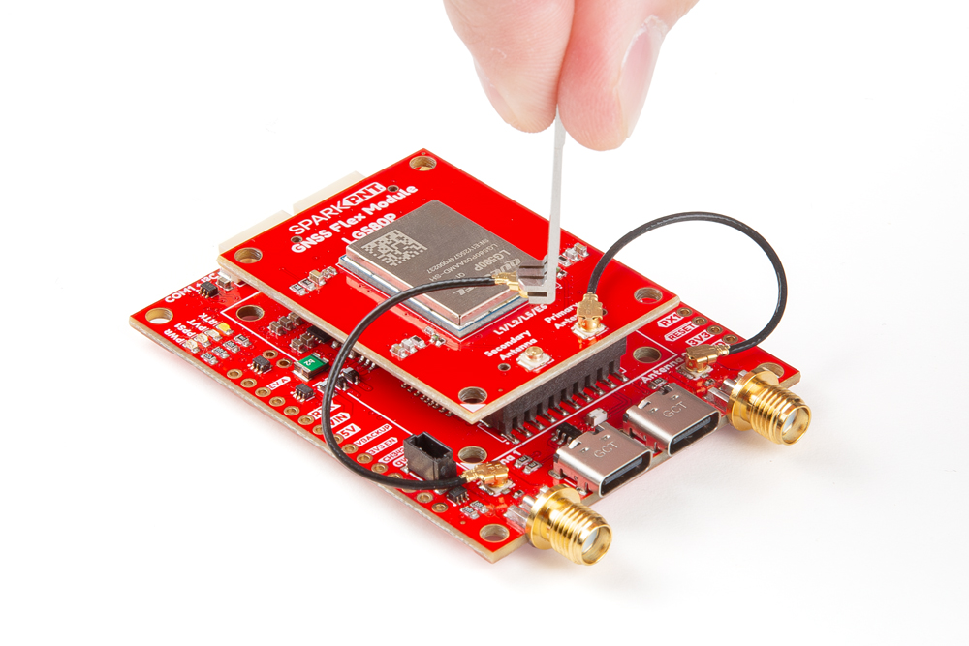
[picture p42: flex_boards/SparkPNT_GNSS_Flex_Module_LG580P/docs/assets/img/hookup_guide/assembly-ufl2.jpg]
Second antenna connection

<figcaption markdown>Attaching a second U.FL cable to the GNSS Flex board.</figcaption>
</figure>

</div>

</div>

## GNSS Flex Headers
SparkPNT GNSS Flex modules are *plug-in boards* featuring different GNSS receivers. They are designed to be easily swapped for repairs and pin-compatible for upgrades. The boards come populated with two 2x10 pin, 2mm pitch female headers for connecting to *carrier boards*.

<figure markdown>
Stacking LG580P GNSS Flex module onto a carrier board
<figcaption markdown>Stacking a GNSS Flex module onto a *carrier* board.</figcaption>
</figure>

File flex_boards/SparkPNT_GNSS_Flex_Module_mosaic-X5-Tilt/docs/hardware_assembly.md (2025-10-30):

!!! danger
	!!! warning "ESD Sensitivity"
		The mosaic-X5 GNSS receiver is sensitive to [ESD](https://en.wikipedia.org/wiki/Electrostatic_discharge "Electrostatic Discharge"). Use a proper grounding system to make sure that the working surface and the components are at the same electric potential.

		??? info "ESD Precaution"
			As recommended by the manufacturer, we highly recommend that users take the necessary precautions to avoid damaging their module. For example, users can utilize the [iFixit Anti-Static Wrist Strap](https://www.sparkfun.com/ifixit-anti-static-wrist-strap.html).

			<article class="video-500px" style="text-align: center; margin: auto;" markdown>
			QR code to product video
			<iframe src="https://www.youtube.com/embed/hrL5J6Q5gX8?si=jOPBat8rzMnL7Uz4&amp;start=26;&amp;end=35;" title="Septentrio: Getting Started Video (playback starts at ESD warning)" frameborder="0" allow="accelerometer; autoplay; clipboard-write; encrypted-media; gyroscope; picture-in-picture" allowfullscreen></iframe>
			</article>

	!!! warning "Active Antenna"
		Never inject an external DC voltage into the SMA connector for the GNSS antenna, as it may damage the mosaic-X5 GNSS receiver. For instance, when using a splitter to distribute the antenna signal to several GNSS receivers, make sure that no more than one output of the splitter passes DC. Use [DC-blocks](https://en.wikipedia.org/wiki/DC_block) otherwise.

		??? info
			A 3 - 5.5V DC voltage can be applied to the main antenna from the `VANT` pin, obviating the need for an external antenna supply or [bias-tee](https://en.wikipedia.org/wiki/Bias_tee).

## GNSS Antenna
In order to receive [GNSS](https://en.wikipedia.org/wiki/Satellite_navigation "Global Navigation Satellite System") signals, users will need to connect a compatible antenna. For the best performance, we recommend users choose an active, L1/L2/L5/L6 GNSS antenna and utilize a low-loss cable.

### U.FL Connector
GNSS antennas are connected to the U.FL connector on the GNSS Flex board. For sturdier connections, users have the option to bridging the connection to the SMA connector on a Flex carrier board.

<figure markdown>
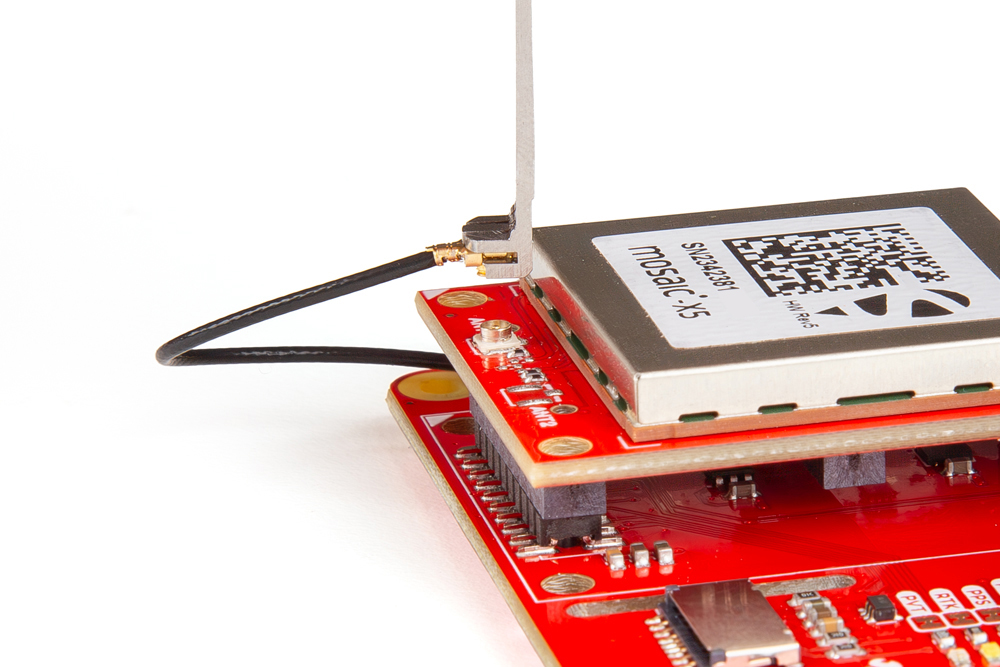
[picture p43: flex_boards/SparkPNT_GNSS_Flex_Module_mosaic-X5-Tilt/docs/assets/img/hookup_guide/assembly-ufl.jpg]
Antenna connection

<figcaption markdown>Attaching an U.FL cable to the GNSS Flex board.</figcaption>
</figure>

!!! tip
	For the best performance, we recommend users choose a compatible L1/L2/L5/L6 GNSS antenna and utilize a low-loss cable. Also, don't forget that GNSS signals are fairly weak and can't penetrate buildings or dense vegetation. The GNSS antenna should have an unobstructed view of the sky.

## GNSS Flex Headers
SparkPNT GNSS Flex modules are *plug-in boards* featuring different GNSS receivers. They are designed to be easily swapped for repairs and pin-compatible for upgrades. The boards come populated with two 2x10 pin, 2mm pitch female headers for connecting to *carrier boards*.

<figure markdown>
Stacking mosaic-X5 & IM19 GNSS Flex module onto a carrier board
<figcaption markdown>Stacking a GNSS Flex module onto a *carrier* board.</figcaption>
</figure>

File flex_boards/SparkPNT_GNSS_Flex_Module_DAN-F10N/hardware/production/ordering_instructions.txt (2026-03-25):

Ordering Instructions:
Panel dimensions: 151.20 x 146.70 mm.
Controlled Impedance: JLC04161H-7628
Material: TG135
Solder Mask: Red
Silkscreen Color: White
Layers: 4
Finish: HASL Lead-Free
Thickness: 1.6mm
Inner Copper Weight: 0.5oz
Outer Copper Weight: 1oz
Minimum track width: 0.15mm (6.00mil)
Minimum via drill: 0.30mm (11.81mil)
No Clean Process

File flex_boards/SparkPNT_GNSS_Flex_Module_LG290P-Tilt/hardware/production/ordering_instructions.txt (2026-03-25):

Ordering Instructions:
Panel dimensions: 185.70 x 146.70 mm.
Controlled Impedance: JLC7628
Material: TG135
Solder Mask: Red
Silkscreen Color: White
Layers: 4
Finish: ENIG
Thickness: 1.6mm
Inner Copper Weight: 0.5oz
Outer Copper Weight: 1oz
Minimum track width: 0.18mm (7.00mil)
Minimum via drill: 0.30mm (12.00mil)
No Clean Process

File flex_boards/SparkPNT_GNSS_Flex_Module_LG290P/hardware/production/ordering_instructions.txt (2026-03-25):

Ordering Instructions:
Panel dimensions: 146.70 x 185.70 mm.
Controlled Impedance: JLC7628
Material: TG155
Solder Mask: Red
Silkscreen Color: White
Layers: 4
Finish: ENIG
Thickness: 1.6mm
Inner Copper Weight: 0.5oz
Outer Copper Weight: 1oz
Minimum track width: 0.18mm (7.00mil)
Minimum via drill: 0.30mm (12.00mil)
No Clean Process

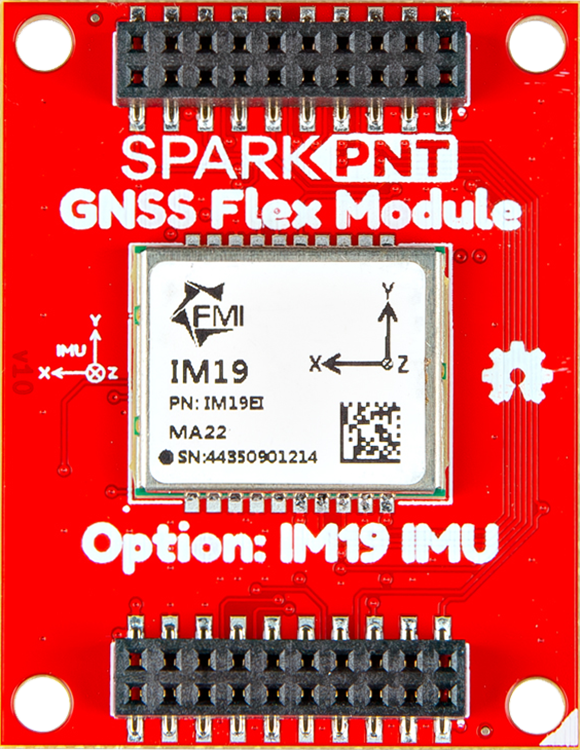
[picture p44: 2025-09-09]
flex_boards/SparkPNT_GNSS_Flex_Module_LG290P-Tilt/docs/assets/img/hookup_guide/bottom.png

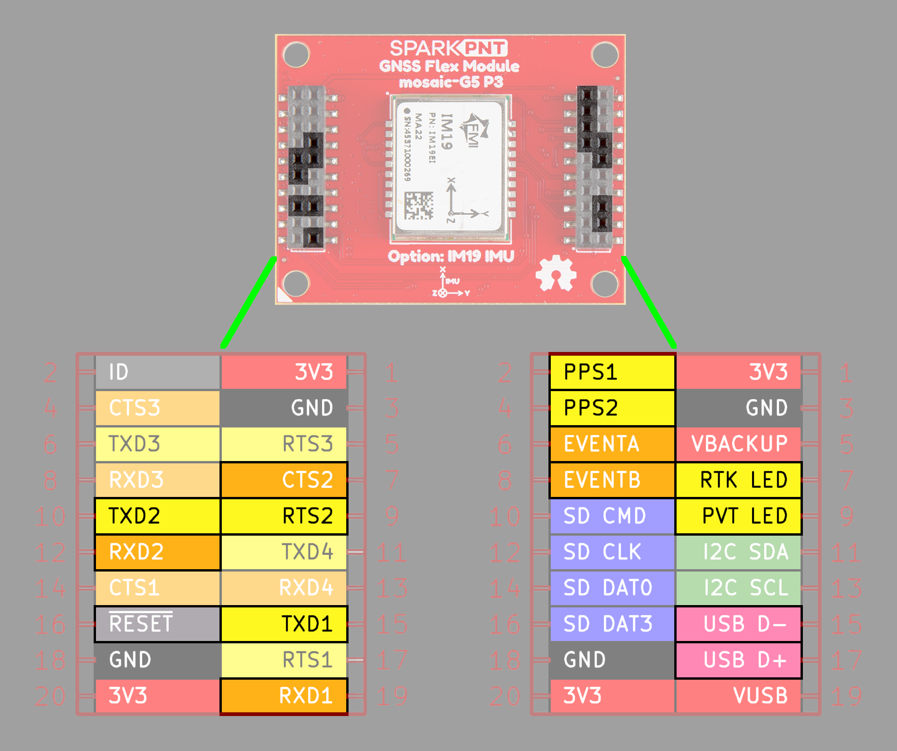
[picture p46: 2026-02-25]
flex_boards/SparkPNT_GNSS_Flex_Module_mosaic-G5_P3-Tilt/docs/assets/img/hookup_guide/headers-gnss.png

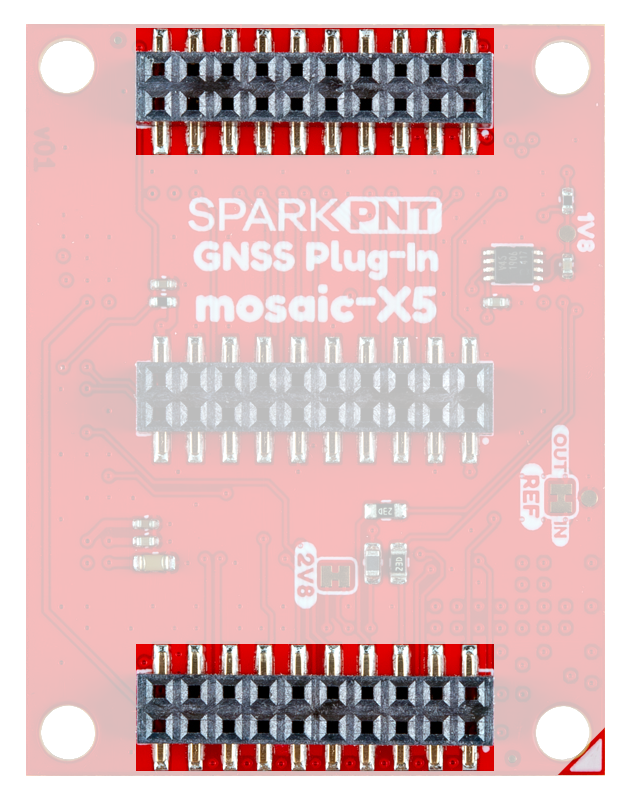
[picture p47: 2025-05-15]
flex_boards/SparkPNT_GNSS_Flex_Module_mosaic-X5/docs/assets/img/hookup_guide/headers-flex_system.png

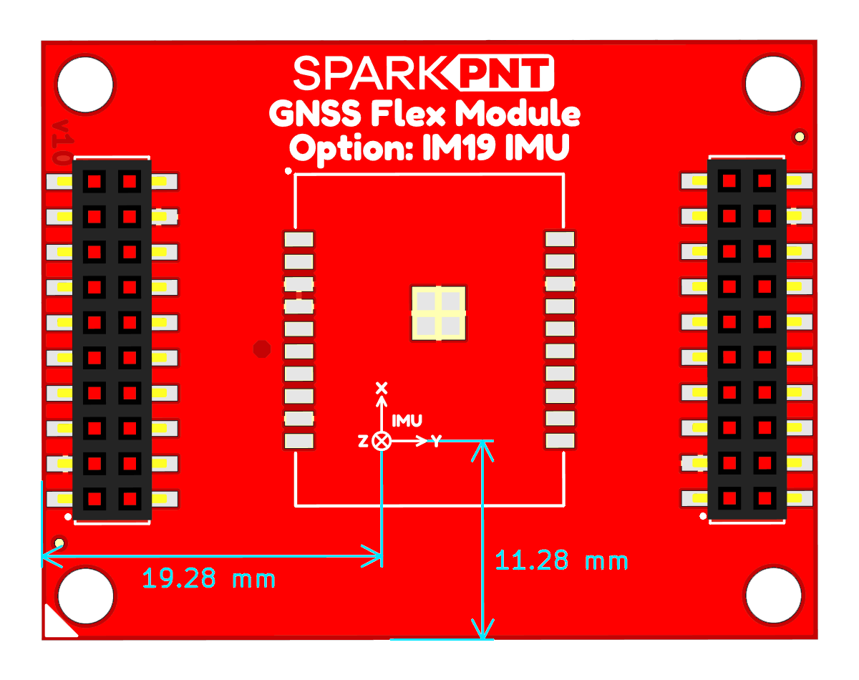
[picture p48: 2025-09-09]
docs/assets/img/hookup_guide/im19_offset-bottom.png

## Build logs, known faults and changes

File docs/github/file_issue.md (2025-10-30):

## Need Assistance?

<!-- Technical Assistance Box -->
!!! warning "Need Help?"
	If you need technical assistance or more information on a product that is not working as you expected, we recommend heading on over to the [SparkFun Technical Assistance](https://www.sparkfun.com/technical_assistance) page for some initial troubleshooting. This **Submit Issues** page is not where users should seek assistance.

	<article style="text-align: center;" markdown>
	[SparkFun Technical Assistance Page](https://www.sparkfun.com/technical_assistance){ .md-button .md-button--primary }
	</article>

	If you can't find what you need there, the [SparkFun Forums](https://community.sparkfun.com) is a great place to search the product forums and ask questions.

	!!! info "Account Registration Required"
		For your first visit to our forum, you'll need to create a [Forum Account](https://community.sparkfun.com/signup) to post questions.

## Did we make a mistake?
Spot something wrong? Please let us know. 

### Discrepancies in the Documentation
All of our documentation can be modified by you! Please help us make it better.

- The documentation files for these pages are contained in the [`docs` folder](https://github.com/sparkfun/SparkFun_GNSS_Flex_System/tree/main/docs) of the [SparkFun GNSS Flex System repository](https://github.com/sparkfun/SparkFun_GNSS_Flex_System).

#### 🔍 Spot something wrong?
If a section of the documentation is incorrect, please [open an issue](https://github.com/sparkfun/SparkFun_GNSS_Flex_System/issues) and let us know.

#### Do you have a suggested correction?

1. With a GitHub account, [fork this repository](https://github.com/sparkfun/SparkFun_GNSS_Flex_System/fork).
2. Add your correction(s) or improvement(s) to the markdown file(s)
3. File a pull request with your changes, and enjoy making the ~~words~~ ~~worlds~~ world a better place.
	- Once received, the documentation specialist will automatically be notified.
	- We will review your suggested improvement(s) to make sure they are correct and fit within our documentation standards.

### Problems in the Hardware Design
All of our designs are open-source! Please help us make it better.

- Our board design files are contained in the `/Hardware` directories of the [SparkFun GNSS Flex System repository](https://github.com/sparkfun/SparkFun_GNSS_Flex_System).

#### Does something not make sense? 🤔
If part of the design is confusing, please [open an issue](https://github.com/sparkfun/SparkFun_GNSS_Flex_System/issues) and let us know.

#### Did we forget to include an important function of the board? 🤦
If part of the board's functionality is missing, please [open an issue](https://github.com/sparkfun/SparkFun_GNSS_Flex_System/issues) and file a feature request.

!!! tip "Design Considerations"
	Please keep in mind that we may intentionally exclude certain functions of the board to meet our product design requirements.

	- *For example, our Qwiic Micro boards are intended to fit on a small board layout and only use I^2^C communication; therefore, we may not have the SPI and interrupt pins available for users.*

#### Do you wish to contribute directly to improving the board design?

1. With a GitHub account, [fork this repository](https://github.com/sparkfun/SparkFun_GNSS_Flex_System/fork).
2. Add your design augmentation(s)
3. File a pull request with your changes, and enjoy making the ~~words~~ ~~worlds~~ world a better place.
	1. Once received, the engineer in charge of the original design will automatically be notified.
	2. We will review your suggested improvement(s) to verify that they are within our board design standards and meet our product design requirements.
	3. If approved, we will flag these changes for our next board revision. Congrats! 🍻

		!!! info
			Even if your suggestion is accepted, these changes may not be immediately available for purchase. We may have to cycle through our current product inventory first.

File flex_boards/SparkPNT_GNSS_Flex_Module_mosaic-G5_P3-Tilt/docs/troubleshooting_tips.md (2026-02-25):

!!! warning "Need Help?"
	If you need technical assistance or more information on a product that is not working as you expected, we recommend heading on over to the [SparkFun Forums](https://community.sparkfun.com).

	!!! info "Account Registration Required"
		If this is your first visit to our forum, you'll need to create a [Forum Account](https://community.sparkfun.com/signup) to post questions.

## Electrostatic Discharge
The mosaic-G5 P3 GNSS receiver is sensitive to [ESD](https://en.wikipedia.org/wiki/Electrostatic_discharge "Electrostatic Discharge"). Use a proper grounding system to make sure that the working surface and the components are at the same electric potential.

!!! warning "ESD Precaution"
	As recommended by the manufacturer, we highly recommend that users take the necessary precautions to avoid damaging their GNSS receiver.

	<div class="grid cards" markdown>

	<div markdown>

	<article class="video-500px" style="margin: auto;" markdown>
	<iframe src="https://www.youtube.com/embed/hrL5J6Q5gX8?si=jOPBat8rzMnL7Uz4&amp;start=26;&amp;end=35;" title="Septentrio: Getting Started Video (playback starts at ESD warning)" frameborder="0" allow="accelerometer; autoplay; clipboard-write; encrypted-media; gyroscope; picture-in-picture" allowfullscreen></iframe>
	</article>

	</div>

	</div>

## GNSS Antenna

### Power Input
!!! danger "Active Antenna"
	Never inject an external DC voltage into the SMA connector for the GNSS antenna, as it may damage the mosaic-G5 P3 GNSS receiver. For instance, when using a splitter to distribute the antenna signal to several GNSS receivers, make sure that no more than one output of the splitter passes DC. Use [DC-blocks](https://en.wikipedia.org/wiki/DC_block) otherwise.

### Supported Frequency Bands
For the best performance, we recommend users choose a compatible L1/L2/L5/L6 GNSS antenna and utilize a low-loss cable. Utilizing an antenna that doesn't match all the supported frequency bands of the mosaic-G5 P3, will result in reduced performance and capabilities.

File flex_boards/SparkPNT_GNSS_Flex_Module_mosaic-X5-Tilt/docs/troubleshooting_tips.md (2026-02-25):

!!! warning "Need Help?"
	If you need technical assistance or more information on a product that is not working as you expected, we recommend heading on over to the [SparkFun Forums](https://community.sparkfun.com).

	!!! info "Account Registration Required"
		If this is your first visit to our forum, you'll need to create a [Forum Account](https://community.sparkfun.com/signup) to post questions.

### Electrostatic Discharge
The mosaic-X5 GNSS receiver is sensitive to [ESD](https://en.wikipedia.org/wiki/Electrostatic_discharge "Electrostatic Discharge"). Use a proper grounding system to make sure that the working surface and the components are at the same electric potential.

!!! warning "ESD Precaution"
	As recommended by the manufacturer, we highly recommend that users take the necessary precautions to avoid damaging their module.

	<article style="text-align: center;" markdown>
	QR code to product video
	</article>

	<article class="video-500px" style="margin: auto;" markdown>
	<iframe src="https://www.youtube.com/embed/hrL5J6Q5gX8?si=jOPBat8rzMnL7Uz4&amp;start=26;&amp;end=35;" title="Septentrio: Getting Started Video (playback starts at ESD warning)" frameborder="0" allow="accelerometer; autoplay; clipboard-write; encrypted-media; gyroscope; picture-in-picture" allowfullscreen></iframe>
	</article>

### USB Driver
A USB driver is only required for Windows PCs *(see the [USB Driver](software_overview.md#usb-driver) section)*.

### GNSS antenna

#### Power Input
!!! danger "Active Antenna"
	Never inject an external DC voltage into the SMA connector for the GNSS antenna, as it may damage the mosaic-X5 GNSS receiver. For instance, when using a splitter to distribute the antenna signal to several GNSS receivers, make sure that no more than one output of the splitter passes DC. Use [DC-blocks](https://en.wikipedia.org/wiki/DC_block) otherwise.

#### Supported Frequency Bands
For the best performance, we recommend users choose a compatible L1/L2/L5/L6 GNSS antenna and utilize a low-loss cable. Utilizing an antenna that doesn't match all the supported frequency bands of the mosaic-X5, will result in reduced performance and capabilities.

### Data Logging
For data logging issues, here are some simple troubleshooting tips:

- Make sure that your SD card is formatted to a `FAT32` file system.
	- The `FAT32` file system also limits the maximum capacity of the card to less than **32GB** *(i.e. a 256GB SD card will not work)*.
- Make sure that the mosaic-X5 GNSS receiver has a configured data stream output.
- Use the mosaic-X5 web page to verify that the SD card is mounted as a storage drive.

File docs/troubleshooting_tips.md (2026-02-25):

!!! warning "Need Help?"
	If you need technical assistance or more information on a product that is not working as you expected, we recommend heading on over to the [SparkFun Forums](https://community.sparkfun.com).

	!!! info "Account Registration Required"
		If this is your first visit to our forum, you'll need to create a [Forum Account](https://community.sparkfun.com/signup) to post questions.

<!-- QR Code for Hookup Guide (Displayed when printed) -->
<article style="text-align: center;" markdown>
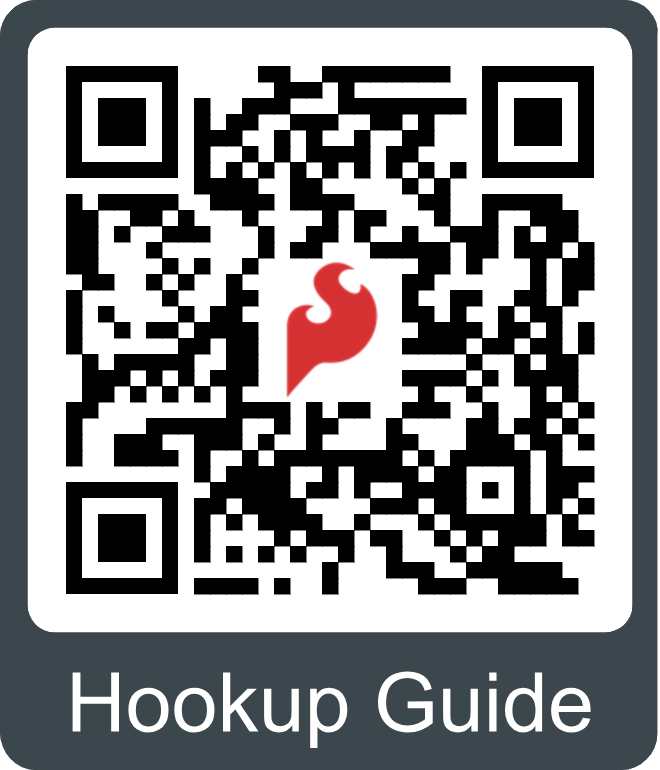
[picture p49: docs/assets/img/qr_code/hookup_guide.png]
QR code to the hookup guide

</article>

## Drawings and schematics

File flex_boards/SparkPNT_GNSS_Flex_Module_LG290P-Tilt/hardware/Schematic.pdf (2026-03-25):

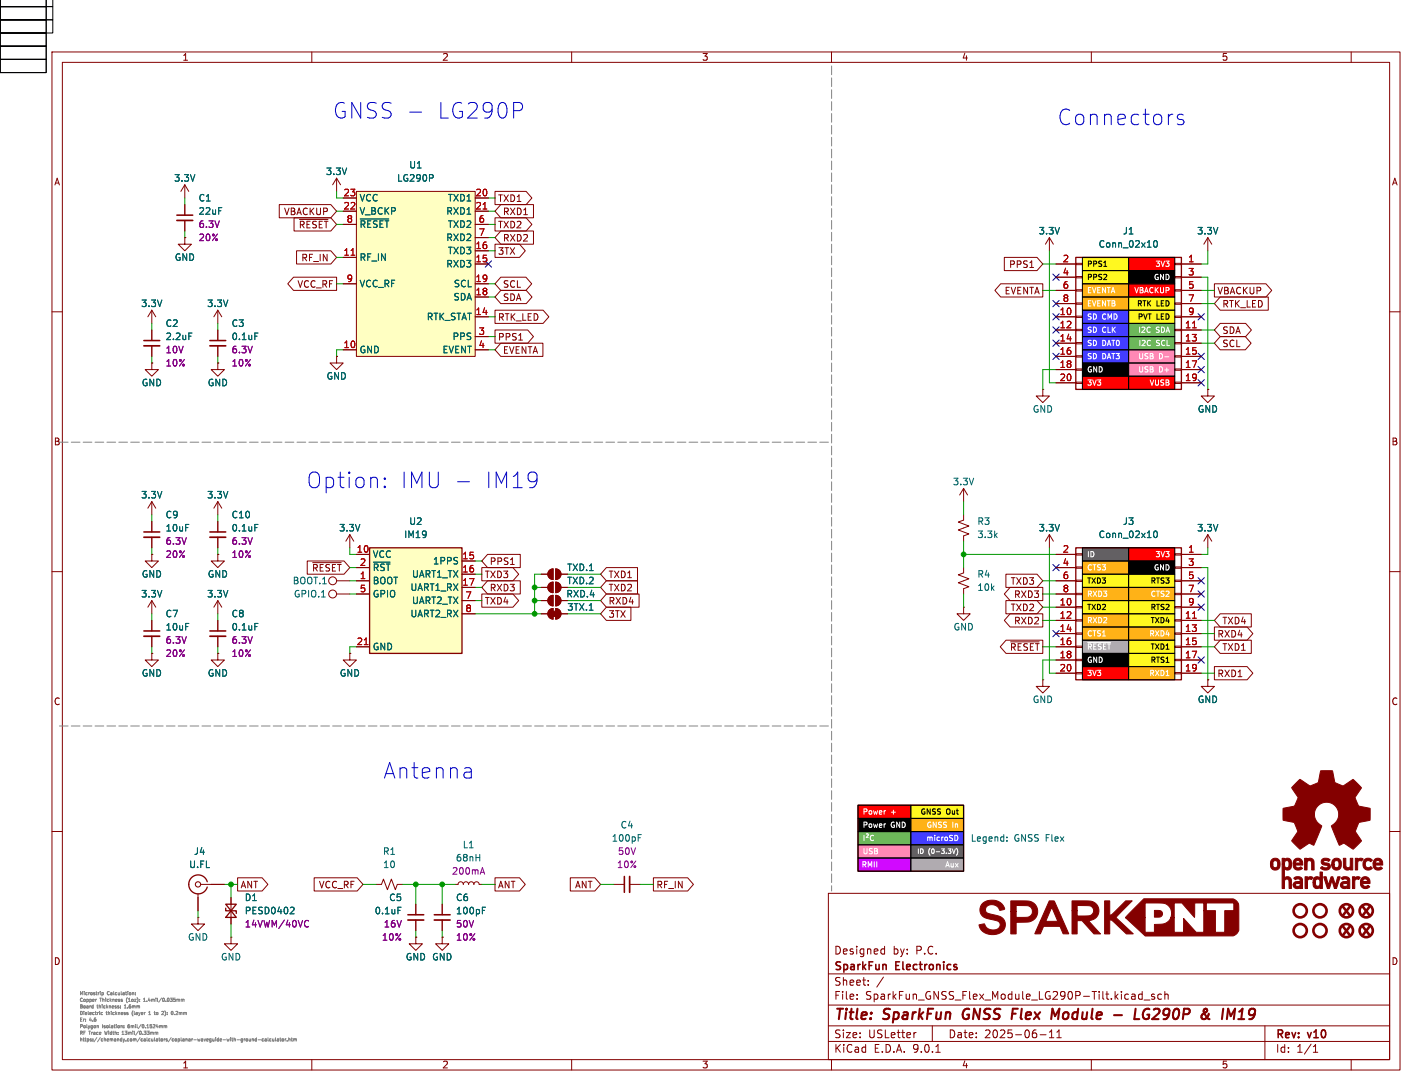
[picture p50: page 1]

EVENTB | I2C SCL USB D- USB D+ VUSB 2
PPS1 PPS2 EVENTA

3V3 GND

VBACKUP RTK LED

SD CMD | PVT LED
SD CLK | I2C SDA
SD DAT0 SD DAT3 GND

Id: 1/1 Title: SparkFun GNSS Flex Module - LG290P & IM19

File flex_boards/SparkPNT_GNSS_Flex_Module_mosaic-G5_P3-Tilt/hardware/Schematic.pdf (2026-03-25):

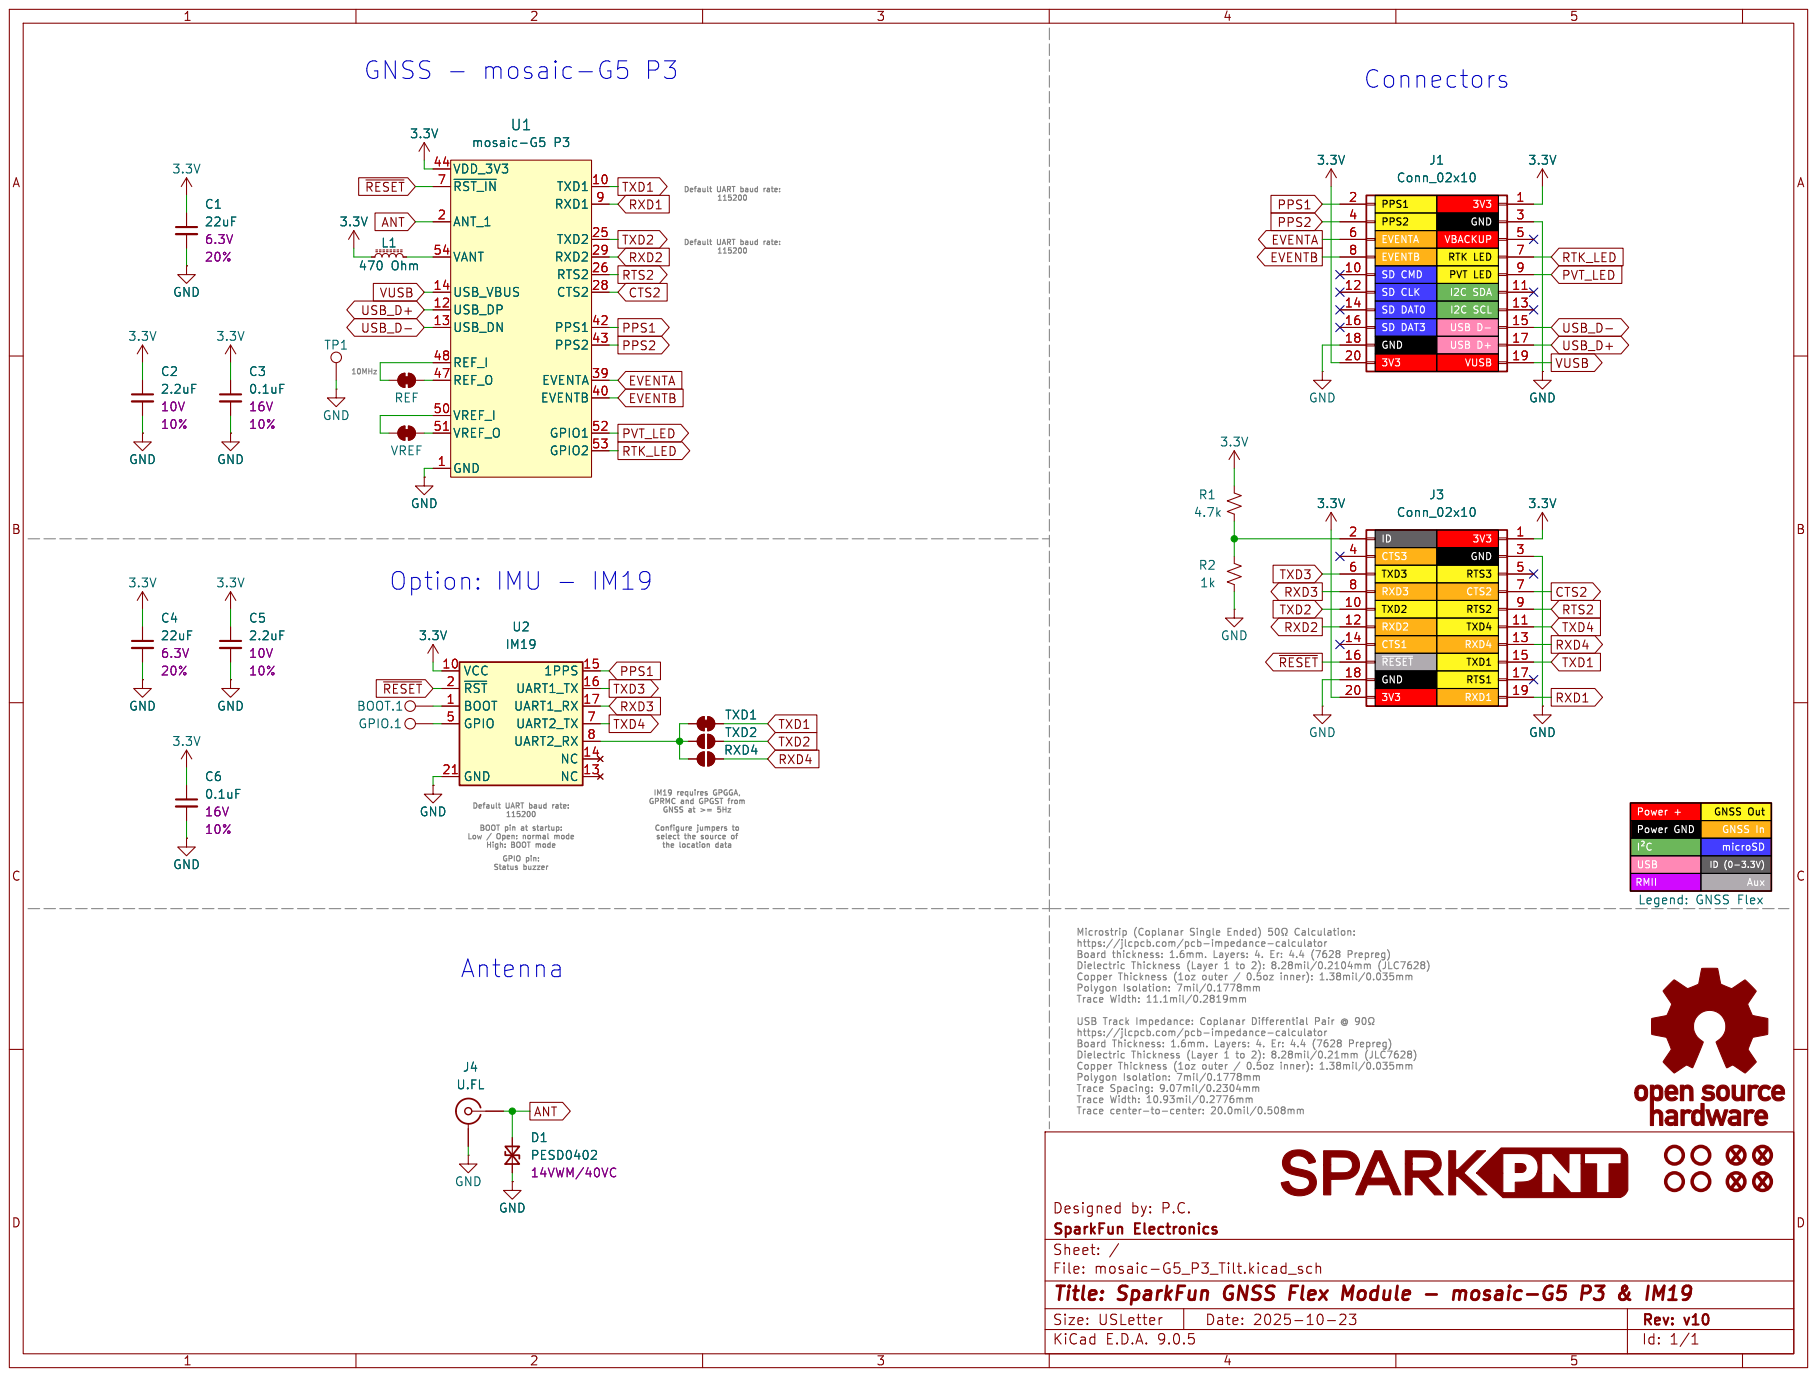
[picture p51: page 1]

EVENTB | I2C SCL USB D- USB D+ VUSB 2468
PPS1 PPS2 EVENTA

3V3 GND

VBACKUP RTK LED

SD CMD | PVT LED
SD CLK | I2C SDA
SD DAT0 SD DAT3 GND

ID (0-3.3V) Aux Legend: GNSS Flex GND

Power + Power GND

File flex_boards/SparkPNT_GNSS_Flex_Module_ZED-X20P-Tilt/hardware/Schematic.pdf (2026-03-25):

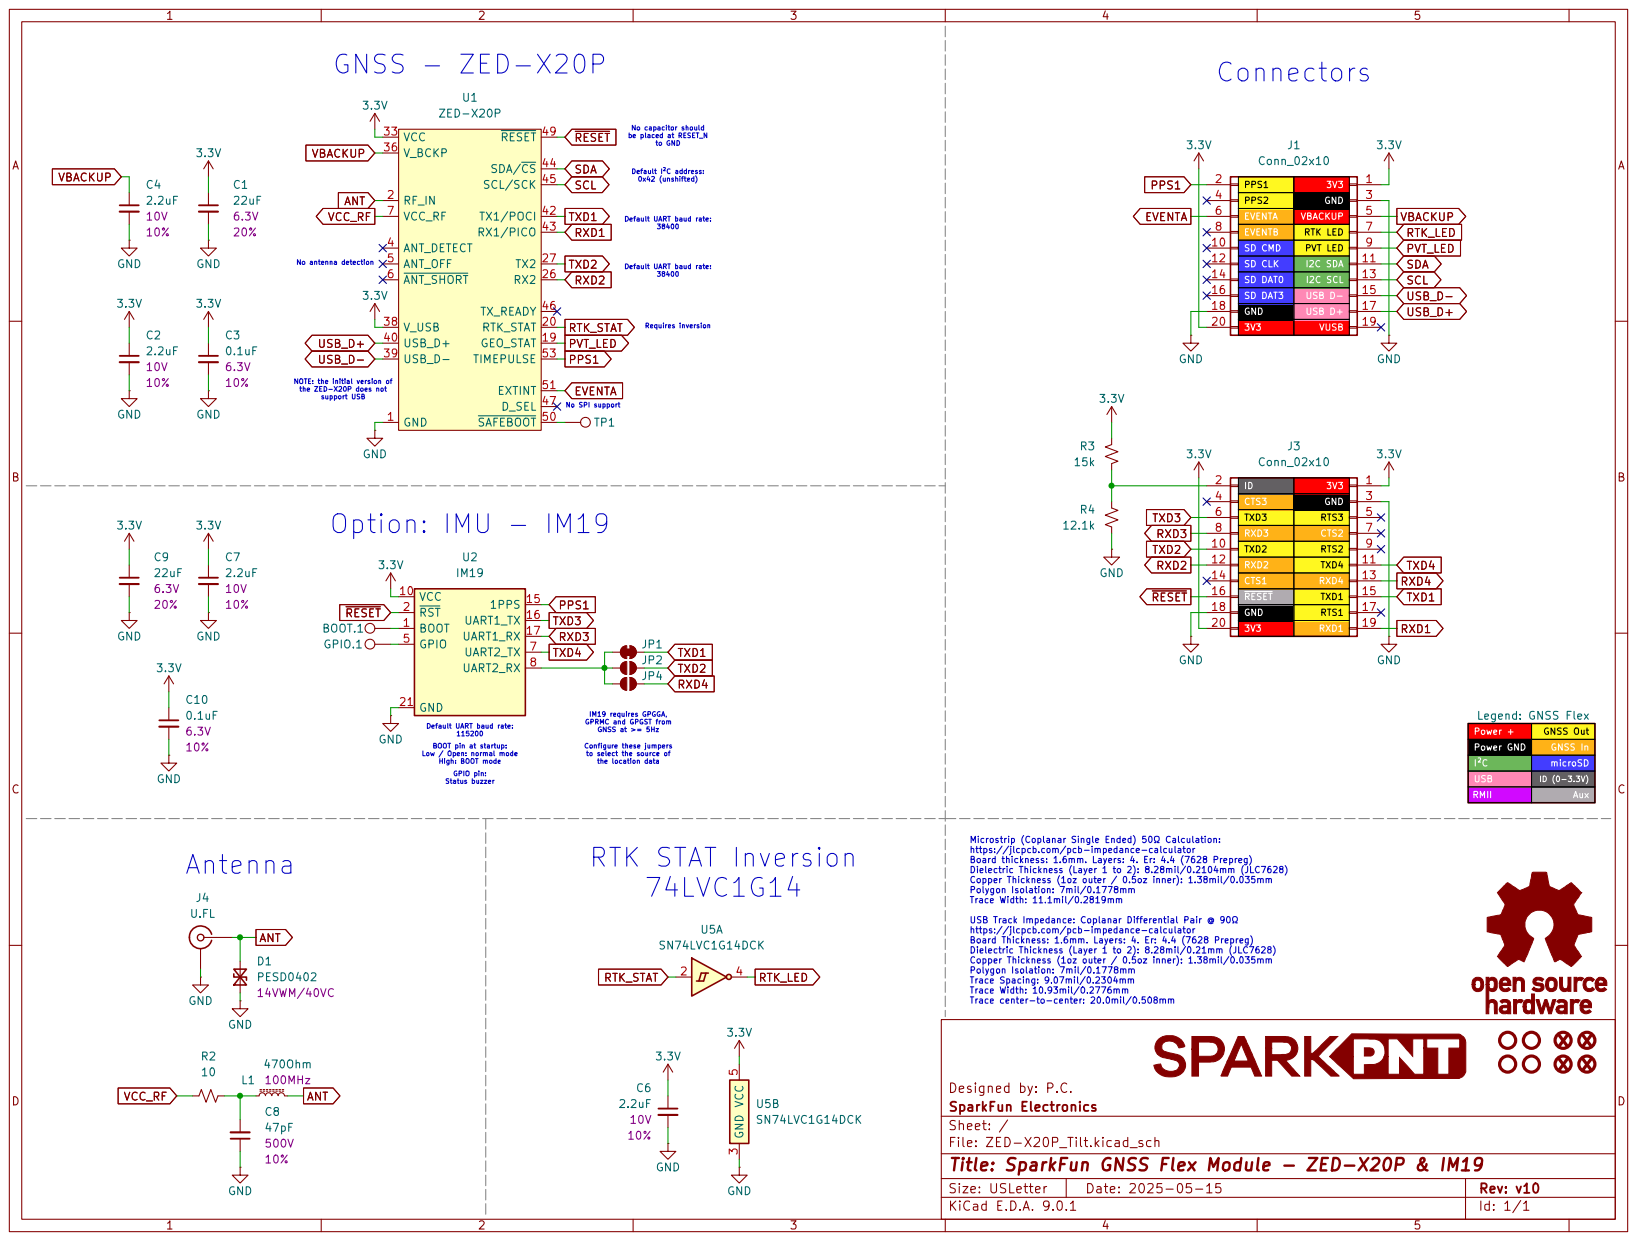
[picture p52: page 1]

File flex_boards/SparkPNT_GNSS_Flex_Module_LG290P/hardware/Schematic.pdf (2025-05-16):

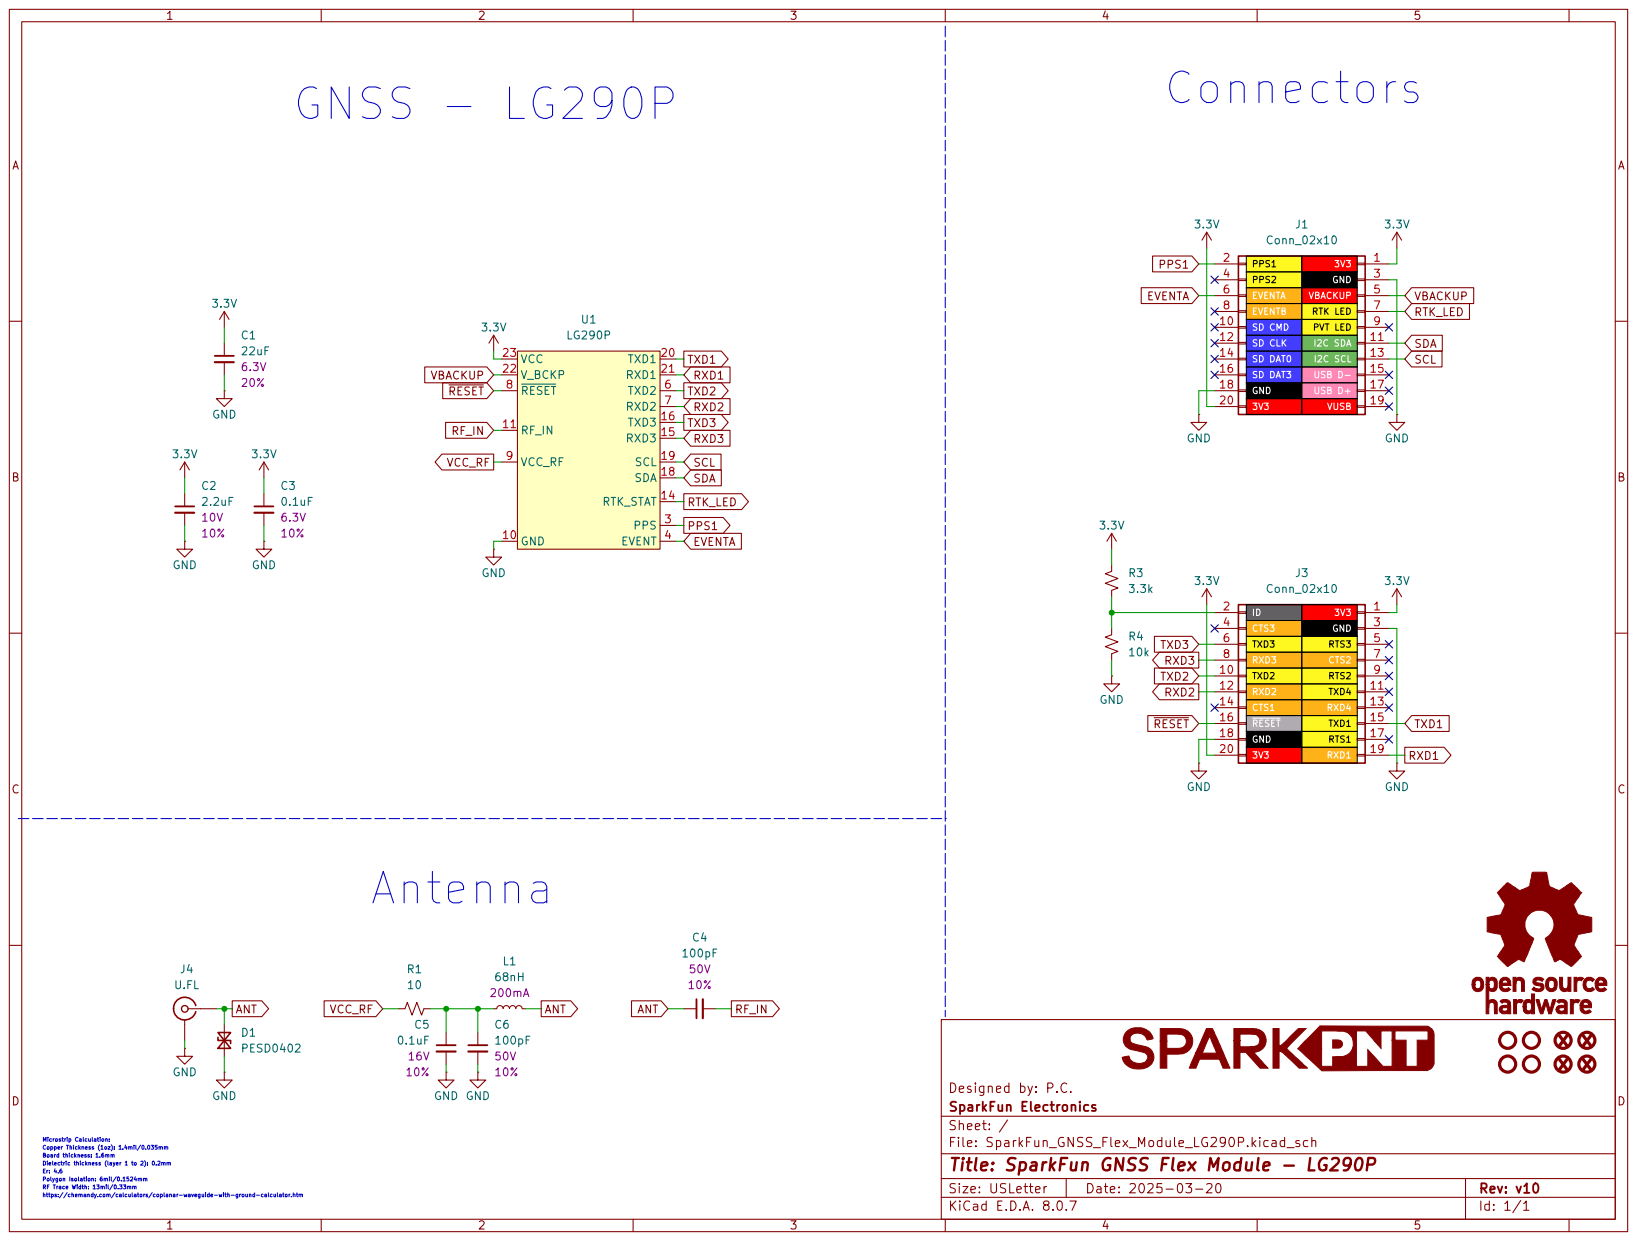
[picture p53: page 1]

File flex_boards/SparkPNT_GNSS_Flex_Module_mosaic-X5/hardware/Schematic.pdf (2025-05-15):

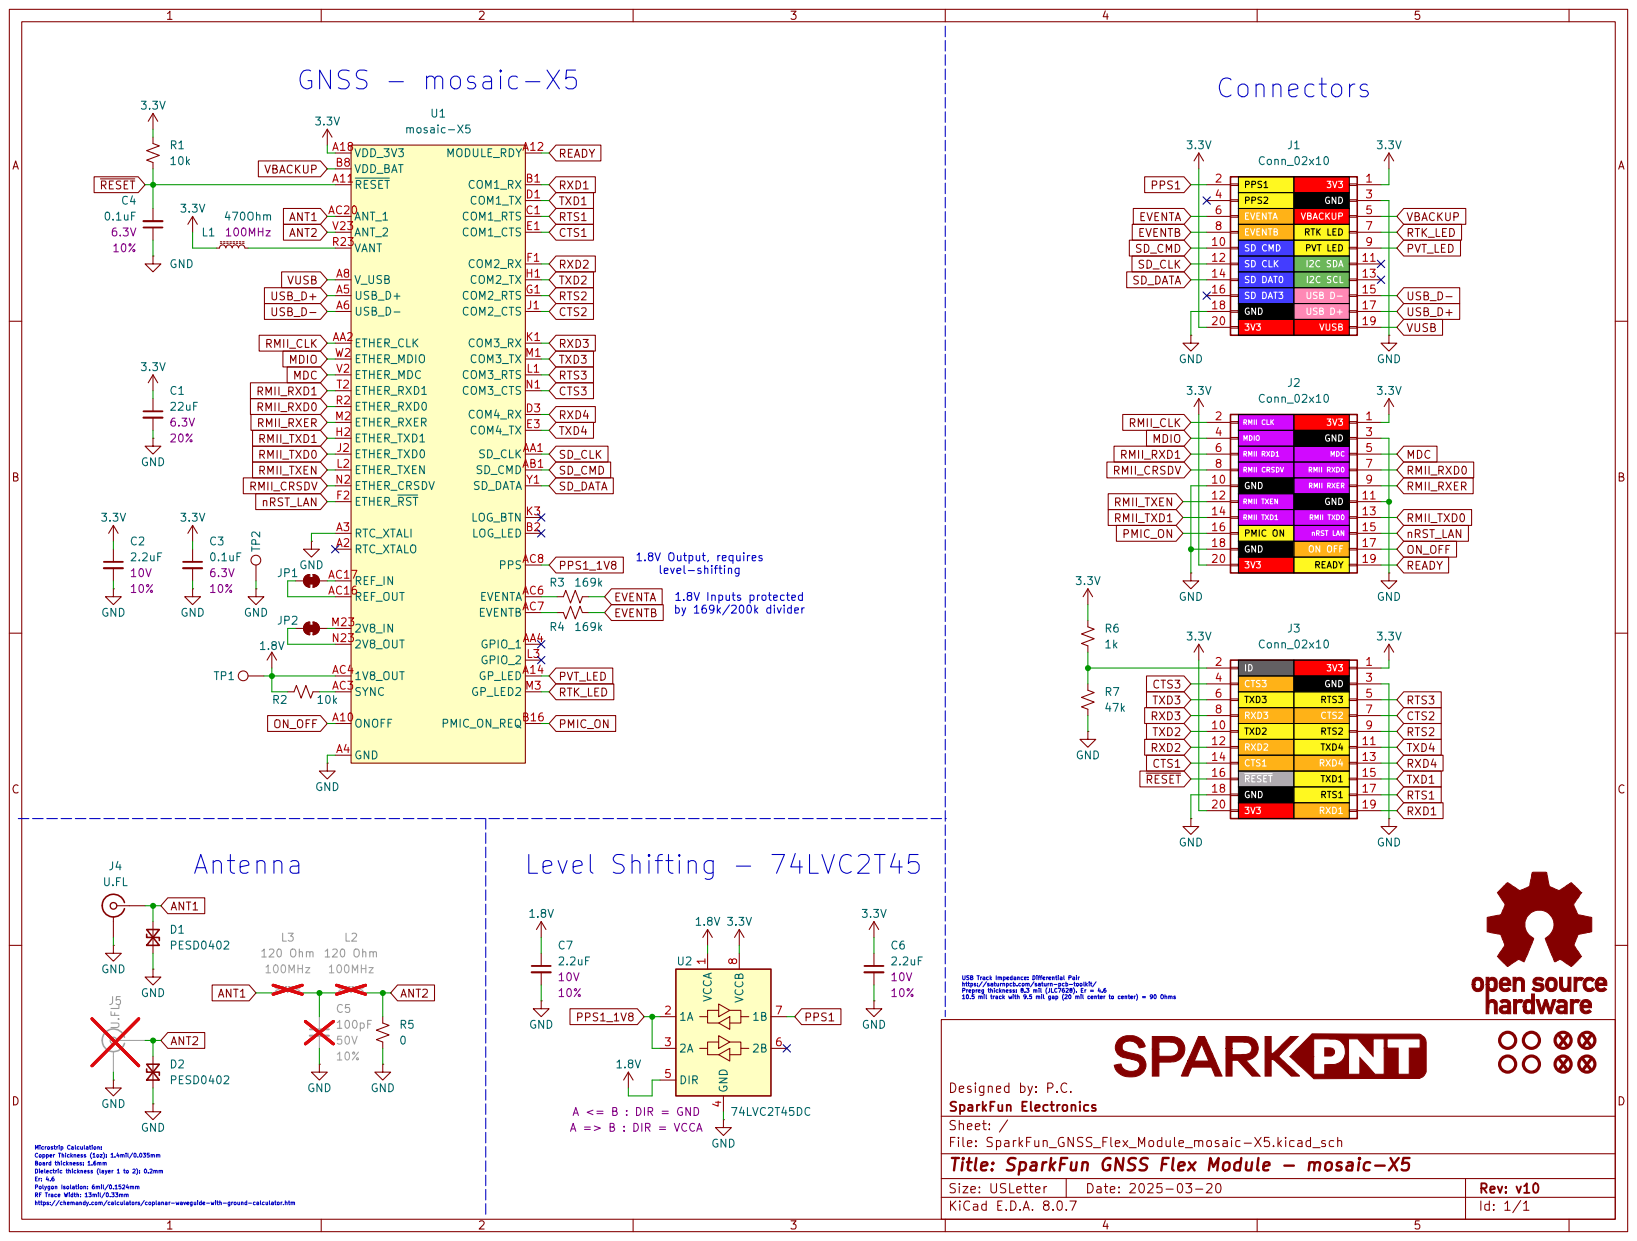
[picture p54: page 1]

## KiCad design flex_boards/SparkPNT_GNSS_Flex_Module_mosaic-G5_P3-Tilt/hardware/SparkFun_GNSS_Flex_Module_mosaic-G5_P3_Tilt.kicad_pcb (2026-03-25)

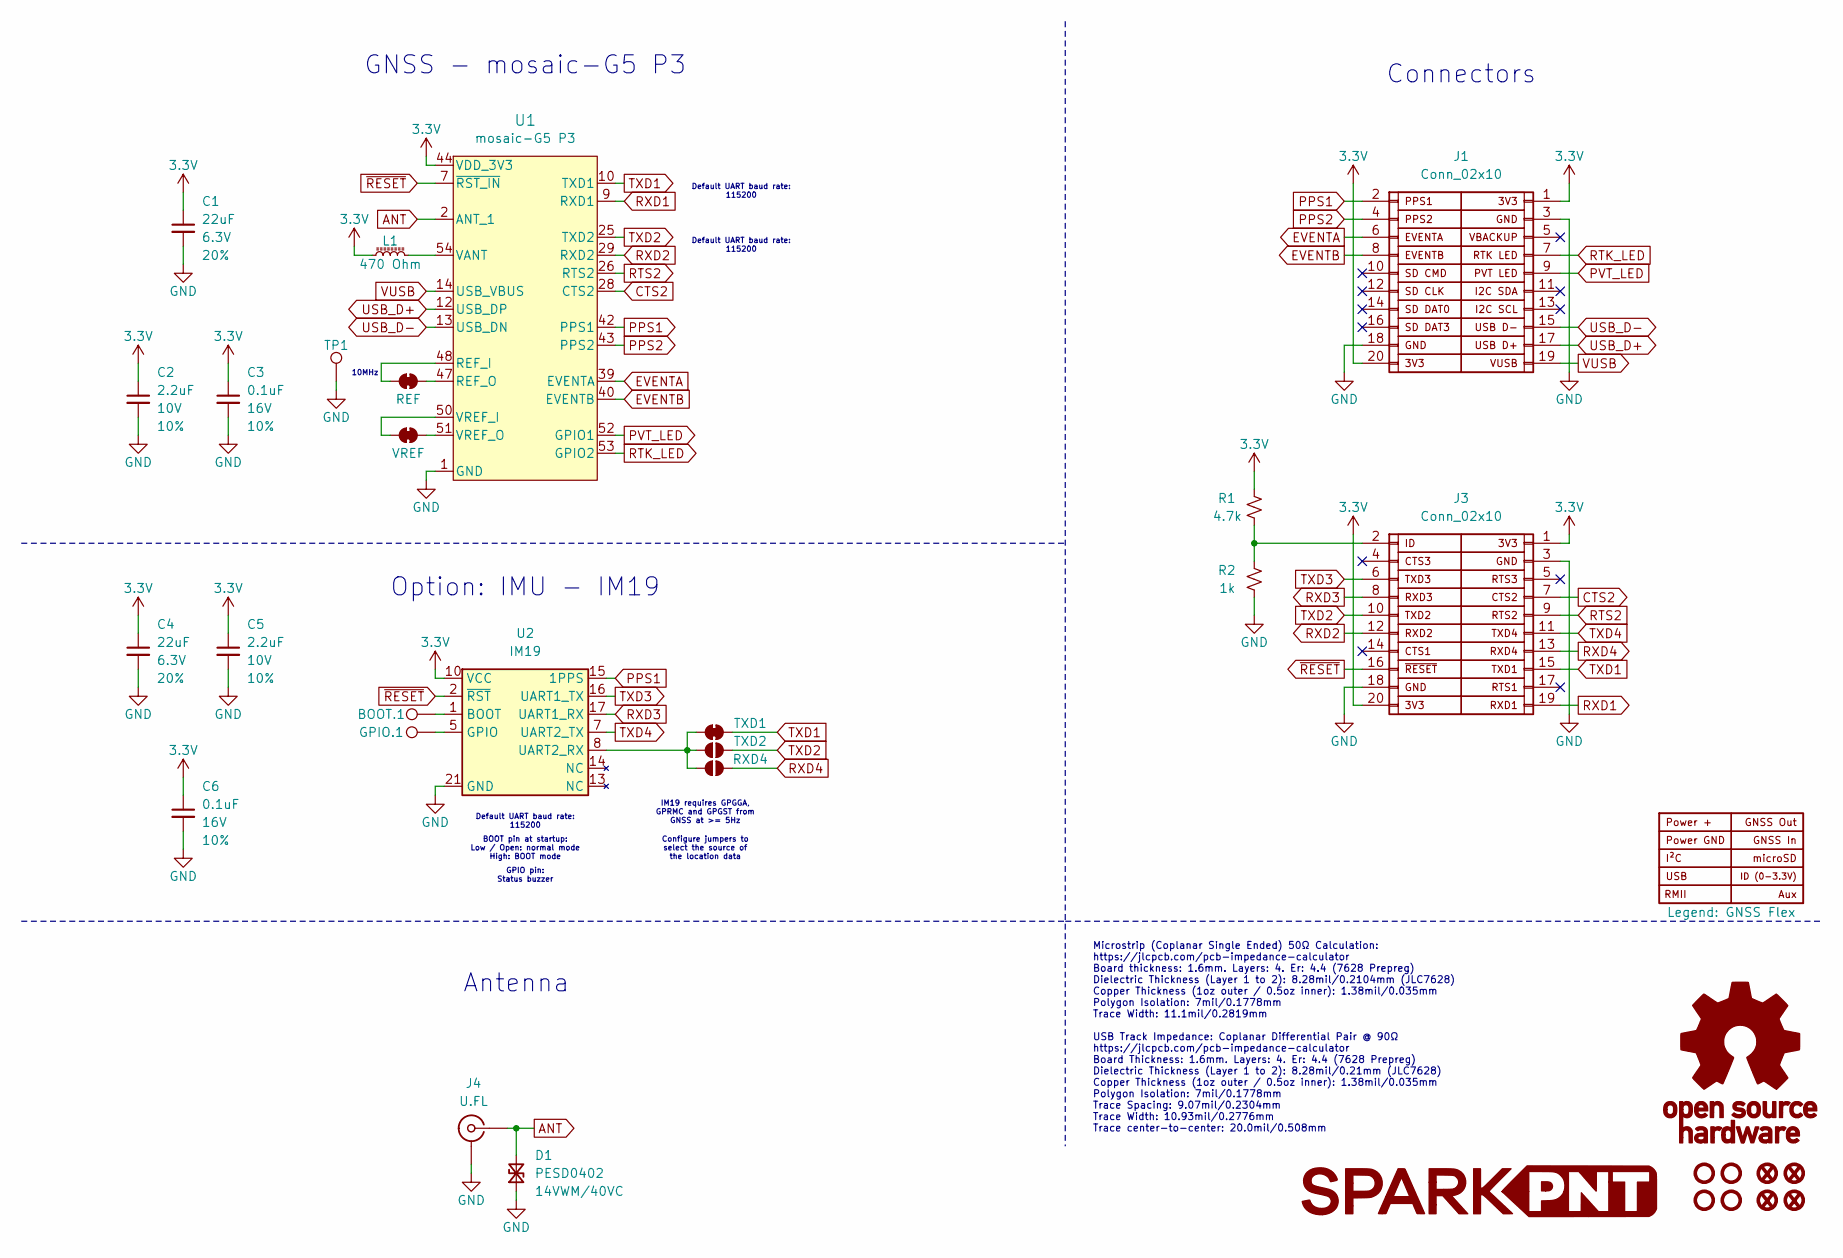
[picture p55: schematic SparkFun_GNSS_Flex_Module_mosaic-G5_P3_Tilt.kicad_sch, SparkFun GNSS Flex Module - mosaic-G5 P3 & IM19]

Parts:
BOOT.1: 1.0mm; TestPoint-1.0mm
C1, C4: 22uF; C_0603_1608Metric; Voltage 6.3V; Tolerance 20%
C2, C5: 2.2uF; C_0402_1005Metric; Voltage 10V; Tolerance 10%
C3, C6: 0.1uF; C_0402_1005Metric; Voltage 16V; Tolerance 10%
D1: PESD0402; C_0402_1005Metric; Rating 14VWM/40VC
FID1, FID2, FID3, FID4: Fiducial_0.5mm; Fiducial_0.5mm_Mask1mm
G1: LOGO
G3: OSHW_Logo; Creative_Commons_License
GPIO.1: 1.0mm; TestPoint-1.0mm
J1, J3: Conn_02x10; 2x10_P2.0mm_Socket_Vertical_SMD_Pegs
J2: Legend: GNSS Flex; GNSS_Flex_Template
J4: U.FL
L1: 470 Ohm; C_0603_1608Metric
R1: 4.7k; R_0603_1608Metric
R2: 1k; R_0603_1608Metric
REF.1: REF; Jumper_2_NC_Trace
RXD.4: RXD4; Jumper_2_NO
ST1, ST2, ST3, ST4: Standoff
TP1: 1.25mm; TestPoint-1.25mm
TXD.1: TXD1; Jumper_2_NC_Trace
TXD.2: TXD2; Jumper_2_NO
U1: mosaic-G5 P3; Septentrio_mosaic-G5_LGA54
U2: IM19
VREF.1: VREF; Jumper_2_NC_Trace

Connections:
3.3V: C1.1, C2.1, C3.1, C4.1, C5.1, C6.1, J1.1, J1.20, J3.1, J3.20, L1.1, R1.2, U1.44 (VDD_3V3), U1.45 (VDD_3V3), U2.6 (VCC), U2.10 (VCC)
ANT: D1.2 (A2), J4.1 (In), U1.2 (ANT_1)
CTS2: J3.7, U1.28 (CTS2)
EVENTA: J1.6, U1.39 (EVENTA)
EVENTB: J1.8, U1.40 (EVENTB)
GND: C1.2, C2.2, C3.2, C4.2, C5.2, C6.2, D1.1 (A1), J1.3, J1.18, J3.3, J3.18, J4.2 (Ext), R2.1, TP1.1, U1.1 (GND), U1.3 (GND), U1.4 (GND), U1.6 (GND), U1.11 (GND), U1.17 (GND), U1.21 (GND), U1.27 (GND), U1.34 (GND), U1.41 (GND), U1.46 (GND), U1.49 (GND), U1.55 (GND), U1.56 (GND), U1.57 (GND), U1.58 (GND), U1.59 (GND), U1.60 (GND), U1.61 (GND), U1.62 (GND), U1.63 (GND), U1.64 (GND), U1.65 (GND), U1.66 (GND), U1.67 (GND), U1.68 (GND), U1.69 (GND), U1.70 (GND), U1.71 (GND), U1.72 (GND), U1.73 (GND), U1.74 (GND), U1.75 (GND), U1.76 (GND), U1.77 (GND), U1.78 (GND), U1.79 (GND), U1.80 (GND), U1.81 (GND), U1.82 (GND), U1.83 (GND), U1.84 (GND), U1.85 (GND), U1.86 (GND), U1.87 (GND), U1.88 (GND), U1.89 (GND), U1.90 (GND), U1.91 (GND), U1.92 (GND), U1.93 (GND), U1.94 (GND), U2.3 (GND), U2.4 (GND), U2.9 (GND), U2.18 (GND), U2.21 (GND)
unnamed: J3.2, R1.1, R2.2
unnamed: REF.1.1 (A), U1.47 (REF_O)
unnamed: REF.1.2 (B), U1.48 (REF_I)
unnamed: RXD.4.1 (A), TXD.1.1 (A), TXD.2.1 (A), U2.8 (UART2_RX)
unnamed: L1.2, U1.54 (VANT)
unnamed: U1.50 (VREF_I), VREF.1.2 (B)
unnamed: U1.51 (VREF_O), VREF.1.1 (A)
unnamed: BOOT.1.1, U2.1 (BOOT)
unnamed: GPIO.1.1, U2.5 (GPIO)
PPS1: J1.2, U1.42 (PPS1), U2.15 (1PPS)
PPS2: J1.4, U1.43 (PPS2)
PVT_LED: J1.9, U1.52 (GPIO1)
RTK_LED: J1.7, U1.53 (GPIO2)
RTS2: J3.9, U1.26 (RTS2)
RXD1: J3.19, U1.9 (RXD1)
RXD2: J3.12, U1.29 (RXD2)
RXD3: J3.8, U2.17 (UART1_RX)
RXD4: J3.13, RXD.4.2 (B)
TXD1: J3.15, TXD.1.2 (B), U1.10 (TXD1)
TXD2: J3.10, TXD.2.2 (B), U1.25 (TXD2)
TXD3: J3.6, U2.16 (UART1_TX)
TXD4: J3.11, U2.7 (UART2_TX)
USB_D+: J1.17, U1.12 (USB_DP)
USB_D-: J1.15, U1.13 (USB_DN)
VUSB: J1.19, U1.14 (USB_VBUS)
~RESET: J3.16, U1.7 (~RST_IN), U2.2 (~RST)

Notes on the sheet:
10MHz
Configure jumpers to select the source of the location data
Option: IMU - IM19
IM19 requires GPGGA, GPRMC and GPGST from GNSS at >= 5Hz
Antenna
GPIO pin: Status buzzer
Connectors
Default UART baud rate: 115200
GNSS - mosaic-G5 P3
BOOT pin at startup: Low / Open: normal mode High: BOOT mode
Microstrip (Coplanar Single Ended) 50Ω Calculation: https://jlcpcb.com/pcb-impedance-calculator Board thickness: 1.6mm. Layers: 4. Er: 4.4 (7628 Prepreg) Dielectric Thickness (Layer 1 to 2): 8.28mil/0.2104mm (JLC7628) Copper Thickness (1oz outer / 0.5oz inner): 1.38mil/0.035mm Polygon Isolation: 7m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

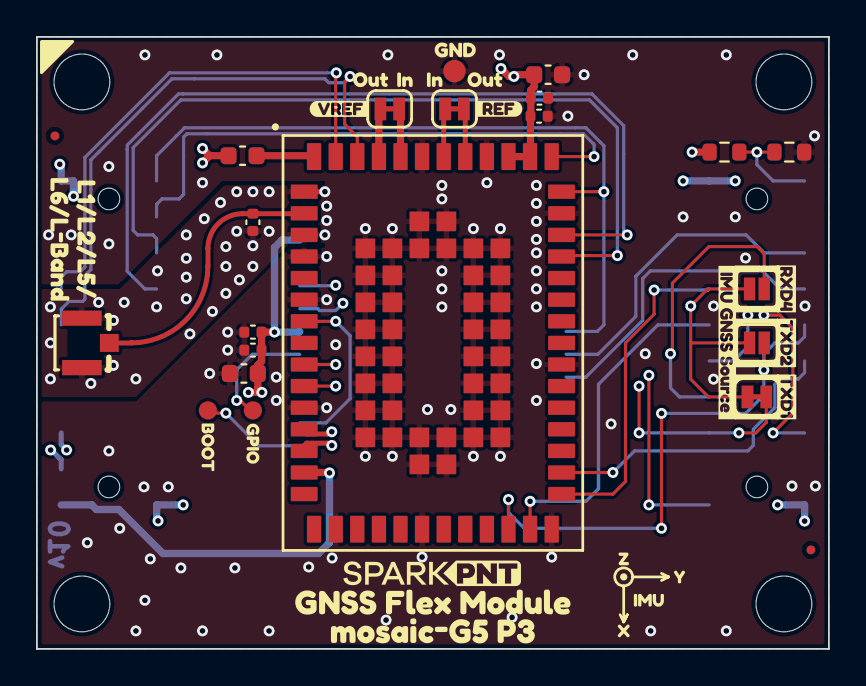
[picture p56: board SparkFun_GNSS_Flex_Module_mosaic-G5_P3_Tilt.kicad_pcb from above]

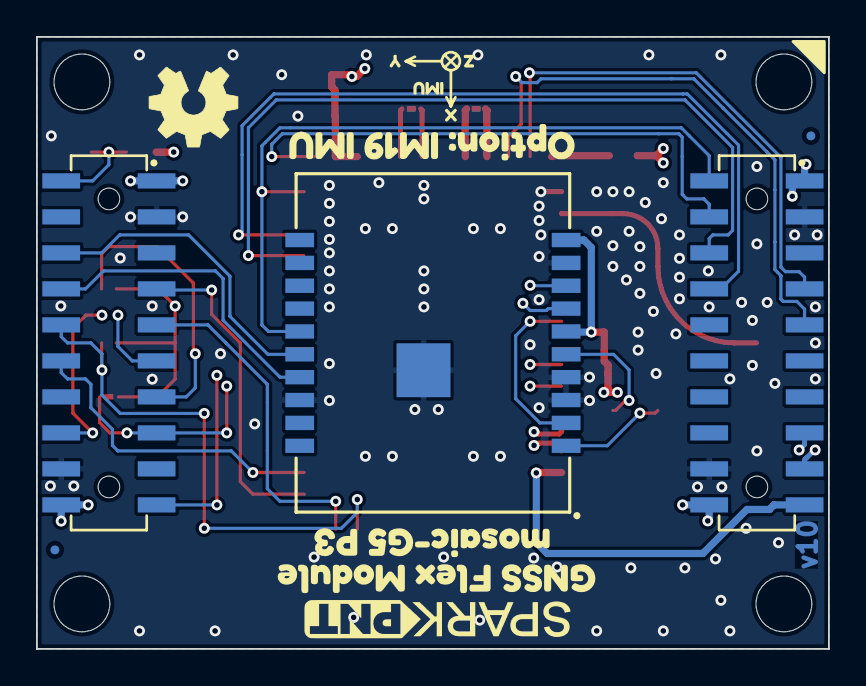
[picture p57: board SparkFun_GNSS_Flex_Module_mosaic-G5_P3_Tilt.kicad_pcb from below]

Board: 4 copper layers, 44.0 x 34.0 mm, 62 parts (13 on the bottom side), 32 nets.

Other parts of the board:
Ref**: Val**; OSHW_Logo_5mm
kibuzzard-67E2880B: G***; kibuzzard-67E2880B
kibuzzard-67F7F23B: G***; kibuzzard-67F7F23B
kibuzzard-67F7F255: G***; kibuzzard-67F7F255
kibuzzard-67FE65EC: G***; kibuzzard-67FE65EC
kibuzzard-67FE65FA: G***; kibuzzard-67FE65FA
kibuzzard-67FE650E: G***; kibuzzard-67FE650E
kibuzzard-67FFA928, kibuzzard-67FFA928#2: G***; kibuzzard-67FFA928
kibuzzard-67FFB45E, kibuzzard-67FFB45E#2: G***; kibuzzard-67FFB45E
kibuzzard-67FFB46A, kibuzzard-67FFB46A#2: G***; kibuzzard-67FFB46A
kibuzzard-67FFB450, kibuzzard-67FFB450#2: G***; kibuzzard-67FFB450
kibuzzard-680AACA4, kibuzzard-680AACA4#2: G***; kibuzzard-680AACA4
kibuzzard-680AACC5, kibuzzard-680AACC5#2: G***; kibuzzard-680AACC5
kibuzzard-680AAD48: G***; kibuzzard-680AAD48
kibuzzard-682D7A50: G***; kibuzzard-682D7A50
kibuzzard-682D7B3E: G***; kibuzzard-682D7B3E
kibuzzard-682D7B5F: G***; kibuzzard-682D7B5F
kibuzzard-682D7B21: G***; kibuzzard-682D7B21
kibuzzard-682DBB5B: G***; kibuzzard-682DBB5B
kibuzzard-682DBB98: G***; kibuzzard-682DBB98
kibuzzard-682DBC4E: G***; kibuzzard-682DBC4E
kibuzzard-68068950: G***; kibuzzard-68068950
kibuzzard-68068962: G***; kibuzzard-68068962

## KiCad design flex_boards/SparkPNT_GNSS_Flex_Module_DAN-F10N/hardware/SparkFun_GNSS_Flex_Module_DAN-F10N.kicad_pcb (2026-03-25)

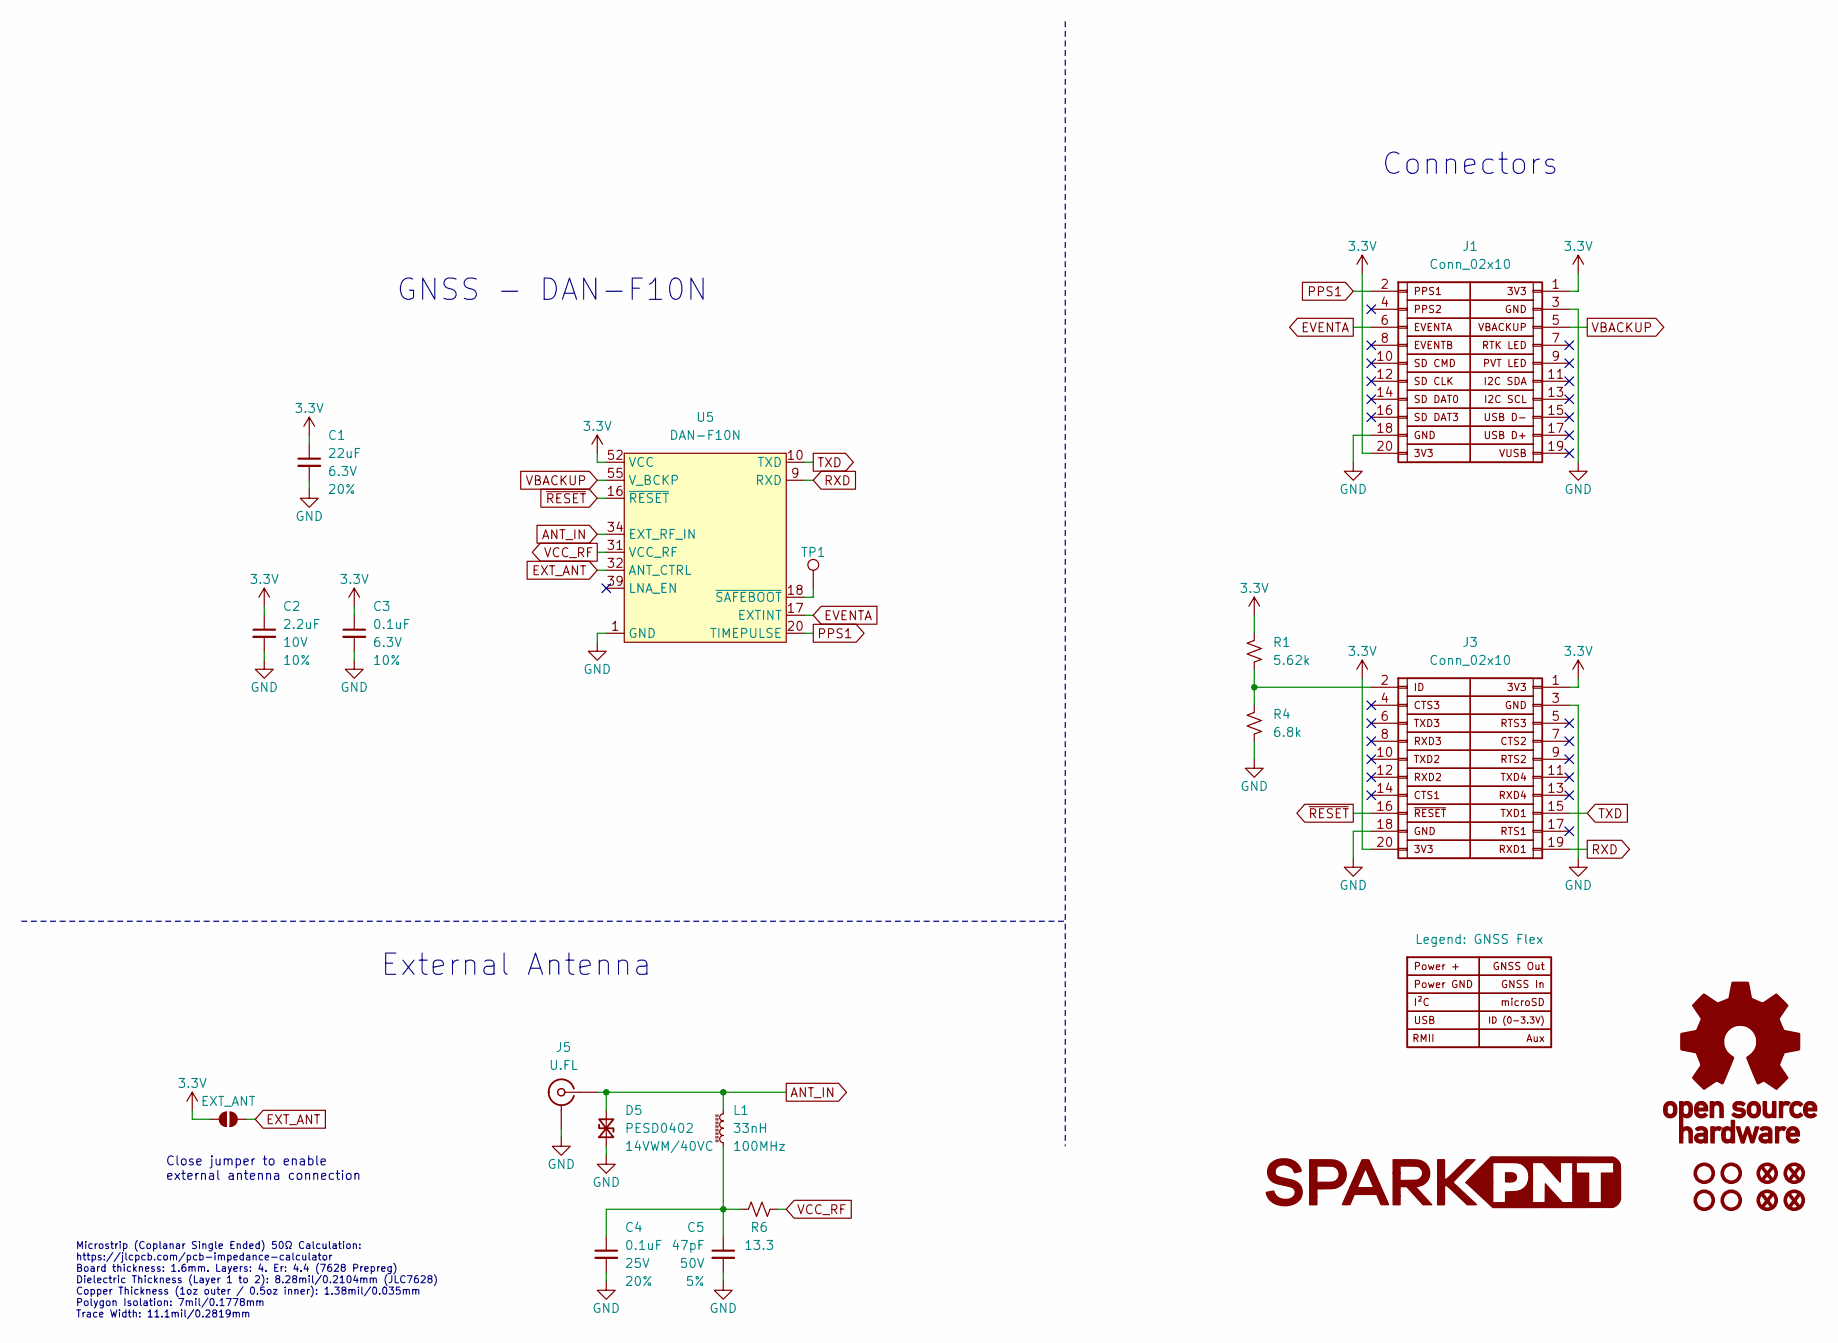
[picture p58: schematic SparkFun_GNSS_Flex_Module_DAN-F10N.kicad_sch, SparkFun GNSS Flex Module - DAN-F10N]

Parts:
C1: 22uF; C_0603_1608Metric; Voltage 6.3V; Tolerance 20%
C2: 2.2uF; C_0402_1005Metric; Voltage 10V; Tolerance 10%
C3: 0.1uF; C_0402_1005Metric; Voltage 6.3V; Tolerance 10%
C4: 0.1uF; C_0603_1608Metric; Voltage 25V; Tolerance 20%
C5: 47pF; C_0603_1608Metric; Voltage 50V; Tolerance 5%
D5: PESD0402; C_0402_1005Metric; Rating 14VWM/40VC
FID1, FID2, FID3, FID4: Fiducial_0.5mm; Fiducial_0.5mm_Mask1mm
G1: LOGO
G3: OSHW_Logo; Creative_Commons_License
J1, J3: Conn_02x10; 2x10_2.0mm_Female_Socket_Vertical_SMD_Pegs
J2: Legend: GNSS Flex; GNSS_Flex_Template
J5: U.FL
JP1: EXT_ANT; Jumper_2_NO
L1: 33nH; C_0603_1608Metric
R1: 5.62k; R_0603_1608Metric
R4: 6.8k; R_0603_1608Metric
R6: 13.3; R_2512_6332Metric
ST1, ST2, ST3, ST4: Standoff
TP1: 1.0mm; TestPoint-1.0mm
U5: DAN-F10N

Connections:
3.3V: C1.1, C2.1, C3.1, J1.1, J1.20, J3.1, J3.20, JP1.1 (A), R1.2, U5.52 (VCC), U5.53 (VCC)
ANT_IN: D5.2 (A2), J5.1 (In), L1.2, U5.34 (EXT_RF_IN)
EVENTA: J1.6, U5.17 (EXTINT)
EXT_ANT: JP1.2 (B), U5.32 (ANT_CTRL)
GND: C1.2, C2.2, C3.2, C4.2, C5.2, D5.1 (A1), J1.3, J1.18, J3.3, J3.18, J5.2 (Ext), R4.1, U5.1 (GND), U5.2 (GND), U5.3 (GND), U5.4 (GND), U5.5 (GND), U5.6 (GND), U5.7 (GND), U5.8 (GND), U5.13 (GND), U5.14 (GND), U5.15 (GND), U5.19 (GND), U5.21 (GND), U5.22 (GND), U5.23 (GND), U5.26 (GND), U5.27 (GND), U5.28 (GND), U5.29 (GND), U5.30 (GND), U5.33 (GND), U5.35 (GND), U5.37 (GND), U5.38 (GND), U5.40 (GND), U5.41 (GND), U5.42 (GND), U5.43 (GND), U5.44 (GND), U5.47 (GND), U5.48 (GND), U5.49 (GND), U5.50 (GND), U5.51 (GND), U5.54 (GND), U5.56 (GND), U5.57 (GND)
unnamed: C4.1, C5.1, L1.1, R6.2
unnamed: J3.2, R1.1, R4.2
unnamed: TP1.1, U5.18 (~SAFEBOOT)
PPS1: J1.2, U5.20 (TIMEPULSE)
RXD: J3.19, U5.9 (RXD)
TXD: J3.15, U5.10 (TXD)
VBACKUP: J1.5, U5.55 (V_BCKP)
VCC_RF: R6.1, U5.31 (VCC_RF)
~RESET: J3.16, U5.16 (~RESET)

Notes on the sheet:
External Antenna
Connectors
GNSS - DAN-F10N
Close jumper to enable external antenna connection
Microstrip (Coplanar Single Ended) 50Ω Calculation: https://jlcpcb.com/pcb-impedance-calculator Board thickness: 1.6mm. Layers: 4. Er: 4.4 (7628 Prepreg) Dielectric Thickness (Layer 1 to 2): 8.28mil/0.2104mm (JLC7628) Copper Thickness (1oz outer / 0.5oz inner): 1.38mil/0.035mm Polygon Isolation: 7m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

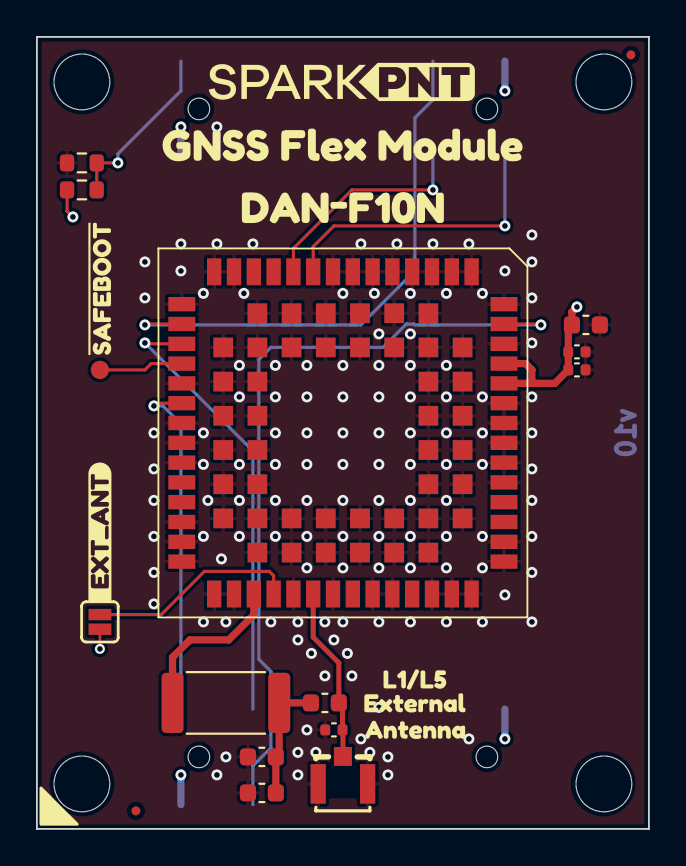
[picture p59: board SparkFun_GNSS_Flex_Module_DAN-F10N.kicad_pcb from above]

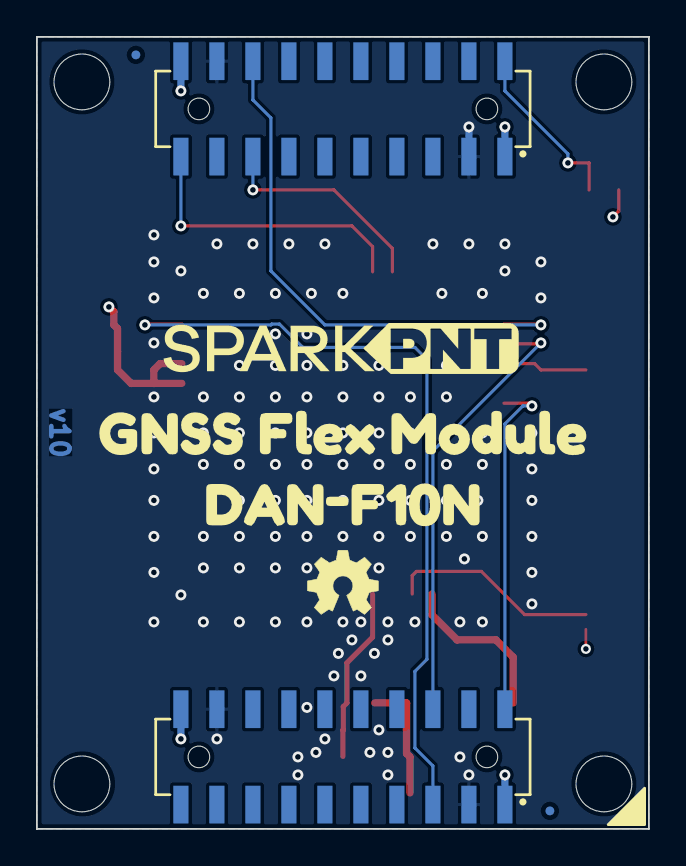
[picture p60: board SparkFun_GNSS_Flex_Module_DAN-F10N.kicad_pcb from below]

Board: 4 copper layers, 34.0 x 44.0 mm, 36 parts (7 on the bottom side), 14 nets.

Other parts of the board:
Ref**: Val**; OSHW_Logo_4mm
kibuzzard-67DC4CF4: G***; kibuzzard-67DC4CF4
kibuzzard-67DC4D0C: G***; kibuzzard-67DC4D0C
kibuzzard-67F5D276: G***; kibuzzard-67F5D276
kibuzzard-67F49BA9: G***; kibuzzard-67F49BA9
kibuzzard-67F49BB0: G***; kibuzzard-67F49BB0
kibuzzard-67F49BC0: G***; kibuzzard-67F49BC0
kibuzzard-67FE95EA: G***; kibuzzard-67FE95EA
kibuzzard-67FE959B: G***; kibuzzard-67FE959B
kibuzzard-67975369: G***; kibuzzard-67975369

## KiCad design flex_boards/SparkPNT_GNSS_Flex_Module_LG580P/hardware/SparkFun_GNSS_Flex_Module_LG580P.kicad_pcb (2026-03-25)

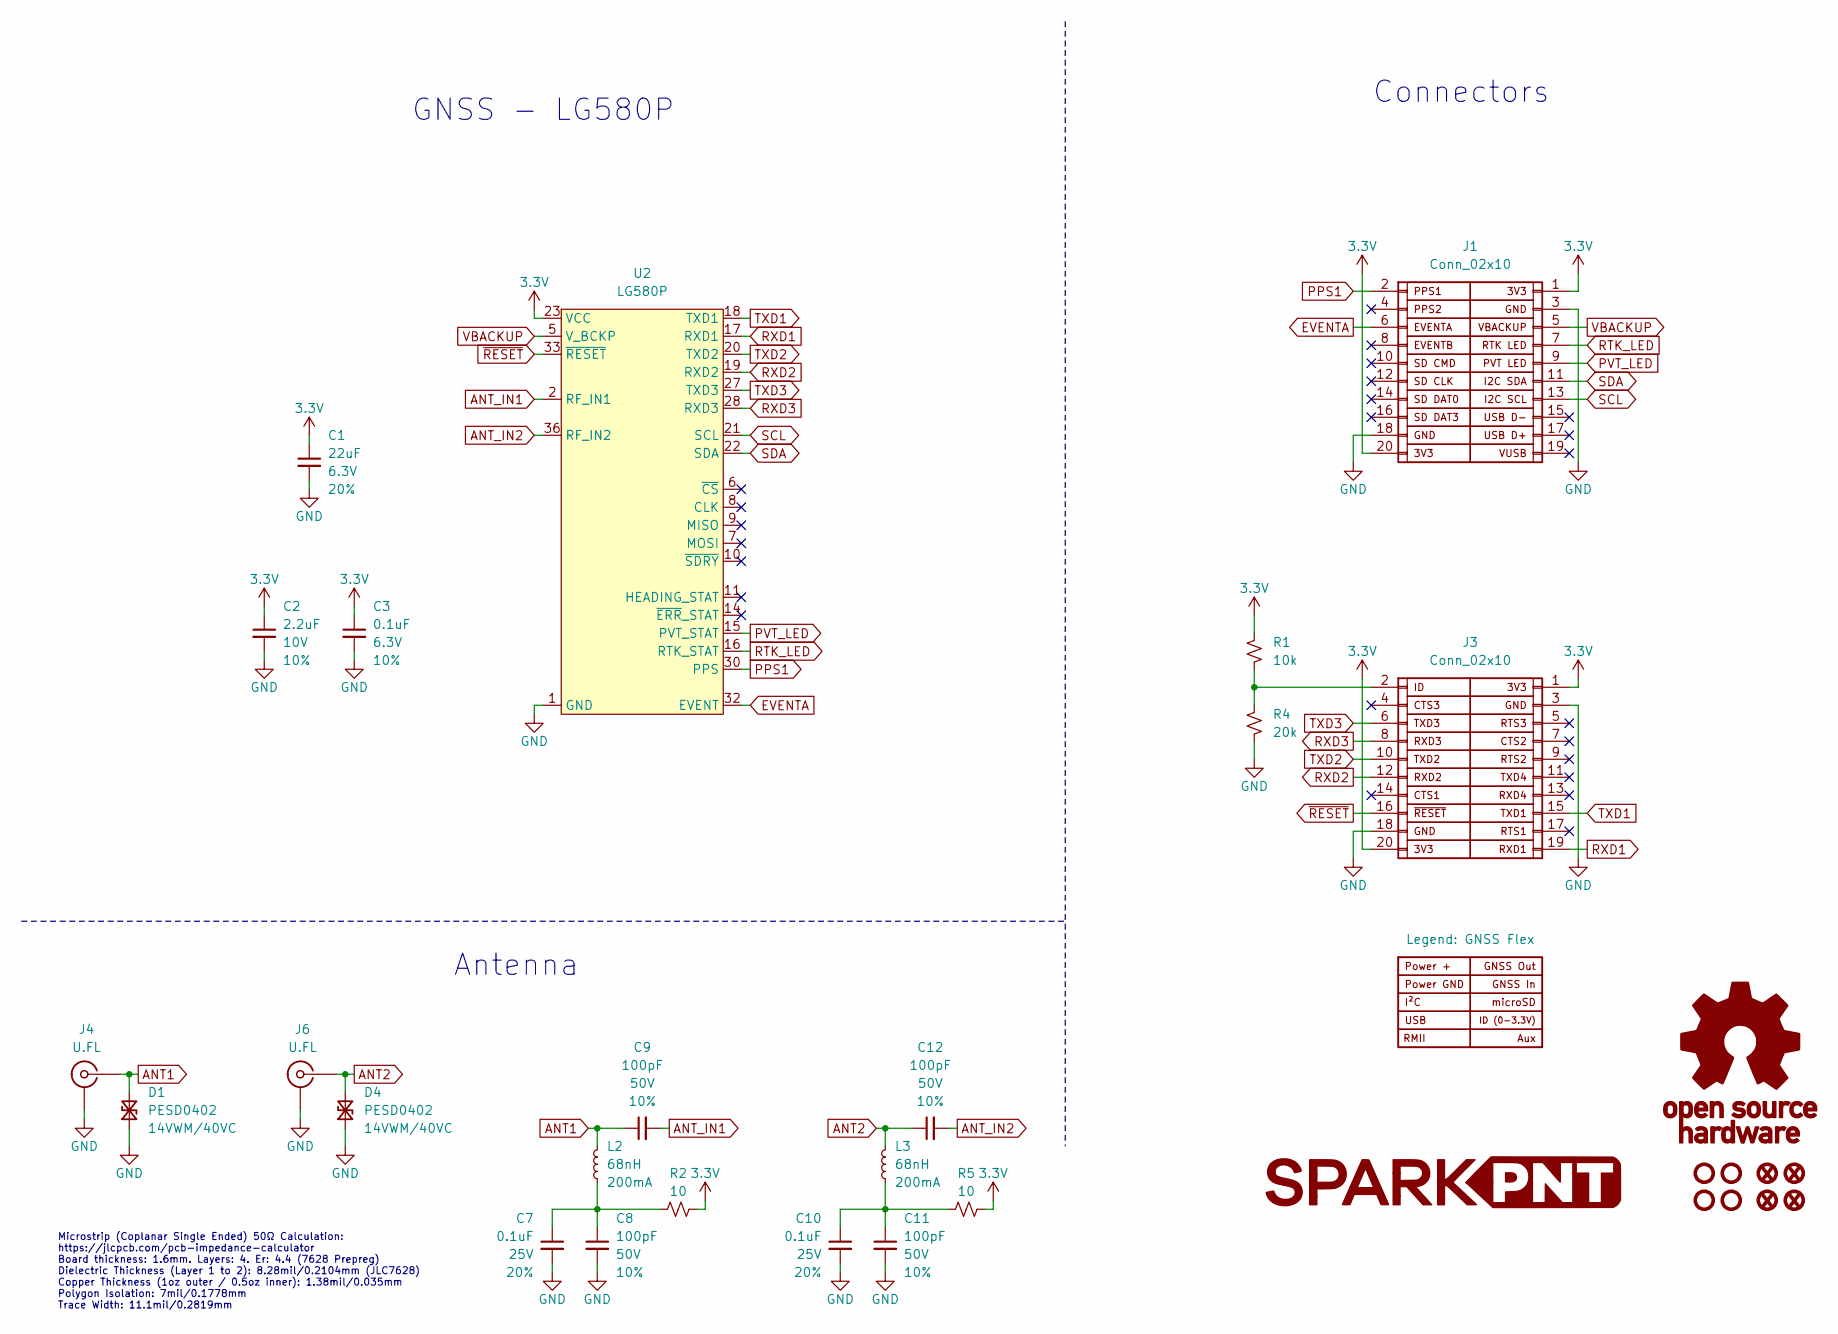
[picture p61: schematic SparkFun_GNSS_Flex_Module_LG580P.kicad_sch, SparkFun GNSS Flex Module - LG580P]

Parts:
C1: 22uF; C_0603_1608Metric; Voltage 6.3V; Tolerance 20%
C2: 2.2uF; C_0402_1005Metric; Voltage 10V; Tolerance 10%
C3: 0.1uF; C_0402_1005Metric; Voltage 6.3V; Tolerance 10%
C7, C10: 0.1uF; C_0603_1608Metric; Voltage 25V; Tolerance 20%
C8, C11: 100pF; C_0603_1608Metric; Voltage 50V; Tolerance 10%
C9, C12: 100pF; C_0402_1005Metric; Voltage 50V; Tolerance 10%
D1, D4: PESD0402; C_0402_1005Metric; Rating 14VWM/40VC
FID1, FID2, FID3, FID4: Fiducial_0.5mm; Fiducial_0.5mm_Mask1mm
G1: LOGO
G3: OSHW_Logo; Creative_Commons_License
J1, J3: Conn_02x10; 2x10_2.0mm_Female_Socket_Vertical_SMD_Pegs
J2: Legend: GNSS Flex; GNSS_Flex_Template
J4, J6: U.FL
L2, L3: 68nH; C_0402_1005Metric
R1: 10k; R_0603_1608Metric
R2, R5: 10; R_0603_1608Metric
R4: 20k; R_0603_1608Metric
ST1, ST2, ST3, ST4: Standoff
U2: LG580P; Quectel_LG580P

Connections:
3.3V: C1.1, C2.1, C3.1, J1.1, J1.20, J3.1, J3.20, R1.2, R2.2, R5.2, U2.23 (VCC), U2.24 (VCC)
ANT1: C9.1, D1.2 (A2), J4.1 (In), L2.2
ANT2: C12.1, D4.2 (A2), J6.1 (In), L3.2
ANT_IN1: C9.2, U2.2 (RF_IN1)
ANT_IN2: C12.2, U2.36 (RF_IN2)
EVENTA: J1.6, U2.32 (EVENT)
GND: C1.2, C2.2, C3.2, C7.2, C8.2, C10.2, C11.2, D1.1 (A1), D4.1 (A1), J1.3, J1.18, J3.3, J3.18, J4.2 (Ext), J6.2 (Ext), R4.1, U2.1 (GND), U2.3 (GND), U2.4 (GND), U2.34 (GND), U2.35 (GND), U2.37 (GND), U2.41 (GND), U2.43 (GND), U2.45 (GND), U2.49 (GND)
unnamed: C7.1, C8.1, L2.1, R2.1
unnamed: C10.1, C11.1, L3.1, R5.1
unnamed: J3.2, R1.1, R4.2
PPS1: J1.2, U2.30 (PPS)
PVT_LED: J1.9, U2.15 (PVT_STAT)
RTK_LED: J1.7, U2.16 (RTK_STAT)
RXD1: J3.19, U2.17 (RXD1)
RXD2: J3.12, U2.19 (RXD2)
RXD3: J3.8, U2.28 (RXD3)
SCL: J1.13, U2.21 (SCL)
SDA: J1.11, U2.22 (SDA)
TXD1: J3.15, U2.18 (TXD1)
TXD2: J3.10, U2.20 (TXD2)
TXD3: J3.6, U2.27 (TXD3)
VBACKUP: J1.5, U2.5 (V_BCKP)
~RESET: J3.16, U2.33 (~RESET)

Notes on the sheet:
Antenna
Connectors
GNSS - LG580P
Microstrip (Coplanar Single Ended) 50Ω Calculation: https://jlcpcb.com/pcb-impedance-calculator Board thickness: 1.6mm. Layers: 4. Er: 4.4 (7628 Prepreg) Dielectric Thickness (Layer 1 to 2): 8.28mil/0.2104mm (JLC7628) Copper Thickness (1oz outer / 0.5oz inner): 1.38mil/0.035mm Polygon Isolation: 7m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

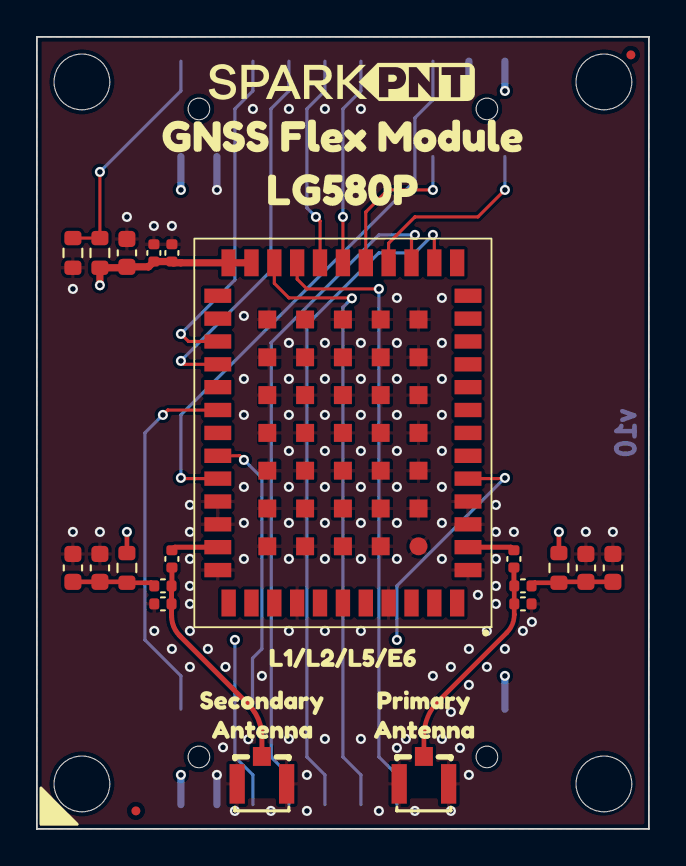
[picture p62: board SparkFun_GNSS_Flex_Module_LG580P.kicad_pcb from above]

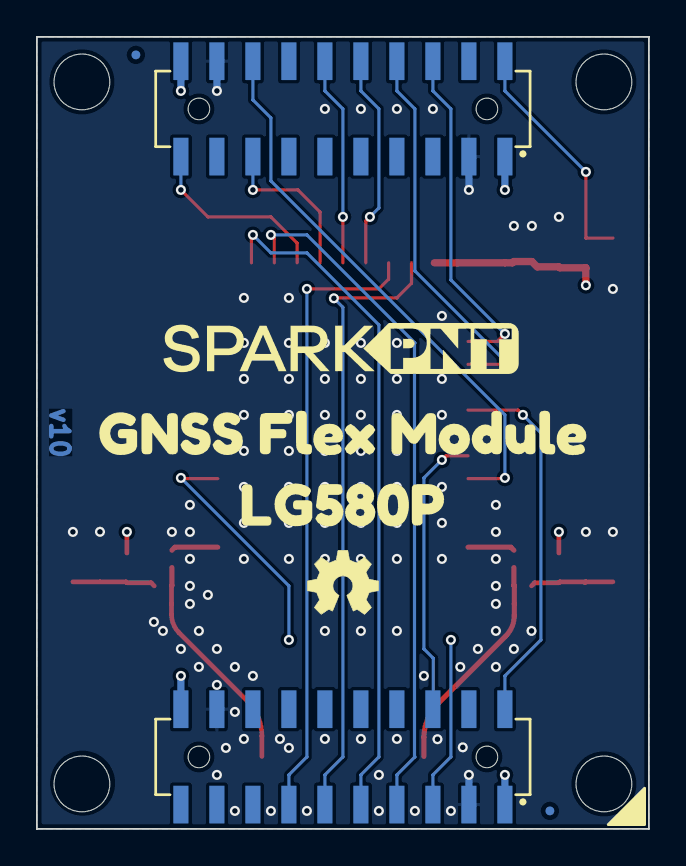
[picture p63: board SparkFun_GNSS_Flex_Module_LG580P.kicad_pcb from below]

Board: 4 copper layers, 34.0 x 44.0 mm, 42 parts (8 on the bottom side), 23 nets.

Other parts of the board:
Ref**: Val**; OSHW_Logo_4mm
kibuzzard-67DC4CF4: G***; kibuzzard-67DC4CF4
kibuzzard-67DC4D0C: G***; kibuzzard-67DC4D0C
kibuzzard-67EC9ED9: G***; kibuzzard-67EC9ED9
kibuzzard-67EC9EE7: G***; kibuzzard-67EC9EE7
kibuzzard-67ECA530: G***; kibuzzard-67ECA530
kibuzzard-67ECA543: G***; kibuzzard-67ECA543
kibuzzard-67975357: G***; kibuzzard-67975357
kibuzzard-67975369, kibuzzard-67975369#2: G***; kibuzzard-67975369

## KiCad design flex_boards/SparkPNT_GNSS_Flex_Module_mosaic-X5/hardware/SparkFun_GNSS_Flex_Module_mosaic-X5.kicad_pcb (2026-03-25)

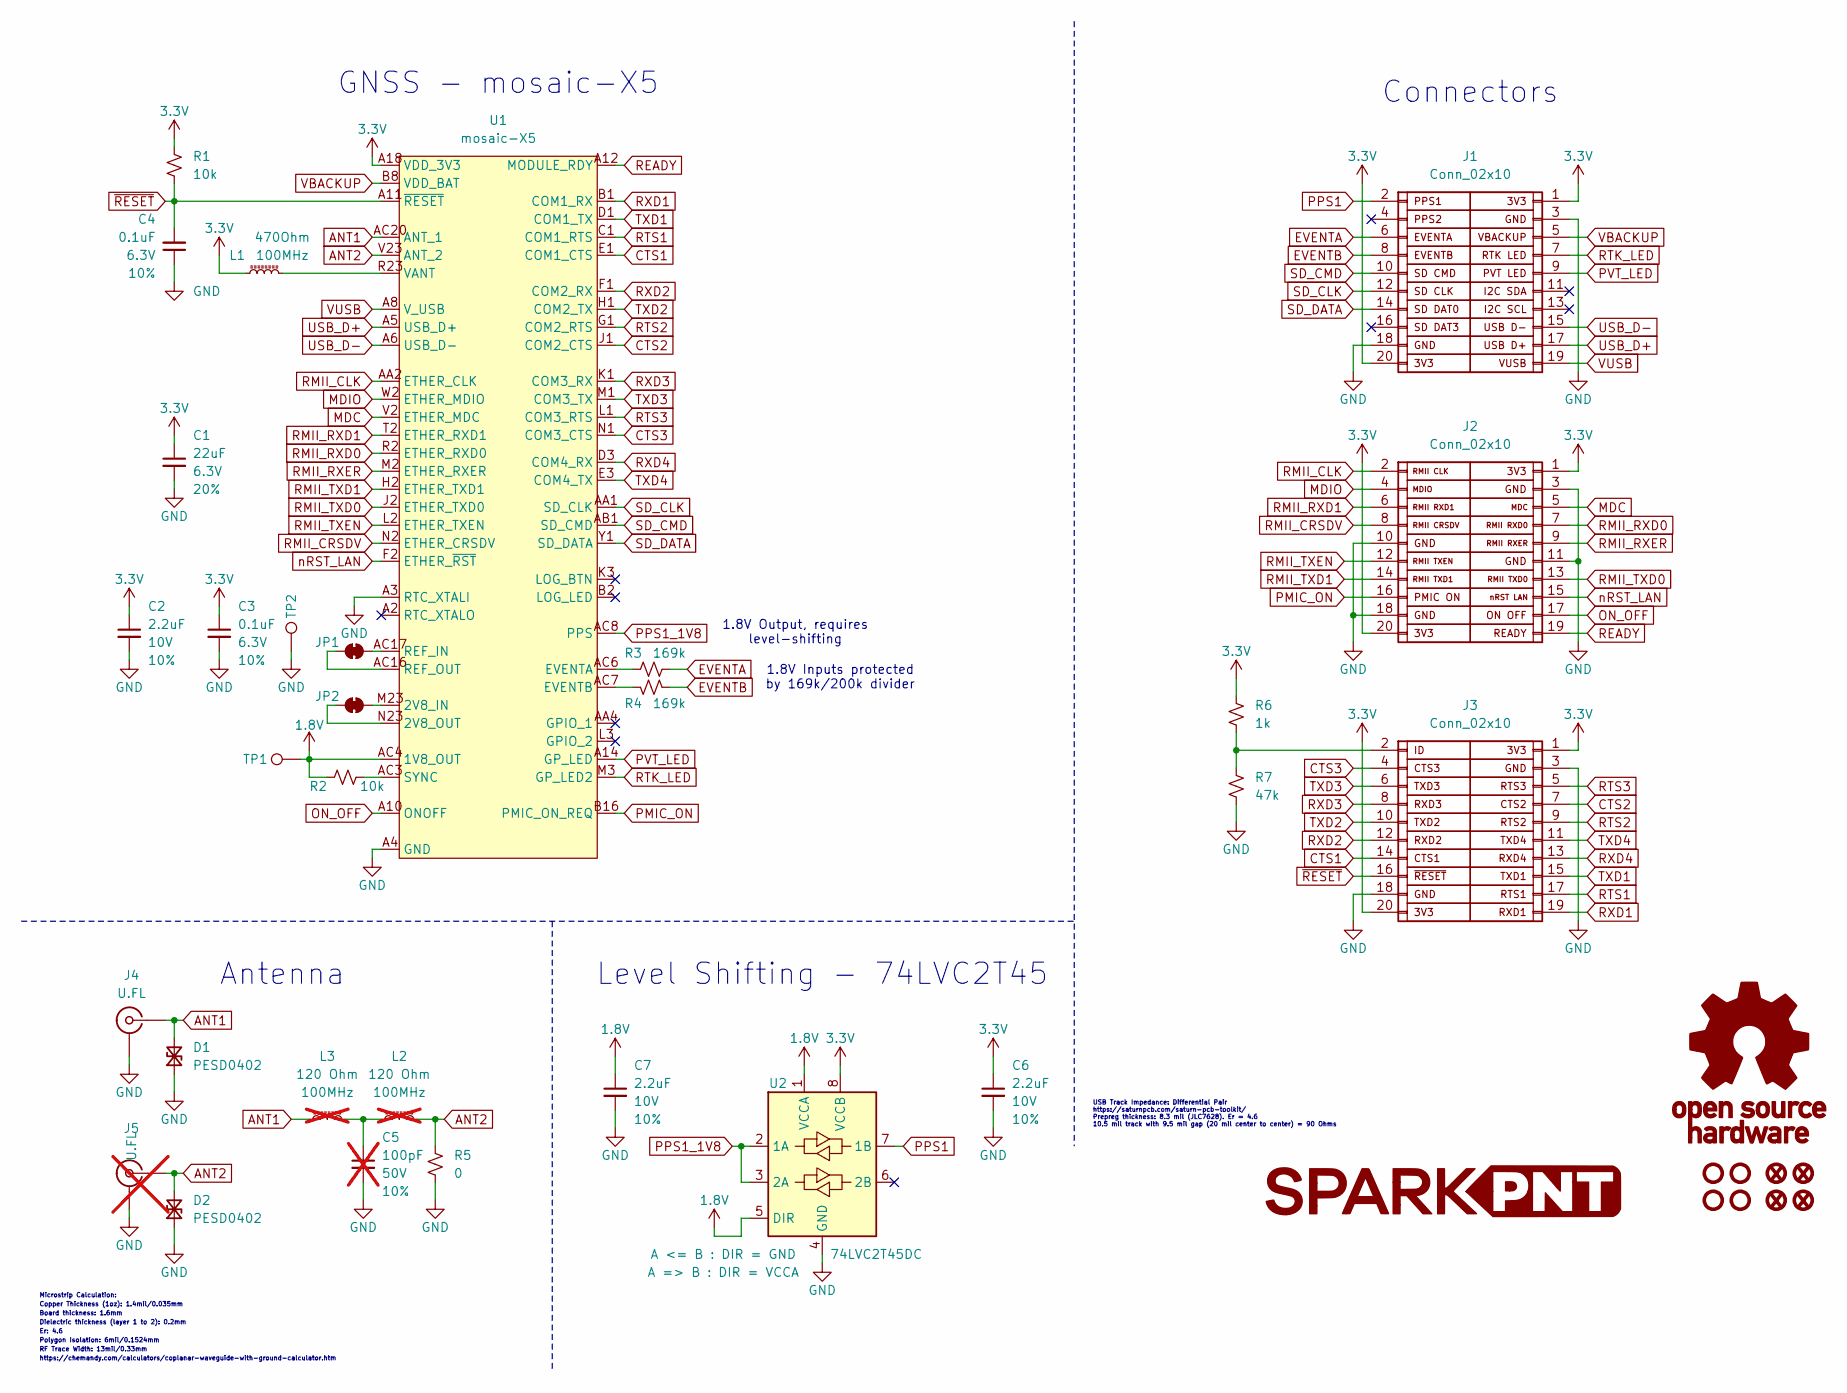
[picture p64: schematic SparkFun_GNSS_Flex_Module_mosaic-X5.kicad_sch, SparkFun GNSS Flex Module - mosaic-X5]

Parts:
C1: 22uF; C_0603_1608Metric; Voltage 6.3V; Tolerance 20%
C2, C6, C7: 2.2uF; C_0402_1005Metric; Voltage 10V; Tolerance 10%
C3, C4: 0.1uF; C_0402_1005Metric; Voltage 6.3V; Tolerance 10%
C5: 100pF; C_0402_1005Metric; Voltage 50V; Tolerance 10%; not fitted
D1, D2: PESD0402; C_0402_1005Metric
FID1, FID2, FID3, FID4: Fiducial_0.5mm; Fiducial_0.5mm_Mask1mm
G1: LOGO
G3: OSHW_Logo; Creative_Commons_License
J1, J2, J3: Conn_02x10; 2x10_2.0mm_Female_Socket_Vertical_SMD_Pegs
J4: U.FL
J5: U.FL; not fitted
JP1, JP2: Jumper_2_NC_Trace
L1: 470Ohm; C_0603_1608Metric
L2, L3: 120 Ohm; C_0402_1005Metric; not fitted
R1, R2: 10k; R_0402_1005Metric
R3, R4: 169k; R_0603_1608Metric
R5: 0; R_0402_1005Metric
R6: 1k; R_0603_1608Metric
R7: 47k; R_0603_1608Metric
ST1, ST2, ST3, ST4: Standoff
TP1, TP2: 1.0mm; TestPoint-1.0mm
U1: mosaic-X5; MOSAIC_LGA
U2: 74LVC2T45DC; VSSOP8_SOT765-1

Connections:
1.8V: C7.1, R2.1, TP1.1, U1.AC4 (1V8_OUT), U2.1 (VCCA), U2.5 (DIR)
3.3V: C1.1, C2.1, C3.1, C6.1, J1.1, J1.20, J2.1, J2.20, J3.1, J3.20, L1.1, R1.2, R6.1, U1.A18 (VDD_3V3), U1.A19 (VDD_3V3), U1.A20 (VDD_3V3), U1.B18 (VDD_3V3), U1.B19 (VDD_3V3), U1.B20 (VDD_3V3), U1.C18 (VDD_3V3), U1.C19 (VDD_3V3), U1.C20 (VDD_3V3), U2.8 (VCCB)
ANT1: D1.2 (A2), J4.1 (In), L3.2, U1.AC20 (ANT_1)
ANT2: D2.2 (A2), J5.1 (In), L2.1, R5.2, U1.V23 (ANT_2)
CTS1: J3.14, U1.E1 (COM1_CTS)
CTS2: J3.7, U1.J1 (COM2_CTS)
CTS3: J3.4, U1.N1 (COM3_CTS)
EVENTA: J1.6, R3.2
EVENTB: J1.8, R4.2
GND: C1.2, C2.2, C3.2, C4.1, C5.2, C6.2, C7.2, D1.1 (A1), D2.1 (A1), J1.3, J1.18, J2.3, J2.10, J2.11, J2.18, J3.3, J3.18, J4.2 (Ext), J5.2 (Ext), R5.1, R7.1, TP2.1, U1.A3 (RTC_XTALI), U1.A4 (GND), U1.A7 (GND), U1.A15 (GND), U1.A16 (GND), U1.A17 (GND), U1.A21 (GND), U1.A22 (GND), U1.A23 (GND), U1.AA13 (GND), U1.AA14 (GND), U1.AA15 (GND), U1.AA16 (GND), U1.AA17 (GND), U1.AA18 (GND), U1.AA19 (GND), U1.AA20 (GND), U1.AA21 (GND), U1.AA22 (GND), U1.AA23 (GND), U1.AB2 (GND), U1.AB3 (GND), U1.AB4 (GND), U1.AB5 (GND), U1.AB6 (GND), U1.AB7 (GND), U1.AB8 (GND), U1.AB13 (GND), U1.AB14 (GND), U1.AB15 (GND), U1.AB16 (GND), U1.AB17 (GND), U1.AB18 (GND), U1.AB19 (GND), U1.AB20 (GND), U1.AB21 (GND), U1.AB22 (GND), U1.AB23 (GND), U1.AC13 (GND), U1.AC15 (GND), U1.AC18 (GND), U1.AC19 (GND), U1.AC21 (GND), U1.AC22 (GND), U1.AC23 (GND), U1.B4 (GND), U1.B5 (GND), U1.B6 (GND), U1.B7 (GND), U1.B13 (GND), U1.B17 (GND), U1.B21 (GND), U1.C4 (GND), U1.C7 (GND), U1.C15 (GND), U1.C16 (GND), U1.C17 (GND), U1.C23 (GND), U1.D2 (GND), U1.D21 (GND), U1.D22 (GND), U1.D23 (GND), U1.E2 (GND), U1.E21 (GND), U1.E22 (GND), U1.E23 (GND), U1.F21 (GND), U1.F22 (GND), U1.F23 (GND), U1.G2 (GND), U1.G21 (GND), U1.G23 (GND), U1.H21 (GND), U1.H22 (GND), U1.H23 (GND), U1.J21 (GND), U1.J22 (GND), U1.J23 (GND), U1.K2 (GND), U1.K21 (GND), U1.K22 (GND), U1.K23 (GND), U1.L21 (GND), U1.L22 (GND), U1.L23 (GND), U1.M21 (GND), U1.M22 (GND), U1.N21 (GND), U1.N22 (GND), U1.P1 (GND), U1.P2 (GND), U1.P3 (GND), U1.P21 (GND), U1.P22 (GND), U1.R3 (GND), U1.R21 (GND), U1.R22 (GND), U1.T21 (GND), U1.T22 (GND), U1.T23 (GND), U1.U2 (GND), U1.U21 (GND), U1.U22 (GND), U1.U23 (GND), U1.V21 (GND), U1.V22 (GND), U1.W21 (GND), U1.W22 (GND), U1.W23 (GND), U1.Y2 (GND), U1.Y21 (GND), U1.Y22 (GND), U1.Y23 (GND), U2.4 (GND)
MDC: J2.5, U1.V2 (ETHER_MDC)
MDIO: J2.4, U1.W2 (ETHER_MDIO)
unnamed: C5.1, L2.2, L3.1
unnamed: J3.2, R6.2, R7.2
unnamed: JP1.1 (A), U1.AC16 (REF_OUT)
unnamed: JP1.2 (B), U1.AC17 (REF_IN)
unnamed: JP2.1 (A), U1.N23 (2V8_OUT)
unnamed: JP2.2 (B), U1.M23 (2V8_IN)
unnamed: R3.1, U1.AC6 (EVENTA)
unnamed: R4.1, U1.AC7 (EVENTB)
unnamed: R2.2, U1.AC3 (SYNC)
ON_OFF: J2.17, U1.A10 (ONOFF)
PMIC_ON: J2.16, U1.B16 (PMIC_ON_REQ)
PPS1: J1.2, U2.7 (1B)
PPS1_1V8: U1.AC8 (PPS), U2.2 (1A), U2.3 (2A)
PVT_LED: J1.9, U1.A14 (GP_LED)
READY: J2.19, U1.A12 (MODULE_RDY)
RMII_CLK: J2.2, U1.AA2 (ETHER_CLK)
RMII_CRSDV: J2.8, U1.N2 (ETHER_CRSDV)
RMII_RXD0: J2.7, U1.R2 (ETHER_RXD0)
RMII_RXD1: J2.6, U1.T2 (ETHER_RXD1)
RMII_RXER: J2.9, U1.M2 (ETHER_RXER)
RMII_TXD0: J2.13, U1.J2 (ETHER_TXD0)
RMII_TXD1: J2.14, U1.H2 (ETHER_TXD1)
RMII_TXEN: J2.12, U1.L2 (ETHER_TXEN)
RTK_LED: J1.7, U1.M3 (GP_LED2)
RTS1: J3.17, U1.C1 (COM1_RTS)
RTS2: J3.9, U1.G1 (COM2_RTS)
RTS3: J3.5, U1.L1 (COM3_RTS)
RXD1: J3.19, U1.B1 (COM1_RX)
RXD2: J3.12, U1.F1 (COM2_RX)
RXD3: J3.8, U1.K1 (COM3_RX)
RXD4: J3.13, U1.D3 (COM4_RX)
SD_CLK: J1.12, U1.AA1 (SD_CLK)
SD_CMD: J1.10, U1.AB1 (SD_CMD)
SD_DATA: J1.14, U1.Y1 (SD_DATA)
TXD1: J3.15, U1.D1 (COM1_TX)
TXD2: J3.10, U1.H1 (COM2_TX)
TXD3: J3.6, U1.M1 (COM3_TX)
TXD4: J3.11, U1.E3 (COM4_TX)
USB_D+: J1.17, U1.A5 (USB_D+)
USB_D-: J1.15, U1.A6 (USB_D-)
VANT: L1.2, U1.P23 (VANT), U1.R23 (VANT)
VBACKUP: J1.5, U1.B8 (VDD_BAT)
VUSB: J1.19, U1.A8 (V_USB)
nRST_LAN: J2.15, U1.F2 (ETHER_~RST)
~RESET: C4.2, J3.16, R1.1, U1.A11 (~RESET)

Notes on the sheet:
Copper Thickness (1oz): 1.4mil/0.035mm
Board thickness: 1.6mm
Er: 4.6
Antenna
Dielectric thickness (layer 1 to 2): 0.2mm
https://chemandy.com/calculators/coplanar-waveguide-with-ground-calculator.htm
USB Track Impedance: Differential Pair https://saturnpcb.com/saturn-pcb-toolkit/ Prepreg thickness: 8.3 mil (JLC7628). Er = 4.6 10.5 mil track with 9.5 mil gap (20 mil center to center) = 90 Ohms
RF Trace Width: 13mil/0.33mm
1.8V Output, requires level-shifting
Connectors
GNSS - mosaic-X5
Microstrip Calculation:
1.8V Inputs protected by 169k/200k divider
Polygon Isolation: 6mil/0.1524mm
Level Shifting - 74LVC2T45

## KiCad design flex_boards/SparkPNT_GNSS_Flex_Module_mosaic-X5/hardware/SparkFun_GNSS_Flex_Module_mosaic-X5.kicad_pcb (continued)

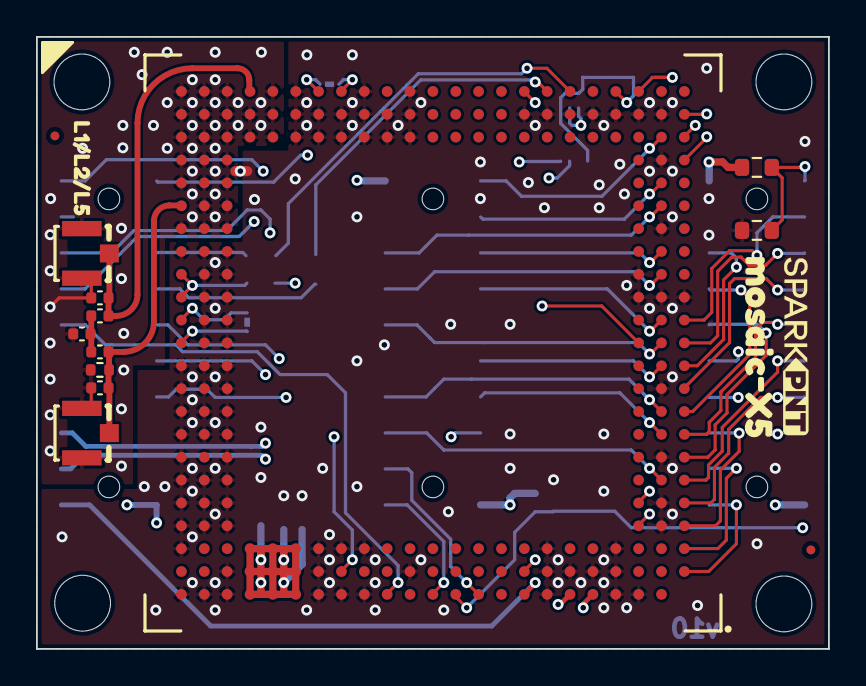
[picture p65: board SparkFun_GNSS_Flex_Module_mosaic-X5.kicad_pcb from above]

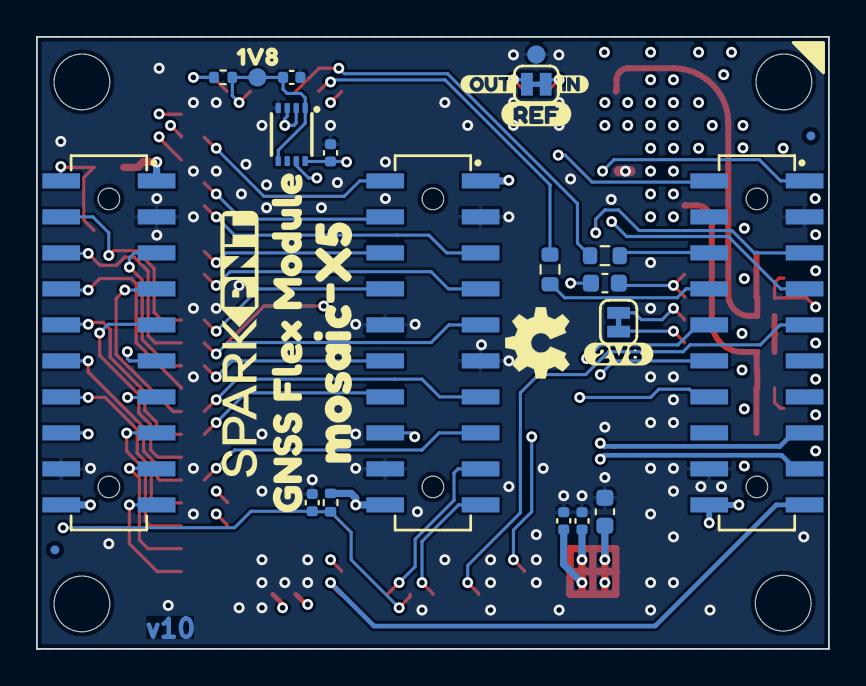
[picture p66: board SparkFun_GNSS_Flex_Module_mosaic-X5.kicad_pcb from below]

Board: 4 copper layers, 44.0 x 34.0 mm, 49 parts (29 on the bottom side), 57 nets.

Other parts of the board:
Ref**: Val**; OSHW_Logo_4mm
kibuzzard-67DC454B: G***; kibuzzard-67DC454B
kibuzzard-67DC4556: G***; kibuzzard-67DC4556
kibuzzard-67DC4600: G***; kibuzzard-67DC4600
kibuzzard-679B2C5E: G***; kibuzzard-679B2C5E
kibuzzard-679B2C8E: G***; kibuzzard-679B2C8E
kibuzzard-679B4D6E: G***; kibuzzard-679B4D6E
kibuzzard-679B4D74: G***; kibuzzard-679B4D74
kibuzzard-6790B939: G***; kibuzzard-6790B939
kibuzzard-6790BA7F: G***; kibuzzard-6790BA7F

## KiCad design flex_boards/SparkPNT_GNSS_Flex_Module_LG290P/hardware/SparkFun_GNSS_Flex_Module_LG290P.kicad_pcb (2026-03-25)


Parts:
C1: 22uF; C_0603_1608Metric; Voltage 6.3V; Tolerance 20%
C2: 2.2uF; C_0402_1005Metric; Voltage 10V; Tolerance 10%
C3: 0.1uF; C_0402_1005Metric; Voltage 6.3V; Tolerance 10%
C4, C6: 100pF; C_0402_1005Metric; Voltage 50V; Tolerance 10%
C5: 0.1uF; C_0402_1005Metric; Voltage 16V; Tolerance 10%
D1: PESD0402; C_0402_1005Metric; Rating 14VWM/40VC
FID1, FID2, FID3, FID4: Fiducial_0.5mm; Fiducial_0.5mm_Mask1mm
G1: LOGO
G3: OSHW_Logo; Creative_Commons_License
J1, J3: Conn_02x10; 2x10_P2.0mm_Socket_Vertical_SMD_Pegs
J4: U.FL
L1: 68nH; C_0402_1005Metric
R1: 10; R_0402_1005Metric
R3: 3.3k; R_0603_1608Metric
R4: 10k; R_0603_1608Metric
ST1, ST2, ST3, ST4: Standoff
U1: LG290P; Quectel_LG290P

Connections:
3.3V: C1.1, C2.1, C3.1, J1.1, J1.20, J3.1, J3.20, R3.2, U1.23 (VCC)
ANT: C4.1, D1.2 (A2), J4.1 (In), L1.2
EVENTA: J1.6, U1.4 (EVENT)
GND: C1.2, C2.2, C3.2, C5.2, C6.2, D1.1 (A1), J1.3, J1.18, J3.3, J3.18, J4.2 (Ext), R4.1, U1.10 (GND), U1.12 (GND), U1.13 (GND), U1.24 (GND), U1.25 (GND)
unnamed: C5.1, C6.1, L1.1, R1.2
unnamed: J3.2, R3.1, R4.2
PPS1: J1.2, U1.3 (PPS)
RF_IN: C4.2, U1.11 (RF_IN)
RTK_LED: J1.7, U1.14 (RTK_STAT)
RXD1: J3.19, U1.21 (RXD1)
RXD2: J3.12, U1.7 (RXD2)
RXD3: J3.8, U1.15 (RXD3)
SCL: J1.13, U1.19 (SCL)
SDA: J1.11, U1.18 (SDA)
TXD1: J3.15, U1.20 (TXD1)
TXD2: J3.10, U1.6 (TXD2)
TXD3: J3.6, U1.16 (TXD3)
VBACKUP: J1.5, U1.22 (V_BCKP)
VCC_RF: R1.1, U1.9 (VCC_RF)
~RESET: J3.16, U1.8 (~RESET)

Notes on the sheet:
Copper Thickness (1oz): 1.4mil/0.035mm
Board thickness: 1.6mm
Er: 4.6
Antenna
Connectors
GNSS - LG290P
https://chemandy.com/calculators/coplanar-waveguide-with-ground-calculator.htm
Microstrip Calculation:
Polygon Isolation: 6mil/0.1524mm
Dielectric thickness (layer 1 to 2): 0.2mm
RF Trace Width: 13mil/0.33mm



Board: 4 copper layers, 44.0 x 34.0 mm, 31 parts (7 on the bottom side), 20 nets.

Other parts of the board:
Ref**: Val**; OSHW_Logo_4mm
kibuzzard-67DC4CF4: G***; kibuzzard-67DC4CF4
kibuzzard-67DC4D0C: G***; kibuzzard-67DC4D0C
kibuzzard-679B60B6: G***; kibuzzard-679B60B6
kibuzzard-679B612D: G***; kibuzzard-679B612D
kibuzzard-67975357: G***; kibuzzard-67975357
kibuzzard-67975369: G***; kibuzzard-67975369

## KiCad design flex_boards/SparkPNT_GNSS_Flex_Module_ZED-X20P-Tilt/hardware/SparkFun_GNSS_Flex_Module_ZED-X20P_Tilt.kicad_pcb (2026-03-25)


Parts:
BOOT.1: 1.0mm; TestPoint-1.0mm
C1, C9: 22uF; C_0603_1608Metric; Voltage 6.3V; Tolerance 20%
C2, C4, C6, C7: 2.2uF; C_0402_1005Metric; Voltage 10V; Tolerance 10%
C3, C10: 0.1uF; C_0402_1005Metric; Voltage 6.3V; Tolerance 10%
C8: 47pF; C_0402_1005Metric; Voltage 500V; Tolerance 10%
D1: PESD0402; C_0402_1005Metric; Rating 14VWM/40VC
FID1, FID2, FID3, FID4: Fiducial_0.5mm; Fiducial_0.5mm_Mask1mm
G1: LOGO
G3: OSHW_Logo; Creative_Commons_License
GPIO.1: 1.0mm; TestPoint-1.0mm
J1, J3: Conn_02x10; 2x10_P2.0mm_Socket_Vertical_SMD_Pegs
J2: Legend: GNSS Flex; GNSS_Flex_Template
J4: U.FL
JP1: Jumper_2_NC_Trace
JP2, JP4: Jumper_2_NO
L1: 470Ohm; C_0603_1608Metric
R2: 10; R_0402_1005Metric
R3: 15k; R_0603_1608Metric
R4: 12.1k; R_0603_1608Metric
ST1, ST2, ST3, ST4: Standoff
TP1: 1.0mm; TestPoint-1.0mm
U1: ZED-X20P; ZED-F9P_F9T_F9R_X20P
U2: IM19
U5: SN74LVC1G14DCK; SOT-353

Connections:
3.3V: C1.1, C2.1, C3.1, C6.1, C7.1, C9.1, C10.1, J1.1, J1.20, J3.1, J3.20, R3.2, U1.33 (VCC), U1.34 (VCC), U1.38 (V_USB), U2.6 (VCC), U2.10 (VCC), U5.5 (VCC)
ANT: D1.2 (A2), J4.1 (In), L1.2, U1.2 (RF_IN)
EVENTA: J1.6, U1.51 (EXTINT)
GND: C1.2, C2.2, C3.2, C4.2, C6.2, C7.2, C8.1, C9.2, C10.2, D1.1 (A1), J1.3, J1.18, J3.3, J3.18, J4.2 (Ext), R4.1, U1.1 (GND), U1.3 (GND), U1.12 (GND), U1.14 (GND), U1.32 (GND), U1.37 (GND), U1.41 (GND), U1.48 (GND), U1.55 (GND), U1.56 (GND), U1.57 (GND), U1.58 (GND), U1.59 (GND), U1.60 (GND), U1.61 (GND), U1.62 (GND), U1.63 (GND), U1.64 (GND), U1.65 (GND), U1.66 (GND), U1.67 (GND), U1.68 (GND), U1.69 (GND), U1.70 (GND), U1.71 (GND), U1.72 (GND), U1.73 (GND), U1.74 (GND), U1.75 (GND), U1.76 (GND), U1.77 (GND), U1.78 (GND), U1.79 (GND), U1.80 (GND), U1.81 (GND), U1.82 (GND), U1.83 (GND), U1.84 (GND), U1.85 (GND), U1.86 (GND), U1.87 (GND), U1.88 (GND), U1.89 (GND), U1.90 (GND), U1.91 (GND), U1.92 (GND), U1.93 (GND), U1.94 (GND), U1.95 (GND), U1.96 (GND), U1.97 (GND), U1.98 (GND), U1.99 (GND), U1.100 (GND), U1.101 (GND), U1.102 (GND), U2.3 (GND), U2.4 (GND), U2.9 (GND), U2.18 (GND), U2.21 (GND), U5.3 (GND)
unnamed: C8.2, L1.1, R2.2
unnamed: J3.2, R3.1, R4.2
unnamed: JP1.1 (A), JP2.1 (A), JP4.1 (A), U2.8 (UART2_RX)
unnamed: TP1.1, U1.50 (~SAFEBOOT)
unnamed: BOOT.1.1, U2.1 (BOOT)
unnamed: GPIO.1.1, U2.5 (GPIO)
PPS1: J1.2, U1.53 (TIMEPULSE), U2.15 (1PPS)
PVT_LED: J1.9, U1.19 (GEO_STAT)
RTK_LED: J1.7, U5.4
RTK_STAT: U1.20 (RTK_STAT), U5.2
RXD1: J3.19, U1.43 (RX1/PICO)
RXD2: J3.12, U1.26 (RX2)
RXD3: J3.8, U2.17 (UART1_RX)
RXD4: J3.13, JP4.2 (B)
SCL: J1.13, U1.45 (SCL/SCK)
SDA: J1.11, U1.44 (SDA/~CS)
TXD1: J3.15, JP1.2 (B), U1.42 (TX1/POCI)
TXD2: J3.10, JP2.2 (B), U1.27 (TX2)
TXD3: J3.6, U2.16 (UART1_TX)
TXD4: J3.11, U2.7 (UART2_TX)
USB_D+: J1.17, U1.40 (USB_D+)
USB_D-: J1.15, U1.39 (USB_D-)
VBACKUP: C4.1, J1.5, U1.36 (V_BCKP)
VCC_RF: R2.1, U1.7 (VCC_RF)
~RESET: J3.16, U1.49 (~RESET), U2.2 (~RST)

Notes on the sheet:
Configure these jumpers to select the source of the location data
Option: IMU - IM19
IM19 requires GPGGA, GPRMC and GPGST from GNSS at >= 5Hz
Antenna
NOTE: the initial version of the ZED-X20P does not support USB
GPIO pin: Status buzzer
No antenna detection
Connectors
Default UART baud rate: 38400
Default I²C address: 0x42 (unshifted)
Requires inversion
GNSS - ZED-X20P
BOOT pin at startup: Low / Open: normal mode High: BOOT mode
No SPI support
Default UART baud rate: 115200
No capacitor should be placed at RESET_N to GND
Microstrip (Coplanar Single Ended) 50Ω Calculation: https://jlcpcb.com/pcb-impedance-calculator Board thickness: 1.6mm. Layers: 4. Er: 4.4 (7628 Prepreg) Dielectric Thickness (Layer 1 to 2): 8.28mil/0.2104mm (JLC7628) Copper Thickness (1oz outer / 0.5oz inner): 1.38mil/0.035mm Polygon Isolation: 7m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
RTK STAT Inversion 74LVC1G14



Board: 4 copper layers, 44.0 x 34.0 mm, 59 parts (13 on the bottom side), 29 nets.

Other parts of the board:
Ref**: Val**; OSHW_Logo_5mm
kibuzzard-67E28C2D: G***; kibuzzard-67E28C2D
kibuzzard-67E2880B: G***; kibuzzard-67E2880B
kibuzzard-67F7F23B: G***; kibuzzard-67F7F23B
kibuzzard-67F7F255: G***; kibuzzard-67F7F255
kibuzzard-67FE65EC: G***; kibuzzard-67FE65EC
kibuzzard-67FE65FA: G***; kibuzzard-67FE65FA
kibuzzard-67FE650E: G***; kibuzzard-67FE650E
kibuzzard-67FFA928, kibuzzard-67FFA928#2: G***; kibuzzard-67FFA928
kibuzzard-67FFB45E, kibuzzard-67FFB45E#2: G***; kibuzzard-67FFB45E
kibuzzard-67FFB46A, kibuzzard-67FFB46A#2: G***; kibuzzard-67FFB46A
kibuzzard-67FFB450, kibuzzard-67FFB450#2: G***; kibuzzard-67FFB450
kibuzzard-682DAEE5: G***; kibuzzard-682DAEE5
kibuzzard-682DAFF9: G***; kibuzzard-682DAFF9
kibuzzard-682DB02A: G***; kibuzzard-682DB02A
kibuzzard-68261DE3: G***; kibuzzard-68261DE3
kibuzzard-68261E9D: G***; kibuzzard-68261E9D
kibuzzard-68261F64: G***; kibuzzard-68261F64
kibuzzard-68261F97: G***; kibuzzard-68261F97

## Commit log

2025-05-15 Initial Draft - Flex System
    [GNSS_Flex-Generic_Module.step]
2025-05-20 Replace center tag
    Replace the use of `<center>` tag for deprecation, as described in issue: https://github.com/squidfunk/mkdocs-material/issues/8163
2025-05-20 Fix CAD model link
2025-05-21 Add board stacking animation
    Animation working, needed to declare `autoplay` attribute
2025-05-21 Update modules section
    Add landing page for modules
    Add product links for each module
    Add hookup guide banner
2025-05-21 Add landing page for carrier boards
2025-05-21 Update system_overview.md
    Changed header to Board Variants
    Resized models
    Revised Ecosystem Boards section to list all Flex boards
2025-05-22 Update kicad_files.zip
    Add project file
2025-08-20 Reconfigure homepage
    Re-establish homepage link to the landing page for the current website; instead of redirecting to sparkfun.com
    Follows standard practice
2025-08-20 Improve CSS and page layout
    - Fix QR code for product links
    - Fix QR code for videos
    - Use grid layout to improve page layout
    - Remove navigation buttons from footer
    - Styling updates
2025-08-20 Add images for Qwiic Connector System
    Add logos and QR code for video
2025-08-21 DAN-F10N - Initial Docs Commit
    Adds documentation for new DAN-F10N GNSS Flex module
    [cad_model.step]
2025-08-21 Update antenna information
    Replaced references of "GPS" with "GNSS"
    Add recommendation to have a clear view of the sky
2025-08-23 Update antenna information
    Replaced reference of "GPS" with "GNSS"
2025-09-04 Update docs formatting
    Replaced HTML superscript tags with Markdown-style caret notation for I2C references
2025-09-08 Fix 3D models
    Update camera angle for 3D models to be the same across the entire doc
    Update camera alignment/target so that boards line up evenly
    Restore/update 3D model poster images
    Update model-viewer to v4.0.0
    Disable navigation.instant mkdocs feature, which was causing the embedded model-viewer library to fail
2025-09-08 Update docs
    Added tips for GNSS antenna use
    Clarified voltage injection information
    Updated arduino_library.png image
2025-09-09 Add GNSS Flex module docs - LG290P & IMU
    Files to add a hookup guide for the SparkPNT GNSS Flex Module - LG290P & IMU
    [cad_model.step]
2025-09-09 Add GNSS Flex module docs - ZED-X20P & IMU
    Files to add a hookup guide for the SparkPNT GNSS Flex Module - ZED-X20P & IMU (optional)
    [cad_model.step]
2025-09-09 Add new GNSS Flex modules to docs
    Update product listings and resources
    Expanded documentation to include the new GNSS Flex modules:
    - ZED-X20P with optional IMU
    - LG290P with IMU
2025-09-09 Update image for PyGPSClient
    Updated the pygpsclient UART settings images for DAN-F10N, LG290P-Tilt, LG290P, and ZED-X20P-Tilt modules
2025-09-09 Update KiCAD files
    Files with update footprint paths and orientation
2025-09-09 Update ZED-X20P component documentation
    Removing pre-release documents
    Adding current component documentation for archiving purposes
2025-09-12 Update KiCAD files
    Update the file paths for the 3D model footprints
2025-09-16 Update docs
    Update releases
    Link GNSS Flex breakout into system overview
    Replace <center> and <sup> tags
    Fix links
    Add instructional video
    Update antenna and software instructions
2025-09-18 Update docs
    Update KiCAD files with proper filepaths and/or alignment for the 3D model of the GNSS modules
    Update/add assembly photos
    Add more instructions for RxTools software
    Add template image for the pinouts of the Flex headers
2025-10-10 Add GNSS Flex module docs - LG580P
    Files to add a hookup guide for the SparkPNT GNSS Flex Module - LG580P
    [cad_model.step]
2025-10-10 Update 3D models
    Refactored the 3D models for all the GNSS Flex boards to a new standardization
    Eliminated the manual adjustments required for any new 3D models
    - Modified the old models, so any new models can be adopted without any changes after they have been optimized
2025-10-10 Update 3d-color_adjust.js
    Update the material index for color adjustment in 3D model viewer for refactored 3D models
2025-10-10 Update GNSS Headers section of all Quectel boards
    Standardized the GNSS Header section layout
    Updated the UART protocol information
    - Adds the QGC protocol support details and message lists
    - Adds the qgc_protocol.png image
    - Updated UART protocol sections to include the expanded message types
2025-10-10 Add image for reset pin
2025-10-17 Add GNSS Flex module docs - mosaic-X5 & IM19
    Files to add a hookup guide for the SparkPNT GNSS Flex Module - mosaic-X5 & IM19
    [cad_model.step]
2025-10-30 Update generic models
    Fixes render of material layers
2025-10-30 Update GNSS Flex documentation and hardware overviews
    Clarified the GNSS Flex system description
    Improved IMU tilt compensation for the LG290P-Tilt module
    mosaic-X5 Tilt module:
    - Added entries for the product comparison
    - Added board dimensions
    - Revised antenna recommendations and warnings
2026-02-25 Docs - G5 Update
    Adds docs for moasic-G5 P3 Flex modules
    [cad_model.step]
2026-02-25 Update workflow
    Fixes webpage build for mkdocs-material
2026-03-25 Add KiCad files
    Adds KiCad files to the /hardware and /hardware/production directories of each GNSS Flex module
    [SparkFun_GNSS_Flex_Module_DAN-F10N.kicad_pcb, SparkFun_GNSS_Flex_Module_DAN-F10N.kicad_sch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]
2026-03-25 Add dimensions and schematics
    Includes additional Dimentions.png and Schematic.pdf files to the /hardware directories
2026-03-25 Fix product link
    Updates the product link for LG290P GNSS Flex module w/ IMU

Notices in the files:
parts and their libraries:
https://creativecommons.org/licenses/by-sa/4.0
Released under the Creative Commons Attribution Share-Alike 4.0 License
